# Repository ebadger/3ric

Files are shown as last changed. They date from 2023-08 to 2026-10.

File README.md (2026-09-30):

<h1 align="center">3ric</h1>

<p align="center">
  <strong>A from-scratch, Apple-II-class 65C02 personal computer — real hardware plus a
  cycle-honest emulator that also runs in your browser.</strong>
</p>

<p align="center">
  
  
  
  
  
  
  
</p>

---

## ▶ Try it now — no install, no account

**[Built from Bits: the Hackaday showcase](https://ebadger.github.io/3ric/hackaday.html)**
is a one-minute tour of the machine: a hi-res starfield, 16-color plasma, a rotating
wireframe, and an original six-voice stereo chiptune, all running as real 65C02 code.
[Run and remix the demo](https://ebadger.github.io/3ric/index.html?src=programs/hackaday.s)
at **1x**, then click the emulator for sound. Use **1-4** for scenes, **Space** to pause,
**M** to mute, and **Q/Esc** to return to the monitor. Source and `.PRG` / `.woz`
exports are available in the editor; the program targets 3RIC, not an unmodified Apple II.

**<https://ebadger.github.io/3ric/>** runs the *entire machine* client-side via
WebAssembly. Click the canvas and start typing at the monitor `*` prompt. Then:

- **Boot Disk** — boot the demo 5.25″ floppy (a self-booting machine-code disk).
- **Mount SD** — mount the micro-SD card and use the ROM's DOS shell (`DIR`, etc.).
- **Assemble & Run** — open the built-in 65C02 editor, write assembly, and run it like
  `BRUN` — all in the browser. Programs are shareable via a `?src=` deep link.

<!-- TODO(media): drop an animated GIF of the emulator booting + a program running here,
     e.g. ![3ric booting](docs/media/hero.gif). Keep it < ~5 MB for fast README loads. -->

## What is 3ric?

3ric is a personal *learn-by-building* project: an 8-bit computer designed at the chip level
— KiCad schematics, a custom PCB, and 74-series address-decode logic — paired with a C++
emulator of the exact same machine. The emulator compiles to WebAssembly, so the **same VM
core** that models the real hardware also boots the unmodified 512 KB ROM in any browser.
The whole journey is documented in a [YouTube build series][youtube].

> **Why it exists:** to understand, build, document, and demonstrate how an Apple-II-class
> computer works end to end — and to let anyone poke at it with zero friction. See
> [`docs/MISSION.md`](docs/MISSION.md).

## Features

- **65C02 CPU** with a faithful memory map and soft switches, adjustable clock speed.
- **Video**: 40×24 text, lo-res, and hi-res color, rendered to a canvas.
- **Input & I/O**: keyboard (`$C000`/`$C010`), 6551-style ACIA serial, 6522 VIA.
- **Disk II 5.25″ floppy** via `.woz` images (self-booting machine-code disks).
- **Micro-SD storage**: a bit-banged SPI FAT32 card with a ROM DOS shell.
- **In-browser 65C02 assembler/editor** — assemble & run, download a `.PRG`, share `?src=`
  links; ships ~11 sample programs.
- **AI-generated 6502 games** (STAR DUEL, Snake, Life, Minesweeper, 2048, Star Swarm, and more) built
  through the project's own codegen pipeline — see [`emulator/AICodeGen/`](emulator/AICodeGen/).
- **Runs everywhere the same way**: one shared C++ VM core drives both the native Windows
  build and the browser (WebAssembly) build.

## Write your first program in the browser

1. Open the [live emulator][demo] and pick a sample from the editor's program menu.
2. Edit the assembly, hit **Assemble & Run**, and watch it execute on the machine.
3. Use **Download .PRG** to save it, or copy the `?src=` link to share the exact program.

Prebuilt samples live in [`web/programs/`](web/programs/); their source and design notes
are under [`emulator/AICodeGen/`](emulator/AICodeGen/) and [`codegen/`](codegen/).

## Build from source

Full, current instructions are in [`status/SYSTEM-STATUS.md`](status/SYSTEM-STATUS.md).

**Native emulator (Windows):** open `emulator/Badger6502VM.sln` in Visual Studio 2022 and
build/run the `Console` or WinUI (`Badger6502Emulator`) host.

**Browser / WebAssembly build** (emsdk 6.0.1, Node, Python 3):

```powershell
pwsh web/build.ps1     # Emscripten -> web/badger6502.js + .wasm, stages data/
pwsh web/serve.ps1     # serves http://localhost:8011/index.html
```

**Verify it's healthy** (headless smoke tests — no WASM build needed for the first one):

```powershell
$node = "C:\Users\ebadger\emsdk\node\22.16.0_64bit\bin\node.exe"
& $node codegen/tools/asm6502.test.mjs   # assembler encoding tests
& $node web/test_boot.cjs                # ROM boots to a sane state
```

## How it works

```mermaid
flowchart TD
    ROM["6502 ROM + software<br/>(badger6502.bin, fontrom.dat, .s / .prg)"]
    VM["Emulator core — 65C02 VM in C++<br/>(WozLib floppy · MockMicroSD · video/keyboard/ACIA/VIA)"]
    NATIVE["Native hosts<br/>(Windows / Console)"]
    WASM["Emscripten bridge → WebAssembly"]
    BROWSER["Browser client (index.html)<br/>→ GitHub Pages"]
    CODEGEN["Codegen<br/>(asm6502 + headless harness)"]
    HW["Hardware<br/>(KiCad · 74-series logic · logisim)"]

    ROM --> VM
    VM --> NATIVE
    VM --> WASM --> BROWSER
    CODEGEN -->|assembles & tests on the same VM| VM
    HW -. mirrors the same memory map .-> VM
```

The **memory map is a shared contract**: `emulator/Badger6502VMLib/vm.h` is mirrored by the
hardware decode schematic, the web bridge, and the codegen platform reference. The architecture and
each layer are documented in [`specs/`](specs/) — start with
[`specs/SYSTEM.md`](specs/SYSTEM.md).

## Repository layout

| Path | What's there |
|---|---|
| [`emulator/`](emulator/) | C++ 65C02 VM core, WozLib, MockMicroSD, native hosts, ROM data, AI codegen programs |
| [`web/`](web/) | Emscripten bridge, browser client, in-browser assembler, Pages build/deploy |
| [`codegen/`](codegen/) | `asm6502` assembler, `run6502`/harness, platform-ref generation |
| [`specs/`](specs/) | Layer specifications (the source of truth — specs before code) |
| [`status/`](status/) | How to build/run/verify; current state and known gaps |
| [`docs/`](docs/) | Mission, workflow rules & learnings, roles |
| [`kicad/`](kicad/), [`logisim/`](logisim/), [`diylayout/`](diylayout/), [`schematic_pdf/`](schematic_pdf/) | Hardware: schematics, PCB, 74-series address decode, digital-logic models |
| [`22v10/`](22v10/) | Historical intermediate GAL experiments; replaced by 74-series logic in the final build |
| [`romgen/`](romgen/), [`scripts/`](scripts/), [`test/`](test/) | ROM assembly tooling, dev/CI scripts, tests |

## Known gaps

- **DOS 3.3 / Applesoft disks don't run.** This clone's `$E000` BASIC is generic Microsoft
  BASIC, not Applesoft, so games that chain through an Applesoft auto-run greeting won't
  boot. Self-booting machine-code disks work.

## Contributing

Contributions and experiments are welcome — especially new 6502 programs for the gallery.

**Add a program (the easy path).** No C++, no local build: have an AI coding tool write a
65C02 program by pointing it at [`llms.txt`](https://ebadger.github.io/3ric/llms.txt), test it
in the [browser editor][demo], and open a one-file pull request to the
[Community Gallery](https://ebadger.github.io/3ric/gallery.html). Step-by-step, with a
copy-paste prompt: **[`CONTRIBUTING.md`](CONTRIBUTING.md)**.

**Change the machine itself.** A few house rules keep it trustworthy:

- **Specs before code.** Update the relevant spec in [`specs/`](specs/) in the same change.
- **Trace every layer** a change touches (ROM/software → C++ VM core → web bridge/WASM), and
  keep the **native and browser builds behavior-identical**.
- **Open a PR** — changes land via pull request, not direct pushes to `main`.

The full workflow rules live in [`docs/LEARNINGS.md`](docs/LEARNINGS.md); bug reports use the
templates under [`.github/ISSUE_TEMPLATE/`](.github/ISSUE_TEMPLATE/).

## The build series

3ric is built in public. Watch the design and construction, episode by episode:
**[YouTube build series][youtube]**.

The [porting logs](docs/porting-logs/README.md) tell the software side of that story:
A2Robots, Spy vs Spy, Spy Hunter, and Pitfall II, with the changes, failed experiments,
hardware evidence, and lessons for future sessions.

## Support

If this project helps you learn or you just enjoy the build, please consider
**[sponsoring it on GitHub][sponsor]** — or use the **Sponsor** button at the top of this
repository (see [`.github/FUNDING.yml`](.github/FUNDING.yml)). Sponsorship funds parts,
boards, and more build videos, and **every sponsor is credited in
[`BACKERS.md`](BACKERS.md)**.

## License

3ric is **dual-licensed**:

- **Software** — [MIT](LICENSE).
- **Hardware designs & documentation** — [Creative Commons Attribution-ShareAlike 4.0
  International](LICENSE-CC-BY-SA-4.0.txt).

Bundled third-party components keep their own licenses, and some bundled data (the ROM's
Microsoft BASIC, Apple II disk images used as test fixtures) is third-party copyrighted
material **not** licensed by this project. See [`NOTICE`](NOTICE) for the full breakdown
before redistributing.

[demo]: https://ebadger.github.io/3ric/
[youtube]: https://www.youtube.com/playlist?list=PLbYLt1iawSBLK4w46Kn7cxxuoeVt7Zepq
[sponsor]: https://github.com/sponsors/ebadger

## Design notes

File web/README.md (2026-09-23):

# 3RIC Studio — 65C02 emulator and editor in the browser (WebAssembly)

This folder powers **3RIC Studio**, the browser-based emulator, editor, gallery, and
learning hub for the `3RIC` Apple-II-class 65C02 computer. It compiles the existing C++
VM core
(`emulator/Badger6502VMLib`) and disk library (`emulator/WozLib`) to WebAssembly,
boots the real 512KB ROM, renders Apple-II text/hi-res/lo-res video to an HTML
`<canvas>`, feeds keyboard and gamepad input through the machine's hardware paths,
and plays both the `$C030` system speaker and slot-4 dual-AY Mockingboard through
Web Audio.

The VM peripherals remain in the shared C++ core so native and WASM builds behave
identically. Browser-only presentation code stays in the bridge and JavaScript.

## What works

- Boots the unmodified `badger6502.bin` ROM to the monitor.
- Hi-res color, lo-res color, and 40×24 text rendering — ported verbatim from
  the WinUI host renderer (`MainWindow.xaml.cpp`) into the bridge so the color /
  fringe logic is identical.
- Keyboard input via the Apple-II `$C000` / `$C010` strobe mechanism, including a
  collapsible touch keyboard matching the 1983 Apple IIe layout (minus Reset and
  both Apple keys) for phones.
- **Two gamepads** through the standard browser Gamepad API. USB and Bluetooth
  devices use the same path after OS pairing; the shared VM serializes them as real
  SNES pads through VIA1 and the unmodified ROM fills `GAMEPAD1/2`.
- **Micro-SD card** (bit-banged SPI through VIA1) backing a FAT32 disk image. A
  **Mount SD** button drops into the ROM's DOS shell (`>` prompt) and lists the
  card; from there `DIR`, `CAT`, `CD <dir>`, `BLOAD`/`BRUN <file>` all work.
- **Disk II 5.25″ floppy** emulation (WozLib) through the standard boot ROM at
  `$C600`. A **Boot Disk** button boots the bundled `.woz`, and **Insert .woz…**
  boots any WOZ image you pick. Self-booting machine-code game disks run into
  their hi-res title; DOS 3.3 / Quick-DOS disks don't (this clone has no
  Applesoft for their auto-run greeting — see below).
- **Adjustable CPU clock** (**Speed** selector): 0.5× / 1× (≈1.57 MHz, native) /
  2× / 4× / 8× / Max, with a per-frame wall-clock cap so the page stays responsive.
- **3RIC audio**: the mono `$C030` system speaker is centered and mixed with two
  AY-3-8910s at `$C400/$C480`, clocked directly from 1.5734375 MHz PHI2 and
  hard-panned stereo. Sound is enabled by default; the first pointer or keyboard
  interaction creates the browser audio context, and **Disable Sound** opts out.
  Audio plays at 1× and pauses at other speed settings while the emulated latch
  and chips continue to advance.
- **In-browser assembler** (**Assemble & Run**): edit 65C02 source in the page,
  assemble it client-side with the very same assembler the CLI uses
  (`codegen/tools/asm6502.mjs`), run the resulting image like **Load .PRG**, and
  download the `.PRG`. Ships the project's sample programs; deep-linkable with
  `?src=` / `?code=`, and a **Share** button that copies a one-click link to the
  current program.
- **Source debugger**: instruction breakpoints on the assembled source listing,
  pause/continue, step into/over, live registers, arbitrary-address breakpoints, and
  raw-memory inspection. PCs in the ROM are correlated to ca65 symbol and
  source-file/line metadata from `badger6502.dbg`.

## Layout

| File | Purpose |
| --- | --- |
| `web_bridge.cpp` | embind bridge: wraps `VM`, exposes load/run/keyboard/gamepad/registers/audio, drives the SD card, and produces the RGBA framebuffer. |
| `gamepad.js` | Dependency-free standard-layout browser controller mapping and stable two-player assignment. |
| `virtual-keyboard.js` | Touch-keyboard layout, one-shot Shift/Control state, physical-key mapping, and DOM renderer. |
| `debugger.js` | Dependency-free assembled-source mapper and ca65 `.dbg` parser for ROM symbol/file:line correlation. |
| `emulation-clock.js` | Elapsed-time cycle pacer that keeps finite CPU speeds independent of display refresh rate and carries instruction overshoot between frames. |
| `audio-worklet.js` | Stereo PCM queue on the browser audio-rendering thread; no `SharedArrayBuffer` or cross-origin isolation required. |
| `web_compat.h` | Tiny shims so `WozLib` + `MockMicroSD`'s MSVC-isms (`OutputDebugString`, `sprintf_s`, `swprintf_s`, `fopen_s`, `_ASSERT`, …) compile under Emscripten. |
| `make_sd_sparse.py` | Streams `emulator/Data/sd.zip` (a 2GB, mostly-zero FAT32 image) into a compact `data/sd.sparse` keeping only the ~11.5MB of non-zero sectors. |
| `build.ps1` | Compiles the core + WozLib + MockMicroSD + bridge to `badger6502.js` / `.wasm`, stages the data files, generates `sd.sparse`, and stages the demo `disk.woz`. |
| `index.html` | Canvas UI + `requestAnimationFrame` driver + keyboard + clock-speed/disk/sound controls + the in-browser assembler/editor/debugger. Honors an optional `ASSET_BASE` (R2/CDN offload). |
| `challenges.html`, `challenges.css` | Static introduction to the public model challenges and first TTS round. |
| `challenges/tts/index.template.html` | Template for the complete TTS brief, kickoff task, submission guide and entries; generated from `codegen/challenges/tts/v1/`. |
| `challenge-copy.js` | Optional clipboard enhancement with visible manual-copy fallback. |
| `asm6502.mjs` | The 65C02 assembler, staged from `codegen/tools/asm6502.mjs` (git-ignored). Dual-use: the same file is a Node CLI and a browser ES module — `index.html` imports its `assemble()` for **Assemble & Run**. |
| `serve.ps1`, `serve.py` | Static loopback-only server (default port 8000; `-Port 8011` to override), with explicit ES-module/WASM MIME types. |
| `Caddyfile` | Production static server config (compression + cache headers) for hosting behind a Cloudflare Tunnel. |
| `test_*.cjs` | Headless Node validations (boot, render, input, audio, screen decode, SD, disk). |

Build outputs (`badger6502.js`, `badger6502.wasm`), the staged `data/` copies,
and the editor's staged `asm6502.mjs` + `programs/*.s` sample sources are
git-ignored; regenerate them with `build.ps1`.

## Model challenges

`challenges.html` introduces the series; `challenges/tts/` and its versioned `v1/`
page contain the full 3RIC Talks brief and submission guide without requiring JS.
The canonical text lives under `codegen/challenges/tts/v1/`, not in generated HTML.
`node codegen/tools/build-challenges.mjs` stages the pages, raw prompt, exact launch
SHA and approved source/download links. The launch SHA is the commit that first added
the versioned prompt; publication requires full Git history (`fetch-depth: 0`).
Later entry commits do not move it. Changes to the frozen prompt/guide/metadata require
a new version, not silent edits.

Before the initial foundation commit, `build.ps1 -PreviewChallenges` (or the generator's
`--preview`) permits explicitly labeled local drafts. This is not an official run baseline.
After commit, use the ordinary production build. The generator never invents entries
or recordings; no entries means a visible empty state. `check-tts.mjs --all` produces
recordings/reports, then rerun the generator to stage matching successful captures.
Run `node codegen/tools/challenges.test.mjs`, `node codegen/tools/tts-entry.test.mjs --runtime`
and `node web/test_challenges.mjs` for the publication/tooling checks.

Models submit source in independent entry directories/PRs. The read-only PR workflow
uploads PRG/WAV/check artifacts for inspection; only maintainer-merged code is published
by Pages. Captured PCM is not intelligibility, AY-only or physical-hardware verification.
See the [submission guide](../codegen/challenges/tts/v1/SUBMITTING.md).

## Prerequisites

- **emsdk 6.0.1** (x86_64). On Windows, the default location is
  `%USERPROFILE%\emsdk`; set `$env:EMSDK` to use another installation. The build
  invokes `em++.exe` or `em++.bat` by full path after sourcing `emsdk_env.bat`
  in the same `cmd` process. Installing a version is not the same as activating it.
- **Node 22 or newer on PATH**, for challenge staging and headless tests.
- **Python 3** for serving (sets the `application/wasm` MIME type; `.wasm` must
  be served over http, not `file://`).

## Build

```powershell
cd web
.\build.ps1
```

This compiles these sources with `-DPLATFORM_WEB`:

```
Badger6502VMLib: vm cpu Instructions acia via snesgamepads ay38910 mockingboard PS2Keyboard badgervmpal
WozLib:          DriveEmulator WozDisk WozFile
MockMicroSD:     SDCard MappedFile
bridge:          web_bridge.cpp
```

`symbols.cpp` and `Disassemble.cpp` are excluded (Windows-only). Key flags:
`-std=c++17 -O2 -lembind -sMODULARIZE=1 -sEXPORT_NAME=createBadgerVM
-sALLOW_MEMORY_GROWTH=1 -sENVIRONMENT=web,node`. The data files
(`badger6502.bin`, `fontrom.dat`, `badger6502.dbg`) are copied from
`emulator/Data` into `web/data`, `sd.sparse` is generated from
`emulator/Data/sd.zip` (first run only; ~20s), and the demo `disk.woz` is staged
from the in-repo WOZ test images.

## Run in the browser

```powershell
cd web
.\serve.ps1            # python -m http.server 8011
```

Open <http://localhost:8011/index.html>, click the canvas and type, or expand
**Virtual Keyboard** below the screen to use its full symbol and arrow layout on a phone.
Press **Boot Disk** to boot the bundled 5.25″ floppy, or **Insert .woz…** to boot one
of your own WOZ images. Press **Mount SD** to mount the micro-SD card and enter
the DOS shell — it runs the monitor command `EC5CG` (Go to `$EC5C`, the `dos`
routine) which mounts the FAT32 image and prints a `>` prompt, then auto-runs
`DIR`. Type `CAT`, `CD <dir>`, `BRUN <file>`, etc. to load games and programs
from the card. The **Speed** selector sets the CPU clock (0.5×–8× or Max).
The system-speaker and stereo Mockingboard mix is enabled by default. Browser
autoplay rules delay it until the first pointer or keyboard interaction; press
**Disable Sound** to opt out. Sound is intentionally generated only at native 1×.

> Port 8011 is used because 8000 is taken on this machine.

## Browser gamepads

Pair a Bluetooth controller in the operating system, or connect one over USB, then
press a controller button after opening the page. The browser may not expose a pad
until that first input. The header assigns the first two connected devices to stable
**P1** and **P2** slots and releases every button immediately on disconnect.

Standard-layout face buttons map to SNES B/A/Y/X, Select/Start map to the center
buttons, either bumper or trigger maps to L/R, and the D-pad or left stick controls
directions (0.5 deadzone). Games read the normal ROM `PTRIG` and `GAMEPAD1/2`
interface; JavaScript does not bypass the VIA or ROM scan.

## SUNSLING

Pick **SUNSLING** in the Gallery or the assembler's **Hi-res** group, or open
`index.html?src=programs/sunsling.s`. This is a separate original 65C02 game;
STAR DUEL remains available unchanged. Run at **native 1x** and press **Enter**
or a controller's **Start** to launch a two-player match. First to five wins;
simultaneous final kills can produce a draw.

| Action | Keyboard P1 | Keyboard P2 | Each SNES pad |
|---|---|---|---|
| Rotate | A/D or Left/Right | J/L | Left/Right |
| Burn / coast | W / S or Up / Down | I / K | Hold / release Up or B |
| Fire | F or Space | U | Hold A or Y |
| Hyperspace | E | O | Fresh Select press |

**Keyboard burn stays on until Coast is pressed.** The hardware keyboard supplies
characters, not held-key/key-up state; explicit throttle latches let both pilots
keep accelerating while steering or firing independently. Each fire key starts
a short burst; repeated presses extend it. Momentum persists when coasting.
Standard USB/Bluetooth controller face-button positions map through the existing
SNES interface: bottom=B, right=A, left=Y, top=X.

P1 starts on the left in a delta ship; P2 starts on the right in a forked ship.
The sun attracts both ships and torpedoes; thrust tangentially to swing around it.
The arena wraps on both axes. Each pilot has four live torpedo slots, and a shot
inherits the ship's velocity. A sun crash or enemy hit awards the opponent a point.
Respawn shields blink briefly and block enemy contact, **not the sun**.
Hyperspace relocates to the safe outer arena; the HUD's `H:READY`/`H:WAIT` indicates
its eight-second recharge. `T:+` means the engine is burning.

**P** or a fresh **Start** pauses/resumes. **Enter/Start** rematches after a win.
**M** mutes effects; **Q/Esc** restores the monitor. Sound uses the actual `$C030`
speaker and needs the browser's usual first interaction. There is no host-side
physics or drawing.

Canonical source: `codegen/programs/sunsling.s`. **Download .PRG** produces a raw
image for `BRUN SUNSLING.PRG 0800`; **Download .woz** makes a bootable disk using
the existing exporter. To assemble a local card image:

```powershell
node codegen\tools\asm6502.mjs codegen\programs\sunsling.s codegen\programs\sunsling.prg
node codegen\tools\sunsling.test.mjs
```

The guest is exercised on the real WASM core, not a substitute JavaScript physics
model; a hardware-compatible binary is not a claim of physical-board testing.

## 3RIC Groovebox

Open **3RIC Groovebox** in the Gallery or the assembler's **Music** sample group.
It plays an original 16-step demo through both Mockingboard AY chips: bass, lead, and
arpeggio on the left; kick, snare, and hi-hat on the right. The sequencer, editor,
envelopes, and controller handling are all 65C02 code in
`codegen/programs/groovebox.s`, using the actual VIA/AY register protocol.

Keep the emulator at **native 1x**, and click the canvas or press a keyboard key once
to activate browser audio. A gamepad press alone may expose the controller but does
not satisfy the browser's audio-activation requirement. Use the controller assigned
to **P1**. The on-screen controls use **SNES** button names:

| Action | SNES pad | Keyboard |
|---|---|---|
| Select voice / step | D-pad or left stick | Arrows or WASD |
| Enable / disable step | A (east face button) | Space |
| Raise / lower note | B / Y (south / west) | `+` / `-` (`=` also raises) |
| Mute / unmute voice | X (north) | M |
| Cycle Pluck / Soft / Long envelope | Select / Back | I |
| Stop / restart from step 1 | Start | Return |
| Decrease / increase tempo | L / R (bumper or trigger) | `[` / `]` |
| Silence and return to monitor | -- | Q |

The D-pad repeats after a short hold; other pad actions need a fresh press.
The inverse cell is the editor cursor, the moving `>` is the playback position,
and the rightmost digit shows each voice's current volume. Muted tracks show `M`.
Disabled steps retain their notes. Note edits enable a step and clamp to two octaves;
the hat instead edits noise period `N01`-`N24`. While stopped, enabled and unmuted
note/step/envelope edits audition the selected voice.

The snare and hat share the right chip's single noise generator, so a hat's noise
period also affects an overlapping snare. Timing comes from Mockingboard Timer 1,
not browser animation frames. **Edits live only in emulated RAM:** reloading the
program restores the demo, and Share / Download export the source program, not a
live recording of edited steps. Edit `demo_steps` in the source to share a new
starting pattern. **Download .PRG** can run on 3RIC hardware with
`BRUN GROOVEBOX.PRG 0800`.

After `web/build.ps1`, run `node codegen/tools/groovebox.test.mjs` from the repository
root for the focused sequencer, controller, timing, and real-PCM checks.

## In-browser assembler (Assemble & Run)

The page includes an **Assembler** panel that assembles 65C02 source entirely in
the browser and runs it in the emulator — no CLI, no server round-trip:

1. **Pick a sample** — hi-res games/demos (SUNSLING, STAR DUEL, STAR SWARM, ROCK STORM, JUNGLE QUEST, Matrix Rain),
   lo-res games (SNAKE, Conway's Life), text-mode games (Block Drop, Paddles,
   Brick Buster, 2048, Minefield), 3RIC Groovebox (music), or Hello (serial) — or type
   your own source into the editor.

2. **Assemble & Run** (button or <kbd>Ctrl</kbd>+<kbd>Enter</kbd>) assembles the
   source and loads the image exactly like **Load .PRG** (`BRUN` on hardware).
   Assembler errors show as `line N: …` and are non-fatal.
3. **Download .PRG** saves the assembled image so you can `BRUN` it on real
   hardware or off the SD card. **Download .woz** packages the same image as a
   bootable floppy for monitor command `C600G` after inserting the image.
   If the ROM shows the DOS `>` prompt, enter `MON` first.
4. Expand **Debugger** to click instruction rows as breakpoints, pause/continue,
   step into or over an absolute `JSR`, add a breakpoint by address, and inspect
   128 bytes of memory from any hexadecimal address.

**Matrix Rain** is a full-screen falling-character demo written entirely in 6502
assembly. Open [`?src=programs/matrix.s`](https://ebadger.github.io/3ric/?src=programs/matrix.s)
at native **1x** speed; **Space** pauses/resumes and **Q** or **Esc** returns to the
monitor. Its source lives in `codegen/programs/matrix.s` and is also featured in the
Community Gallery.

Implementation notes:

- The assembler is the project's own `codegen/tools/asm6502.mjs`, made *dual-use*:
  its CLI tail is guarded by a `process`/`node` check and its lone `node:url`
  import is dynamic, so the exact same file runs as a Node CLI **and** imports
  cleanly as a browser ES module. `index.html` lazily `import()`s its `assemble()`.
- A source's own `.org` / `*=` is authoritative; the **org $** field is only used
  when the source has no origin directive (passing both would corrupt the layout).
- Bootable WOZ exports require a page-aligned load address at or above `$0800`.
  The page-padded image plus one staging page must fit below `$9000`: at `$0800`,
  up to **34,560 bytes** are supported, including the 32,256-byte Astra: Copper
  Voice TTS image. The loader stages one page above the destination, then copies
  forward safely through the overlap. `build.ps1` stages the canonical
  `codegen/tools/wozgen.mjs`; `node web/test_woz_download.cjs` verifies actual Disk II
  boots, full payload bytes, padding and size limits. A successful boot does not
  establish Apple II compatibility, speech intelligibility or physical-board operation.
- The editor autosaves to `localStorage`, and any program is deep-linkable. The
  **Share** button copies a self-contained link to the current program: an
  unmodified built-in sample links as the short `?src=programs/<name>.s` (fetches
  that source, fills the editor, auto-runs); edited or hand-written source is
  embedded inline as URL-safe base64 in `?code=`. Either link carries `&org=<hex>`
  when the source has no `.org` directive. Opening a `?src=`/`?code=` link auto-runs
  it and shows a "remixing a shared program" banner. No server is involved — the
  link is the whole payload, so very large sources make long `?code=` links.
- `build.ps1` stages `asm6502.mjs` and every `codegen/programs/*.s` plus the ten
  `emulator/AICodeGen` sample sources into `web/` and `web/programs/` (git-ignored,
  regenerated each build; CI does the same before publishing).
- `assemble()` listing records carry the emitted PC/bytes, one-based source line,
  and instruction/data kind. Breakpoint checks remain in the C++ `WebVM` loop so
  normal and Max-speed execution do not cross the JS/WASM boundary per instruction.
  The ROM `.dbg` map is fetched only when the debugger is opened; the source files
  named by that map are not in this repository, so the UI shows their file/line
  coordinate rather than the ROM source text.

## Community Gallery

`gallery.html` is a lightweight, WASM-free showcase of programs written for 3RIC,
linked from the emulator header. It fetches the committed **`gallery.json`** manifest
and renders one card per program; each card's **&#9654; Run & Remix** button is just a
`?src=`/`?code=` deep link into `index.html`, so a click loads the source into the
editor, auto-runs it, and shows the remix banner — no separate storage or server.

`gallery.json` is the single source of truth (a `{ "version", "entries": [...] }`
document). Each entry has:

| field | required | notes |
|---|---|---|
| `title` | yes | shown as the card heading |
| `mode` | no | badge text, e.g. `Hi-res` / `Lo-res` / `Text` / `Serial` |
| `description` | no | one- or two-line blurb |
| `author`, `authorUrl` | no | credit; `authorUrl` is linked only when `http(s)` |
| `tags` | no | array of short labels |
| `src` **or** `code` | yes | run target: a `programs/<name>.s` path, or an inline URL-safe base64 program (paste the `?code=` value from a Share link) |
| `org` | no | hex load address, only when the source has no `.org` directive |

The page builds every card with `textContent` (never `innerHTML`) and only ever
produces `index.html?…` links, so a manifest entry can't inject markup or a
`javascript:` URL.

**Add your program:** drop the `.s` into `codegen/programs/` (every `*.s` there is
staged into `web/programs/` automatically) and append an entry to `gallery.json`,
then open a pull request. The gallery's *Add your program* card links straight to
GitHub's in-browser editor for `gallery.json`.

**Contribute with AI:** `llms.txt` (staged to the site root) is a machine-readable brief that
hands any AI coding tool the 65C02 dialect, entry/exit rules, a worked example, and the gallery
submission flow in a single fetch — <https://ebadger.github.io/3ric/llms.txt>. The repo-root
[`CONTRIBUTING.md`](../CONTRIBUTING.md) has a copy-paste prompt and both submission paths, and
the gallery's *Make one with AI* card links to it.

## Headless tests (fast iteration)

```powershell
$node = "C:\Users\ebadger\emsdk\node\22.16.0_64bit\bin\node.exe"
& $node web\test_boot.cjs        # ROM boots, sane PC, video RAM written
& $node web\test_render.cjs      # framebuffer has lit pixels
& $node web\test_keyboard.cjs    # monitor echoes typed commands
& $node web\test_screen_text.cjs # decode the text screen to ASCII
& $node web\test_emulation_clock.cjs # 1x timing at 60/120/144 Hz displays
& $node web\test_sound_default.cjs # default-on UI + first-gesture activation
& $node web\test_audio_pacing.cjs # real WASM PCM rate at 60/144 Hz displays
& $node web\test_audio_worklet.cjs # prebuffer + bounded PCM queue
& $node web\test_mockingboard.cjs # mirrors, stereo PCM, 3RIC clock, timer IRQ
& $node web\test_system_speaker.cjs # $C030 read/write toggles + mixed PCM
& $node web\test_gamepad.cjs    # mapping, VIA serialization, ROM GAMEPAD1/2 scan
& $node web\test_debugger.cjs   # source map, ROM lookup, breakpoints, step-over
& $node web\test_sd.cjs          # mount the SD card + DIR lists the FAT32 root
& $node web\test_disk.cjs        # boot a WOZ floppy via C600G into a hi-res title
```

## ROM load recipe (mirrors the WinUI host)

1. Write the first `0x10000` bytes of `badger6502.bin` into `VM::GetData()`
   (`loadData(0, bytes)`) — provides the reset vector at `$FFFC` and ROM/OS at
   `$D000-$FFFF`.
2. `seedBasicRom()` — `memcpy(GetBasicRom(), &GetData()[0x9000], 0x3000)`.
3. `loadFont(fontromBytes)` — used by the text renderer.
4. `reset()` — loads PC from `$FFFC/$FFFD`.

The CPU is driven cooperatively: each animation frame calls `run(maxSteps)`,
which calls shared `VM::Step()` to sample IRQ and tick the onboard VIA plus both
Mockingboard VIA/AY pairs and the combined PCM mixer per returned cycle, then
advances keyboard plumbing (the blocking `VM::Run()` is never used).

## How the micro-SD card works

The card is a bit-banged SPI device wired to VIA1's port-A register, exactly like
the WinUI host (`MainWindow.xaml.cpp`). Each CPU write to `$C201`/`$C20F` clocks
the SD state machine (`emulator/MockMicroSD/SDCard.cpp`): `CS`=bit4, `SCK`=bit3,
`MOSI`=bit2, and the resulting `MISO` drives the VIA's external port-A bit1
input. The bridge installs this pump via `VM::CallbackWriteMemory`.

The disk image (`emulator/Data/sd.zip`) decompresses to a **2GB** FAT32 image
that is almost entirely zeros — far too large to fetch or allocate in a browser.
`make_sd_sparse.py` streams it straight out of the zip and emits only the
~23k non-zero 512-byte sectors as `data/sd.sparse` (~11.5MB, an `SDSP`
container). The Emscripten branch of `MMappedFile` (`MockMicroSD/MappedFile.cpp`)
backs the 2GB logical image with a lazily-allocated `unordered_map<sector,
512 bytes>`; never-written sectors read back as zero.

At runtime the page lazily fetches `sd.sparse`, hands it to `loadSD()`
(`SDCard::LoadSparseImage`), and the ROM's own FAT32 driver (`fat32_start` →
`fat32_dir`) reads the card over SPI. `test_sd.cjs` proves the round trip: it
enters the shell, runs `DIR`, and asserts real `<DIR>` folders and `PRG` files
come back along with a non-zero sector-read count.

## How the Disk II floppy boots

The 5.25″ drive is the WinUI host's `WozLib` emulator (`DriveEmulator` +
`WozDisk` + `WozFile`), already embedded in `VM`. The CPU reaches it through the
standard hardware path: the Disk II boot PROM lives at `$C600` (part of the ROM
image), and the data registers at `$C0E0-$C0EF` route to `DriveEmulator` via
`VM::DoDisk`. The bridge advances the drive on every `$C0E0-$C0EF` access
(`AddCycles(elapsed)`), exactly like the host.

`insertDisk(drive, bytes)` writes the WOZ bytes to Emscripten's in-memory
filesystem and calls `WozDisk::InsertDisk(path)` (the loader reads through a
`FILE*`, which MEMFS provides) — no changes to WozLib were needed. **Boot Disk**
and **Insert .woz…** re-seed a clean machine, insert the image into drive 1, and
type `C600G` (the monitor "Go" command) to jump to the boot ROM, just like
booting on real hardware.

This clone's `$E000` BASIC is a generic Microsoft BASIC (it prompts
`MEMORY SIZE?`), **not** Applesoft, so disks whose boot auto-runs an Applesoft
greeting — DOS 3.3 / Quick-DOS System Masters, and games that chain through them
— load DOS but then trap to `$0000`. Self-booting machine-code game disks (the
bundled demo and most of the WOZ test images) bring their own code and run fine.
`test_disk.cjs` boots one through `C600G` and asserts it reaches a painted hi-res
screen without trapping.

## CPU clock speed

The frame loop converts elapsed monotonic time to cycle debt at the machine's
native 1.5734375 MHz clock (25.175 MHz VGA dot clock ÷ 16), then calls
`runCycles()` in bounded batches. Whole-instruction overshoot is carried into the
next frame, so 1× remains 1× on 60 Hz, high-refresh, and variable-refresh
displays. Catch-up is bounded and reset after machine resets, speed changes, and
hidden-tab transitions. `Max` runs as many instructions as fit in the same
~12 ms wall-clock budget.

## Hosting on GitHub Pages (zero-cost, public)

Because the emulator is 100% client-side, the repo publishes it straight to
**GitHub Pages** — no server to run. The live site is:

**<https://ebadger.github.io/3ric/>**

Anyone with a browser can open it; **no GitHub account is required**. For a
public repo, Pages hosting and the Actions build are free (soft limits: 1 GB
site, 100 GB/month bandwidth).

`.github/workflows/deploy-pages.yml` does it automatically on every push to
`main` that touches the emulator sources:

1. installs Python + Emscripten (`6.0.1`, matching this project),
2. runs `web/build.ps1` (it detects Linux CI and invokes `em++` directly, and
   stages `asm6502.mjs` + the `programs/*.s` sample sources for the editor),
3. stages `index.html` + `gallery.html` + `gallery.json` + `llms.txt` +
   `badger6502.js` + `.wasm` + `asm6502.mjs` + `data/` + `programs/` as the site root,
4. uploads it as a Pages artifact and deploys.

The build outputs stay git-ignored — CI regenerates them from the committed
sources (`emulator/Data/*`, the demo `.woz`, etc.) each run. To publish from a
fork, enable Pages with the **GitHub Actions** source (Settings → Pages), then
push to `main` or run the workflow manually from the Actions tab. The site is
served under `/<repo>/`, which works because every asset path in `index.html` is
relative.

## Serving in production (Raspberry Pi + Cloudflare)

The emulator is **100% client-side** — the server only hands out static files,
and all 65C02/video/disk emulation runs in the visitor's browser. So a tiny
origin (e.g. a Raspberry Pi behind a Cloudflare Tunnel) can serve a large number
of concurrent users; the only real constraint is bandwidth for *first-time*
downloads, which Cloudflare's edge cache absorbs.

Per fresh visit the mandatory payload is ~1.26 MB (`index.html` + `badger6502.js`
+ `.wasm` + `badger6502.bin` + `fontrom.dat`). `disk.woz` (~230 KB) and
`sd.sparse` (~11.5 MB) are fetched lazily, only when the user clicks **Boot Disk**
or **Mount SD**.

### Caddy (static origin)

Use the included `Caddyfile` instead of the dev `serve.ps1` — it adds gzip/zstd
compression, long cache headers for the immutable assets, and `no-cache` for
`index.html` so rebuilds appear immediately:

```bash
cd web
caddy run --config Caddyfile      # serves :8080
```

Point your Cloudflare Tunnel's public hostname at `http://localhost:8080`.

### Caching the SD image to minimize ISP upload

The `Caddyfile` already sends `Cache-Control: public, max-age=31536000, immutable`
on everything under `/data/` (including the ~11.5 MB `sd.sparse`), so a returning
visitor's **browser** never re-downloads it. To also stop your **Pi** from
re-uploading it to each *new* visitor, let Cloudflare's edge cache it:

1. In the Cloudflare dashboard go to **Caching → Cache Rules** and add a rule:
   - **If** URI Path starts with `/data/` (or matches `*.sparse`), **then** set
     **Cache eligibility → Eligible for cache**, and an **Edge TTL** (e.g.
     "Use cache-control header" since the origin already sends a year, or pin
     "1 month").
   - This rule is *required*: a `.sparse` file is **not** one of the extensions
     Cloudflare caches by default, so without it the edge passes every request
     straight through to your Pi.
2. Verify with `curl -I https://your-host/data/sd.sparse`. After the first
   request you should see `cf-cache-status: HIT` — meaning that download came
   from Cloudflare, not your uplink. (Free/Pro cache objects up to 512 MB, so
   11.5 MB is fine.)

With the rule in place your Pi serves `sd.sparse` roughly **once per Cloudflare
location per TTL** instead of once per visitor. If you change the SD contents,
give the new image a different filename (e.g. `sd.v2.sparse`) and update the
fetch path in `index.html`, otherwise cached copies persist for up to a year.

For the strongest result — `sd.sparse` never touching your home connection at
all — offload it to R2 (next section): zero egress fees, served straight from
Cloudflare's network.

### Offloading the heavy files to R2 (`ASSET_BASE`)

If the optional 11.5 MB `sd.sparse` gets popular, serving it from your home
connection can saturate your uplink (or hit an ISP data cap). `index.html`
supports an **`ASSET_BASE`** that relocates the `.wasm` binary and everything
under `data/` to any CDN — ideally a **Cloudflare R2** bucket (free tier: 10 GB
storage + **zero egress fees**, and policy-clean for large-file distribution):

1. Upload `badger6502.wasm` and the whole `data/` folder to a public R2 bucket,
   preserving paths (so `…/badger6502.wasm` and `…/data/sd.sparse` resolve).
2. Configure the bucket's **CORS policy** to allow your site's origin (or `*`),
   and make sure objects are served with sensible content types — in particular
   `badger6502.wasm` as `application/wasm` for streaming compile.
3. Point the page at the bucket, either by editing the page or at runtime:
   - `window.ASSET_BASE = "https://pub-<hash>.r2.dev";` before the main script, or
   - append `?assets=https://pub-<hash>.r2.dev` to the page URL.

The small `index.html` + `badger6502.js` bootstrap still come from your origin;
everything large comes from R2. Leave `ASSET_BASE` empty to serve everything
locally (the default).

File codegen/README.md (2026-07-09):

# 3ric codegen

Tools for generating 65C02 programs for the **3ric** computer, testing them
headlessly on the project's WebAssembly emulator, and producing a card-ready
`.PRG` you can `BRUN` on real hardware or load in the hosted emulator.

- **[`SPEC.md`](./SPEC.md)** — the design of record (mechanism, `.PRG` format,
  emulator API, validation strategy).
- **[`platform/prompt-system.md`](./platform/prompt-system.md)** — the guide the
  code generator follows: assembler dialect, entry/exit conventions, the loop.
- **[`platform/platform-ref.md`](./platform/platform-ref.md)** — memory map,
  soft switches, zero page, and ROM entry points (generated from the ROM's own
  symbols). Machine-readable copy: `platform/platform-ref.json`.

## Quick start

```sh
# 0. Build the emulator once (produces web/badger6502.js + web/data/).
pwsh web/build.ps1

# 1. Assemble + run + check a program; write the card-ready .PRG.
node codegen/tools/run6502.mjs codegen/programs/hello.s \
    --out codegen/programs/hello.prg \
    --expect-serial "HELLO, 3RIC" --expect-halt brk-monitor
```

`run6502.mjs` prints the captured serial output, the decoded 40×24 text screen,
the final registers, the halt reason, and each check's PASS/FAIL. Exit code is 0
only when the program halted cleanly and every check passed.

## Using the program

- **On hardware / SD card:** copy the `.PRG` to the micro-SD card and run
  `BRUN HELLO.PRG 0800` (the number is the hex load/entry address).
- **In the hosted emulator:** <https://ebadger.github.io/3ric/> → **Load .PRG…**,
  enter the address, pick the file. Or deep-link a hosted program:
  `https://ebadger.github.io/3ric/?prg=programs/hello.prg&org=0800`.

## Tools

| File | Purpose |
| --- | --- |
| `tools/asm6502.mjs` | Dependency-free two-pass 65C02 assembler (`assemble()` + CLI). |
| `tools/asm6502.test.mjs` | Encoding tests for the assembler (`node asm6502.test.mjs`). |
| `tools/harness.cjs` | Boots the WASM emulator, loads a program, runs it, captures serial/text/registers, detects halt. |
| `tools/run6502.mjs` | CLI: assemble/load → run → apply checks → emit `.PRG` + verdict. |
| `tools/gen_platform_ref.mjs` | Regenerates `platform/platform-ref.{md,json}` from `vm.h` + `badger6502.dbg`. |

## Layout

```
codegen/
  SPEC.md
  README.md
  platform/
    prompt-system.md      # generator guide
    platform-ref.md       # generated reference (human)
    platform-ref.json     # generated reference (machine)
  programs/
    hello.s               # demo source (tracked)
    *.prg                 # assembled images (git-ignored; regenerate)
  tools/
    asm6502.mjs  asm6502.test.mjs  harness.cjs  run6502.mjs  gen_platform_ref.mjs
```

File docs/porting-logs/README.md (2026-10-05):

# 3ric porting logs

These are historical engineering notes for getting existing Apple II titles running
on 3ric: what failed, what changed, why an experiment was rejected, and what a future
session can actually rely on. They also preserve the story behind the working images.
The record was assembled on **2026-09-30**, when the owner identified all four titles
below as working on the physical machine.

| Title | Main lesson | Evidence boundary |
|---|---|---|
| [A2Robots](a2robots.md) | Bank-safe keyboard interrupts, native SNES adaptation, and preserving the exact hardware-tested startup profile | Explicit board confirmation of keyboard/menu, Return-to-start, and controller-1 movement; not a full playthrough |
| [Spy vs Spy](spy-vs-spy.md) | A splash-only patch is not a demonstrated fix for an interrupt race | Owner lists it as working on 2026-09-30; earlier detailed coverage is emulator boot/input testing |
| [Spy Hunter](spy-hunter.md) | Refresh software-backed joystick state and never destructively sample its registers | Owner lists it as working on 2026-09-30; earlier detailed coverage is real-ROM emulator testing |
| [Pitfall II](pitfall-ii.md) | Avoid probing the input VIA as a sound card; then separate audio-clock correction from tonal quality | Explicit board confirmation of gamepad control and music with the direct-slot-4 patch; later tuning has separate caveats |

## Current experiments

| Title | Main lesson | Evidence boundary |
|---|---|---|
| [Archon](archon.md) (2026-10-05) | Preserve input interrupts across both language-card banks, and avoid paddle-timer traffic in a digital-controller adapter | Reproducible disk patcher with native PS/2 and WASM board/combat coverage; physical-board confirmation remains open |

## Scope and evidence

This directory is **narrative documentation, not a new specification or a patch
distribution**. It changes no ROM, emulator, hardware, tooling, or game behavior.
The four September logs describe **prior-session evidence**, not tests rerun while
writing those notes. New experiments state their own executed coverage. Calculated pitch errors are not listening
tests, and successful browser input is not proof of a physical PS/2 exchange.

The games and patched images were owner-supplied/local artifacts. No game bytes,
disk images, commercial assets, replacement firmware, or private diagnostic media
are included or offered for download here. Short instruction changes describe the
engineering intervention, not a redistribution of the games.

Historical patchers and runbooks named in the four September logs are **not present
in this checkout**. The newer Archon experiment includes its own patcher and tests,
but neither its original nor patched game image. Local commit IDs identify retained development history;
they may not be reachable from `origin` or available in a fresh clone. They are
intentionally not GitHub commit links. The offsets, transformations, hashes, and
evidence in each log remain useful without those tools.

## Shared machine baseline

The reference ROM is the repository's
[`emulator/Data/badger6502.bin`](../../emulator/Data/badger6502.bin), SHA-256:

```text
fcea03683b77b7f113e6d8f0064ea8edbd6c75b04b472ec5c84de1c3a9f86435
```

That identifies the **canonical file**, not a verified readback of the physical
board's entire installed ROM. No full board-ROM readback was recorded.

| Area | Relevant contract in these investigations |
|---|---|
| Clocks | 3ric CPU/AY: `25,175,000 / 16 = 1,573,437.5 Hz`; Apple II reference: `14,318,180 / 14 = 1,022,727.14 Hz`. Their ratio is approximately `1.538472418`. |
| Physical keyboard | VIA1 at `$C200`: PS/2 clock interrupt on CA2, DATA on PA7, CLOCK on PA6. `$C010` raises the CB1 strobe-clear path. `SEI` does not mask NMI. |
| Controllers | `$C070` raises CB2 for the ROM scan. Controller tables are `$CEE0`/`$CEF0`; the ROM maintains `$C061-$C063` buttons and paddle bit 7 at `$C064-$C067`, with onboard VIA timers providing paddle timing. |
| Serial | ACIA at `$C100` is the serial device, **not** the joystick timer. |
| Sound | The fixed slot-4 Mockingboard uses the two VIAs at `$C400` and `$C480`; these are not the onboard input VIA. |
| Banking | Language-card RAM can hide upper ROM without erasing it. Effective vectors and the bank visible at interrupt entry matter. |
| Browser input | `keyDown` can inject `$C000` directly, bypassing the actual PS/2 receiver, edge timing, and keyboard LED-command exchange. |

The final **74-series KiCad design**, not the historical `22v10` experiments, is the
hardware reference. ACIA, VIA1, and external NMI join CPU NMI; Mockingboard and external
IRQ join CPU IRQ. The VM's `IRQAsserted()` instead groups ACIA with Mockingboard.
That mismatch is a future investigation lead, **not a demonstrated physical cause**
of any failure in these logs.

Current architectural context lives in [SYSTEM](../../specs/SYSTEM.md), the
[platform reference](../../codegen/platform/platform-ref.md), and the
[build/run status](../../status/SYSTEM-STATUS.md). Those describe the current repo;
the title logs pin the historical image and experiment instead.

## Useful habits recovered from the work

- **Preserve the exact accepted artifact.** A renamed file with the same hash is
  the same result; a cleaned-up loader with different bytes is another experiment.
- **Keep addresses in their coordinate system.** Distinguish raw-file offsets,
  loaded addresses, relocated addresses, and decoded physical disk-sector offsets.
- **Exercise the whole input path.** Key injection, pad-table pokes, and a hand-fixed
  RAM image cannot establish that a cold boot and real interrupt traffic work.
- **Use physical evidence to challenge the model.** A failing board outranks a passing
  fixture; a diagnostic that changes startup state can also change the outcome.
- **Separate narrow success from unresolved causes.** Keep rejected images and their
  fingerprints recognizable, without promoting them to approved alternatives.

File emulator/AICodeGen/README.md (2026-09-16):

# AICodeGen

AI-generated programs for the 3ric, one directory per project. Each attempt
records the **prompt** that produced it, the **source**, and the assembled
**binary**, so results stay reproducible and reviewable.

## Layout

```
emulator/AICodeGen/<project>/
  prompt.md     the natural-language prompt given to the model (+ a little metadata)
  <name>.s      65C02 assembly source
  <name>.prg    assembled raw image — load/run with BRUN <NAME>.PRG <org>
```

## Build & test

Programs are assembled and exercised with the toolchain in [`codegen/`](../../codegen)
(a JS 65C02 assembler + a headless emulator harness). For example:

```sh
# assemble a project to its .prg
node codegen/tools/asm6502.mjs emulator/AICodeGen/life/life.s emulator/AICodeGen/life/life.prg --org 0x0800
```

Some projects ship a headless cross-check test (e.g. `codegen/tools/life.test.mjs`)
that validates the assembled program against a JS reference. Programs can also be
published to the hosted emulator by copying the `.prg` into
[`web/programs/`](../../web/programs) and deep-linking `?prg=programs/<name>.prg&org=<org>`.

## Try it in the browser (no install)

The hosted emulator (<https://ebadger.github.io/3ric/>) has an **Assemble & Run**
editor that assembles 65C02 source client-side and runs it in the emulator. Each
project here is a built-in sample in that editor's picker, so you can read, tweak,
re-assemble, and run any of them — then **Download .PRG** to `BRUN` on hardware.
Deep-link a specific source with `?src=programs/<name>.s` (it auto-assembles and
runs). The editor uses the very same assembler as the CLI above
(`codegen/tools/asm6502.mjs`), so results match byte-for-byte.

## Projects

| Project | Description | Load addr |
| --- | --- | --- |
| [`life`](life) | Conway's Game of Life — full-screen lo-res colour, toroidal wrap, **SPACE** reseeds. | `$0800` |
| [`spacewar`](spacewar) | STAR DUEL — two-player mixed-hi-res gravity war: rotate/thrust/fire around a central sun with wrap, SNES pads or a split keyboard, and first-to-5 scoring. | `$0800` |
| [`jungle`](jungle) | JUNGLE QUEST: THE SUNSTONE RUN — six-screen hi-res action-platformer with buffered/coyote jumps, ducking, raised platforms, boulders/snakes/bats, an active vine release, optional fruit, four temple glyphs, checkpoints, and SNES-pad controls. | `$0800` |
| [`rocks`](rocks) | ROCK STORM — original hi-res vector rock-shooter: a rotate/thrust/inertia ship, shots that split drifting rocks, screen wrap, a thrust flame, hyperspace, escalating waves, score/lives, and attract/game-over screens. | `$0800` |
| [`swarm`](swarm) | STAR SWARM — original hi-res fixed-shooter: a formation of aliens that marches, drops, and speeds up while raining bombs, a bottom cannon that fires up, destructible shields, a bonus saucer, escalating waves, score/lives/high score, and attract/game-over screens. | `$0800` |
| [`snake`](snake) | SNAKE — lo-res colour arcade classic: steer a growing snake around a 40×40 playfield to eat food; hitting a wall or yourself ends the game. Arrows/WASD, **SPACE** restarts. | `$0800` |
| [`blocks`](blocks) | BLOCK DROP — original text-mode falling-block stacker: move, rotate, and soft-drop the seven four-cell shapes to clear full rows. **A/D** move, **W** rotate, **S** drop. | `$0800` |
| [`paddles`](paddles) | PADDLES — original text-mode paddle-and-ball tennis against a ball-tracking CPU; first to seven points wins. **W/S** or arrows. | `$0800` |
| [`bricks`](bricks) | BRICK BUSTER — original text-mode brick-breaker: bounce a ball off your paddle to clear rows of bricks across three lives. **A/D** move. | `$0800` |
| [`2048`](2048) | 2048 — slide and merge numbered tiles on a 4×4 grid to build a 2048 tile. Arrows/WASD; a new tile appears after every move. | `$0800` |
| [`mines`](mines) | MINEFIELD — clear a 16×16 grid without detonating a mine; zeros flood-fill and you can flag suspects. Arrows move, **SPACE** reveals, **F** flags. | `$0800` |

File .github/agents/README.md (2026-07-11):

# Agents (`.github/agents/`)

Custom agents are **specialist lenses** you consult for judgment in their domain —
not a hierarchy you route paperwork through. The main session does the work; agents
sharpen specific decisions. **ebadger is the final authority on everything.**

See `docs/ROLES.md` for the lenses-and-gates org model and `docs/CODE-REVIEW-PANEL.md`
for the review-panel procedure.

## What's here

| File | Purpose |
|---|---|
| `template-agent.md` | Minimal agent skeleton + the reusable **anti-sycophancy core**. Start here for any new agent. |
| `template-lens-agent.md` | Richer "C-suite lens" skeleton (Identity → Expertise → Decision Authority → Anti-Patterns). Use for a standing specialist advisor. |
| `gpt-reviewer.md` | Independent code reviewer, pinned to a strong **non-Claude** model. Ready to use. |
| `gemini-reviewer.md` | Independent code reviewer, pinned to a strong **third-vendor** model. Ready to use. |

## The two valuable, reusable ideas

### 1. The anti-sycophancy core
The `## Patterns` block (identical on every agent) turns an agreeable assistant into a
colleague who will tell you you're wrong: claim-tagging (`[KNOWN]`/`[INFERRED]`/`[GUESS]`),
explicit confidence bands, "say 'I don't know' on the first line," and a self-audit of
broken rules. This is the single most portable, highest-value part of the template —
keep it on any agent whose job is judgment.

### 2. Model-diverse review as a standing gate
A single model family has consistent blind spots. The two reviewers run on **different
vendors** and are **structurally read-only** (`tools: ["read","search"]` — no edit, no
shell). Before a code PR ships, both review the diff; the primary agent triages every
finding (fix or cite a reason); ebadger merges. The diversity is the entire value — keep
the two reviewers on different vendors, and update the `model:` pins to the current best
models as they change.

## Adding a new agent

1. Copy `template-agent.md` (simple) or `template-lens-agent.md` (rich) to `your-agent.md`.
2. Fill in `name` and a sharp `description` — the description is what gets the agent
   invoked at the right time, so name the domain **and** what it must NOT be used for.
3. Keep the `## Patterns` anti-sycophancy block.
4. Narrow `tools:` to what the agent actually needs (read-only advisors get `["read","search"]`).
5. Merge to the default branch to make it available.

## Customize for your project

- Update reviewer `model:` pins to the current strongest model from each vendor.
- Build out your own lenses (e.g. Architecture, DevOps, Product, Domain-Expert,
  Process & Learning) from `template-lens-agent.md` as the project needs them — but heed
  the **mission-clock rule** in `docs/ROLES.md`: don't add org machinery faster than the
  product needs it.

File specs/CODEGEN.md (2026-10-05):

# 3ric — Codegen Tooling Spec (CODEGEN.md)

> The Node.js toolchain that assembles 65C02 programs for 3ric, validates them headlessly on
> the WASM emulator, and emits a card-ready `.PRG`. The design of record lives in
> [`codegen/SPEC.md`](../codegen/SPEC.md); this sub-spec is the layer summary + its
> cross-layer contracts. Read `codegen/SPEC.md` before changing the toolchain.

---

## Purpose

Give a program author (human or AI) a fast, deterministic loop: write 65C02 source →
assemble → run on the same emulator the browser uses → assert on serial / text screen /
graphics / registers → produce a `.PRG` that also `BRUN`s on real hardware.

## Contracts / Interfaces

**Tools (`codegen/tools/`):**

| Tool | Role |
|---|---|
| `asm6502.mjs` | Dependency-free two-pass 65C02 assembler (`assemble()` + CLI). **Dual-use:** the exact same file is a Node CLI *and* a browser ES module (the web assembler imports it) — the CLI tail is guarded by a `process`/node check and its `node:url` import is dynamic. |
| `asm6502.test.mjs` | Assembler encoding tests (`node asm6502.test.mjs`) — the fast, no-build gate wired into `pre-push`. |
| `harness.cjs` | Boots the WASM emulator, loads a program, runs it, captures serial/text/registers, detects halt. |
| `run6502.mjs` | CLI: assemble/load → run → apply checks → emit `.PRG` + verdict (exit 0 only if it halted cleanly and every check passed). |
| `gen_platform_ref.mjs` | Regenerates `platform/platform-ref.{md,json}` from `vm.h` + `badger6502.dbg`. |
| `patch-archon.mjs` | Exact-image local WOZ compatibility patcher; see `ROM-SOFTWARE.md`. Contains only adapter code and guarded replacements, never downloads game assets, and refuses input overwrite or fingerprint/sector validation failure. |
| `wozedit.mjs` | Node-only checked WOZ2 sector reading/editing, reusing the dual-use `wozgen.mjs` CRC and 6-and-2 codec. Preserves non-edited bitstream and metadata bytes. |

**Platform reference (`codegen/platform/`)** — the generator's machine/human contract:
`prompt-system.md` (assembler dialect, entry/exit conventions), `platform-ref.md` +
`platform-ref.json` (memory map, including the `$C030` speaker toggle, soft switches, zero
page, ROM entry points). These are
**generated** from the VM — regenerate after any `vm.h` `MM_*` or ROM-symbol change.

**Assembler dialect:** `$hex` / `%bin` / decimal / char literals; labels; directives
`.org`/`*=`, `.byte`, `.word`, `.res`, `.asciiz`; full 65C02 ISA + addressing modes;
zero-page forcing; branch resolution. A source's own origin directive is authoritative.
`assemble()` returns `listing` records for every emitted source statement. Each record
contains its start PC, emitted bytes, one-based source line, and `instruction`/`data` kind;
the browser debugger uses only instruction records as source-breakpoint targets.

**Validation channels** (a program declares which it uses): serial (`drainOutput()`), text
screen (decode `$0400`, 40×24 interleaved), graphics (`renderFrame()` RGBA), CPU/memory
(final `regA/X/Y`, `status`, `peek`). Halt detection: BRK-to-monitor, WAI, idle loop, timeout.

## Behaviour / Rules

- **TTS v1 submissions:** canonical prompt and guide live in `codegen/challenges/tts/v1/`;
  an entrant owns only `submissions/<id>/` (`tts.s`, `entry.json`, `README.md` and optional
  tests/generators). IDs match `[a-z0-9]+(?:-[a-z0-9]+)*`, at most 60 characters. Metadata
  has schemaVersion 1, challenge `tts-v1`, id, title, author, model, agent, baseline (40-hex
  launch SHA), description, assistance, license, memory and limitations (nonempty strings).
  Metadata describes provenance, not independently verified badges.
  `tts-entry.mjs` validates regular files, metadata and assembly at `$0800`, with the raw
  image ending at or below `$C000`. Fixed callable symbols are `TTS_INIT`, `TTS_SPEAK` and
  `TTS_INPUT` (122 reserved bytes in always-mapped application RAM). Init must be callable
  after image load without entering the UI. Speech takes string pointer low byte A/high
  byte X, preserves the string, returns A=0 complete, A=1 cancelled or A=2 invalid input.
  Reserve `$0300-$031F` for the shared check's caller trampoline. Return with upper ROM
  visible. Banked workspace is allowed, but hardware loading must be documented.
- **TTS checks:** `check-tts.mjs --entry <id>` / `--all` validates and assembles, then
  calls guest routines in the unchanged WASM VM, with bounded emulated execution and
  regular PCM draining. Init/empty/invalid calls have a 2-second emulated deadline;
  speech has 90 seconds, cancellation must return within 1 second of Escape.
  Check repeated public sentences, unchanged strings, empty/space-only/overlength input,
  cancellation and post-call silence. Write raw PRG, PCM-derived WAVs and JSON reports
  under ignored `codegen/out/tts-v1/`, including source hash and Git revision.
  Zero entries is an explicit empty result, not a successful TTS implementation.
  Shared checks never execute entrant-supplied JavaScript. Interactive editing, ROM/SD
  loading, sound-source compliance, intelligibility and physical hardware still need
  separate review; reports must not imply those were automatically established.
  PR jobs have read-only permissions, no secrets/deployment credentials and timeouts.
- **Challenge publication:** `build-challenges.mjs` renders a restricted Markdown subset
  (headings, paragraphs, lists, fences, links, inline code/emphasis; raw HTML escaped).
  The launch revision comes from the first-add commit of the versioned prompt; active
  prompt/guide/metadata cannot silently differ from that commit. Before the initial
  commit only `--preview` permits unresolved-baseline generation. Build production from
  full Git history. Reference links use the resolved SHA, not moving `main`.
- The harness runs the **same `badger6502.js/.wasm`** the browser uses — build it first
  (`pwsh web/build.ps1`). Keep the toolchain **dependency-free** (no npm packages).
- `asm6502.mjs` must stay browser-safe: no static `node:*` imports at module top level, no
  reliance on `process` outside the guarded CLI tail — breaking this breaks the in-browser
  assembler (`WEB-CLIENT.md`).
- `platform-ref.*` is generated, not hand-edited; edit `vm.h`/symbols then regenerate.
- Local WOZ editing must validate container bounds/CRC, address fields, 6-and-2
  checksums and exact preimages before changing data. Re-encode only changed sector
  data fields; do not rebuild a supplied disk into a different track layout. Synthetic
  fixtures must cover malformed input, round trips and unchanged surrounding bits.
- **AI-contributor path.** The codegen guide is exposed for external AI tools: `web/llms.txt`
  (published at the site root, owned by `WEB-CLIENT.md`) is the machine-readable entry point
  that links `prompt-system.md` + `platform-ref.md`, and `prompt-system.md` closes the loop to
  the gallery (write → test → submit a `gallery.json` entry, per `CONTRIBUTING.md`). Keep
  `llms.txt`'s inline quickstart in sync with `prompt-system.md` when the dialect or entry/exit
  conventions change.

## Data flow

`.s source → asm6502.assemble() → bytes + symbols + source listing metadata → harness loads
into RAM at --org → run → capture serial/text/gfx/regs → checks PASS/FAIL → optional .PRG
(+ manifest)`. The browser additionally maps listing instruction PCs back to source rows for
breakpoints and current-PC highlighting.

## Dependencies

- **Upstream:** the WASM build (`WEB-CLIENT.md`) and the VM memory map/ROM symbols
  (`EMULATOR.md`, `ROM-SOFTWARE.md`).
- **Downstream:** the `.PRG` programs (`ROM-SOFTWARE.md`) and the browser assembler, which
  stages `asm6502.mjs` + sample `.s` sources.

## Implementation Status

| Item | Status | Notes |
|---|---|---|
| Versioned TTS brief, entry validation and PCM checks | Implemented | Bounded guest calls, PRG/WAV/reports and positive/negative tooling fixtures; human listening/hardware checks remain separate. |
| `asm6502` assembler + encoding tests | Shipped | dual-use; `asm6502.test.mjs`. |
| Source listing metadata | Shipped | Each emitted record reports PC, bytes, source line, and instruction/data kind for browser debugging; covered by `asm6502.test.mjs`. |
| `harness` + `run6502` validation loop | Shipped | serial/text/gfx/register checks + `.PRG`. |
| `gen_platform_ref` platform reference | Shipped | from `vm.h` + `badger6502.dbg`. |
| Archon local WOZ patching | Experimental / emulator-verified | `patch-archon.test.mjs` covers synthetic editor fixtures and optional owner-supplied-disk gameplay; `patch-archon.test.ps1` covers native PS/2 timing and LED commands. Both game images stay outside the repository. |
| Sample programs | Shipped | `codegen/programs/hello.s`; games under `emulator/AICodeGen/`. |
| AI-contributor entry point | Shipped | `web/llms.txt` + `CONTRIBUTING.md`; `prompt-system.md` closes the loop to the gallery. |

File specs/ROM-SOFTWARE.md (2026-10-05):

# 3ric — ROM & Software Spec (ROM-SOFTWARE.md)

> The 512 KB system ROM (monitor, DOS shell, BASIC), the character/font ROM, and the 6502
> programs that run on 3ric. This is the software the CPU actually executes; the emulator
> (`EMULATOR.md`) and hardware (`HARDWARE.md`) exist to run it.

---

## Purpose

Provide the machine's firmware and application software: power-on monitor, a FAT32 DOS
shell, Microsoft BASIC, and a growing library of 65C02 programs (games, demos) that load
from a micro-SD card, a Disk II floppy, or the in-browser assembler.

## Contracts / Interfaces

- **3RIC Talks v1:** the public challenge requests original English TTS implemented on
  the 65C02 and dual-AY Mockingboard, with typed input and reusable init/speak routines.
  Its complete, versioned contract is `codegen/challenges/tts/v1/prompt.md`; per-entry
  README/metadata document implementation status, memory, controls, ABI and provenance.
  There are no engines or physical-hardware results in the initial publication.
  Sources are independent PR submissions, not replacements for ordinary gallery samples.
  The target is 3RIC; Apple II compatibility requires a separately verified port.
  RAM includes always-mapped `$0000-$8FFF`, an additional `$9000-$BFFF` when `$C007`
  disables the BASIC overlay (`$C006` restores it), and language-card RAM over upper ROM.
  Using that last region requires safe ROM visibility, input and interrupt handling;
  `$C800-$CFFF` contains system state, not disposable scratch. No hardware map is changed.
- **System ROM:** `emulator/Data/badger6502.bin` (512 KB; first 64 KB mapped `$D000–$FFFF`
  plus banked regions). Contains the monitor, the DOS/FAT32 shell, the Disk II boot PROM
  (`$C600`), and Microsoft BASIC (`$9000–$BFFF`). Reset vector at `$FFFC/$FFFD`. Built with
  cc65/ca65; debug symbols in `badger6502.dbg` (consumed by `codegen/gen_platform_ref.mjs`).
- **Font ROM:** `emulator/Data/fontrom.dat`, loaded by the text renderer.
- **ROM entry points (contract for programs; curated in `codegen/platform/platform-ref.*`):**
  `COUT $FDED`, `COUT1 $FDF0`, `CROUT $FD8E`, `PRBYTE $FDDA`, `HOME $FC58`, `KEYIN $FD1B`;
  DOS shell `dos $EDBC` (mount + `>` prompt), verbs `BSAVE/BLOAD/BRUN/DIR/CAT/CD`, FAT32
  `fat32_file_read/write`.
- **SNES gamepad (contract for programs):** the ROM scans the two SNES pads from an
  interrupt raised on the VIA CB2 edge. A program touches **`PTRIG $C070`** to raise that
  edge (→ NMI pad scan; the NMI is non-maskable, so a program may poll the pad while running
  under `sei`), then reads **`GAMEPAD1 $CEE0`** / `GAMEPAD2 $CEF0` — 16-byte tables, one byte
  per button (`1` = pressed): `B`=0, `Y`=1, `SELECT`=2, `START`=3, `UP`=4, `DOWN`=5,
  `LEFT`=6, `RIGHT`=7, `A`=8, `X`=9, `L`=$A, `R`=$B. `JOYSTICK_MODE $CE15` must be `0`
  (pads — the power-on default). The emulator models the same two active-low SNES shift
  registers on VIA1, so host-supplied controller masks flow through the unmodified ROM scan;
  a disconnected controller reports no buttons. Programs may still reject impossible states
  such as `LEFT`+`RIGHT` defensively. Addresses are exported in
  `codegen/platform/platform-ref.*`. The ROM scan also reloads VIA1 Timer 1 and
  Timer 2; a guest borrowing either timer must account for that reload and for
  the ROM NMI handler acknowledging timer flags.
- **`.PRG` programs:** assembled by the codegen toolchain (`CODEGEN.md`). Sources: tracked
  `.s` files (`codegen/programs/hello.s`, `emulator/AICodeGen/<name>/<name>.s`); assembled
  `.prg` images are git-ignored (regenerated). Run on hardware/SD via `BRUN NAME.PRG <org>`,
  or in the browser via **Load .PRG** / **Assemble & Run**.
- **Archon compatibility experiment:** an image-specific, disk-only adapter for the
  owner-supplied WOZ2 with SHA-256
  `a7722abdfc42ef7372b5183283b6f55464c3817b1c855256186cb5c30e600c8d`.
  It targets the unchanged repository ROM with SHA-256
  `fcea03683b77b7f113e6d8f0064ea8edbd6c75b04b472ec5c84de1c3a9f86435`.
  The game and resulting disk are local inputs/outputs, not repository assets.
  - **Banking:** the original menu temporarily exposes language-card RAM; gameplay
    also uses both language-card banks. Neither preserves 3ric's ROM NMI vector.
    A resident adapter must keep a valid NMI entry when RAM is visible, preserve
    interrupted registers and the selected bank, and coexist with the game's loaded
    graphics/code. Forcing ROM permanently visible or suppressing input is not a fix.
    This profile reserves `$C800-$C9FF`, `$CC00-$CDFF`, `$CF00-$CFFF` and the shared
    language-card NMI vector at `$FFFA-$FFFB`; these are **not general free-RAM
    declarations**. Interactive menu drawing remains RAM-mapped. Bank-switch wrappers
    preserve the requested bank; a stop-bit interrupt at the switch/state-store
    boundary recovers the just-selected mode from the interrupted X register.
  - **Input:** retain keyboard gameplay and the game's options, and adapt the two
    onboard SNES pads through real VIA latch/clock/data pins. Avoid unnecessary
    paddle-timer/strobe NMIs and acknowledge serviced VIA sources without discarding
    an arriving PS/2 clock. Keyboard coverage must include real scan frames and
    bidirectional Caps/Num Lock command exchanges, not only browser `keyDown`.
    The D-pad supplies neutral/low/high digital axes; B or X selects/fires for each
    controller. Both two-player keyboard-side options retain their original side
    assignment. Keyboard direction latches and fire duration remain game-owned.
  - **Delivery:** reject other disk/ROM revisions, write a separate output file,
    preserve unrelated WOZ bits, track layout, metadata and sectors, and regenerate
    affected sector checksums and the container CRC. No firmware, VM, web bridge,
    generated platform-reference or hardware-decoder change is part of this port.
    The patcher checks the full ROM file fingerprint; the boot installer checks the
    relevant NMI proxy/input-code ABI, not a full physical-ROM readback.
  - **Acceptance:** cold-boot the actual output through the Disk II loader in native
    and WASM builds; exercise options, board input and combat, including mixed
    keyboard/pad traffic and bank restoration. Emulator results are not a physical
    board or complete-playthrough certification. The implementation is an
    emulator-verified hardware-trial candidate; commands, fingerprints, coverage and
    remaining limits are recorded in [`docs/porting-logs/archon.md`](../docs/porting-logs/archon.md).
- **Bouncing Ball (scottybe's community contribution):** the canonical source remains
  `web/programs/bouncing-ball.s`, loaded at `$0800` by the gallery, assembler, or
  `BRUN BOUNCE.PRG 0800`. Its 114-vertex, 128-face checkerboard sphere is transformed,
  back-face culled, filled, and outlined on the 65C02 every frame; it is not a
  prerecorded sprite animation.
  - **Preserved presentation:** the perspective room grid, opaque black/white faces,
    mesh outlines, 64-step two-axis rotation, gravity, wall/floor bounces, and alternating
    hi-res pages retain the contribution's frame-by-frame pixels and motion. Any key
    acknowledges `$C010` and executes `BRK`, as in the original.
  - **Hardware performance:** cache the static room once, restore only the old ball's
    rectangle on the hidden page, and use integer lookup arithmetic, incremental
    polygon-edge intersections, and byte-wide spans instead of per-pixel division.
    Over a 128-frame regression sequence, including both page initializations, mean
    live-frame cost must be at most **one tenth** of the original mean; every individual
    frame must be at least **nine times faster** and stay below **520,000 cycles**.
    The baseline is PR #58's merge `fc4d46e`, averaging 4,814,984 cycles per frame.
    Measure emulated 65C02 cycles, not host time or an increased emulator clock.
    Further optimization must retain fully live transformation and rasterization,
    the existing resolution/mesh detail, and the original pixels. Static arithmetic
    tables are allowed; cached rotation poses, visibility frames, and rendered ball
    animations are not. The user prioritizes this appearance over a second tenfold gain.
  - **Memory and delivery:** the raw image ends below `$2000`; the two display pages
    stay at `$2000-$5FFF`. Scratch state uses `$06-$0F` and `$50-$AF`, outside the ROM's
    text-window and I/O vectors. Tables use `$6000-$6FFF`, and the immutable room cache occupies
    `$7000-$8FFF`, below BASIC ROM. The standalone source builds through the existing
    assembler and `.PRG`/bootable `.woz` exports without assets or a new loader.
    No ROM, VM, bridge, platform-reference, or hardware-decoder contract changes are
    required. Emulator cycle measurements are not a physical-board benchmark.
- **3RIC Groovebox:** `codegen/programs/groovebox.s` is a standalone `$0800` 65C02
  music app, not a browser synthesizer. Its 40x24 text interface edits a looping 16-step
  pattern for six voices: bass, lead, and arpeggio on the left AY; kick, snare, and hi-hat
  on the right AY. It starts playing an original demo at 120 BPM.
  - **Sound:** all synthesis uses the existing slot-4 `$C400/$C480` VIA/AY interface,
    with tone periods calculated for 3RIC's 1.5734375 MHz clock. Each voice has independent
    step enables, pitches, mute, and a Pluck/Soft/Long software-envelope preset. Kick has
    a descending pitch sweep; snare mixes tone and noise; hi-hat uses noise. The right
    chip's noise generator is physically shared: a hat's noise-period setting also
    colors a simultaneously sounding snare. No independent noise generators are faked.
  - **Timing:** left-VIA Timer 1 free-runs at approximately 240 Hz. With IRQ masked,
    `WAI` wakes on its IRQ and the program acknowledges the timer directly; it does not
    replace the ROM IRQ/NMI vectors or disturb the onboard VIA's gamepad wiring. A
    fractional accumulator schedules sixteenth notes at 60-180 BPM in 5-BPM increments,
    independently of drawing and host display refresh. Envelopes and controller
    debouncing use the same hardware timebase. Detail-field redraws defer to the next
    input scan when a six-voice trigger uses the current tick's budget.
  - **Controls:** the first SNES pad uses D-pad to select a voice/step, A to toggle the
    step, B/Y to raise/lower its note, X to mute the voice, Select to cycle its envelope,
    Start to stop/restart from step 1, and L/R to decrease/increase BPM. Navigation
    repeats after a hold delay; other pad actions require a fresh press, including after
    startup. Opposing D-pad directions cancel. Keyboard equivalents are arrows/WASD,
    Space, `+`/`-`, M, I, Return, and `[`/`]`; Q silences the chips and returns to the
    monitor. Gamepad input goes through `PTRIG` and the ROM's `GAMEPAD1` table.
  - **Editing:** disabling a step retains its pitch. Note editing enables the selected
    step and clamps to a two-octave range; the hat instead selects noise periods 1-24.
    Enabled, unmuted edits can be auditioned while stopped. Mute and stop silence voices
    immediately. The selected cell, playback position, voice activity, BPM, note/noise
    period, and envelope remain visible. Edits are RAM-only; reloading restores the demo.
  The raw image ends below its `$6000-$61FF` workspace and uses text page 1, leaving
  the memory map, ROM, core, bridge, and hardware-decoder contracts unchanged. Browser sound still
  requires native 1x speed and an initial pointer/keyboard gesture.
- **Built from Bits (Hackaday showcase):** `codegen/programs/hackaday.s` is an original,
  self-running `$0800` 65C02 showreel, not a browser animation or a prerecorded video.
  - **Four scenes:** a hi-res 3RIC title and moving starfield; a 16-color lo-res plasma;
    a software-rasterized rotating wireframe cube; and a six-channel musical sequencer
    display. The bottom four text rows explain the active hardware technique and controls.
    Scene changes are automatic, with a complete loop of approximately one minute at 1x.
  - **Sound:** an original looping composition programs the two slot-4 AY chips through
    their 6522 ports at `$C400` / `$C480`. Six pitch/level indicators reflect the values
    sent to the chips, not fabricated audio measurements. Music is optional on physical
    machines without the sound expansion; video timing never depends on its presence.
  - **Controls:** 1-4 selects a scene; N/Right advances and Left goes back; Space freezes
    animation and the score and silences sound; M toggles music without freezing the demo.
    Q/Esc silences both AYs, restores page-1 text mode, and returns to the monitor with
    `BRK`. These are ordinary `$C000` / `$C010` keyboard inputs, including the browser's
    existing virtual keyboard.
  - **Timing and memory:** the onboard VIA at `$C200` reserves Timer 2 for a polled
    approximately 25 Hz cadence. Its Timer-2 interrupt is disabled without disabling
    unrelated VIA interrupts; previous ACR/IER settings are restored on exit. Drawing
    must fit within a 63,000-cycle steady-state frame budget. The image ends below
    `$2000`; graphics use page 1 (`$2000-$3FFF`) and the normal text/lo-res page
    (`$0400-$07FF`); lookup tables and working data live in `$6000-$67FF`.
  All pixels, musical register writes, sequencing, and input handling execute on the
  65C02 through existing contracts. No ROM, VM, memory-map, platform-ref, or hardware-decoder changes
  are required. A hardware-compatible binary is not a claim of a physical-board test.
  The ROM's text-window bounds at `$20-$23` (`WNDLFT`/`WNDWDTH`/`WNDTOP`/`WNDBTM`)
  remain untouched throughout the demo. Drawing coordinates use `$58-$5B` instead.
  Q/Esc must restore a usable visible monitor after every scene, not merely produce a
  serial BRK dump; exit coverage includes the on-screen prompt and a subsequent memory
  examination command.
- **Matrix Rain:** `codegen/programs/matrix.s` is a self-running `$0800` hi-res demo:
  - **Presentation:** 40 independent streams of original 3x5 letter/digit glyphs fall
    through 32 character rows. White heads leave green trails whose last two characters
    fade with spatial dithering before being erased. The screen starts populated, without
    a title screen, HUD, or audio.
  - **Motion:** a nonzero 16-bit LFSR chooses glyphs, initial positions, lengths of 8-23
    characters, per-column movement periods of 2-5 animation ticks, and restart gaps of
    4-19 ticks. A stream's entire tail leaves the bottom before that column restarts.
    Incremental cell updates and a short CPU delay pace the demo for native 1x speed;
    selecting a faster emulator clock intentionally speeds it up.
  - **Controls:** Space pauses/resumes both motion and glyph changes; Q or Esc restores
    page-1 text mode, clears the screen, and returns to the ROM monitor with `BRK`.
  - **Memory and portability:** the image ends below `$2000`; hi-res page 1 occupies
    `$2000-$3FFF`, glyph history `$6000-$64FF`, and scanline tables `$6500-$66BF`.
    Off-screen cells are clipped, never wrapped. All animation, keyboard handling, and
    artifact-color selection execute on the CPU using existing machine contracts, with
    no browser-specific drawing or emulator changes.
- **Jungle Quest — The Sunstone Run:** `emulator/AICodeGen/jungle/jungle.s` is an original
  mixed-hi-res action platformer loaded at `$0800`. Its six flip-screens form one authored
  expedition rather than interchangeable obstacle rooms:
  - **Movement:** A/D or Left/Right runs; W/Up/Space jumps; S/Down ducks. Input includes a
    short movement latch for the keyboard's event-driven interface, a four-frame coyote
    window, a five-frame jump buffer, and a low ducking hitbox. A grabbed vine follows a
    pendulum arc and Jump releases it without immediately re-catching; it also releases
    safely over the far bank.
  - **Hardware controls:** SNES D-pad moves/ducks and A/B jumps via the ROM's
    `PTRIG`/`GAMEPAD1` contract. The browser maps standard USB/Bluetooth controllers through
    the emulator's SNES/VIA peripheral; impossible opposing directions remain rejected.
    End screens ignore repeated gameplay keys: Return restarts from the keyboard, while
    Start/A/B must be released before a fresh pad restart press.
  - **World:** screen descriptors define up to two ground gaps, two raised platforms, one
    vine, a checkpoint, and a distinct moving threat. The route teaches a boulder jump,
    platform traversal, an active vine crossing, and ducking under a bat before combining
    those verbs at the ruins and temple.
  - **Objective and rewards:** four mandatory glyphs on the first four screens unlock the
    temple; optional fruit awards score and restores time. The final Sunstone ends the run.
    Death costs one of three lives and five clock units but respawns at the current screen's
    checkpoint with collected items preserved. The initial gameplay clock is 90 units.
  - **Presentation:** a textured jungle/ruins background, water-filled gaps, raised masonry
    and animated player/threat sprites make each screen readable. The mixed-mode HUD shows
    score, time, lives, glyph progress, and contextual gate/status messages.
  Focused headless hooks verify renderer primitives, buffered/coyote jumps, platform and
  gap collision, duck-vs-bat behavior, item effects, checkpoint death, gate progression,
  vine release, timer states, restart input gating, and final victory. The assembled image
  must end below the hi-res page at `$2000`.
- **STAR DUEL:** `emulator/AICodeGen/spacewar/spacewar.s` is an original two-player
  mixed-hi-res gravity-duel loaded at `$0800`. It reuses only un-copyrightable Spacewar-style
  conventions — two ships, a central sun, inverse-distance gravity, wrap, thrust inertia,
  and torpedoes — with original names, silhouettes, HUD copy, and 65C02 code.
  - **Playfield:** mixed hi-res (280×160 XOR vector ships over a persistent sun/starfield)
    plus four text HUD rows. The image ends below `$2000`; row tables live at `$6000/$6100`,
    working RAM at `$6200`, and ship/shot structs at `$6300`.
  - **Gravity:** each live ship is pulled toward the sun at (140, 80) with a 32-entry
    magnitude table indexed by Manhattan distance. Near-sun Chebyshev range 6 is fatal;
    the opponent scores if the match is underway. Ships spawn off the sun's row so the
    opening volley is not eaten by the well. Torpedoes use a Chebyshev box that covers the
    wedge silhouette (radius 10) plus shot step, and die on a ship or the sun.
  - **Controls:** SNES pad 1 and pad 2 both go through `PTRIG` + `GAMEPAD1`/`GAMEPAD2`.
    D-pad left/right rotate, Up/B thrust, A/Y fire, Select hyperspace, Start starts or
    rematches. Opposing D-pad directions cancel. Keyboard P1 is A/D or arrows to rotate,
    W/Up to thrust, S/Space to fire, H for hyperspace; P2 is J/L, I, K/U, N. Q/Esc restores
    page-1 text and `HOME`s to the monitor with `BRK`. First player to 5 kills wins.
  Focused headless hooks cover the row table, XOR plot, gravity sign/magnitude, wrap,
  thrust, firing, sun/ship/shot collisions, scoring, and dual-pad input. No ROM, VM,
  memory-map, platform-ref, or hardware-decoder changes are required.
- **SUNSLING:** `codegen/programs/sunsling.s` is a separate, original two-player
  Spacewar-style game, not a revision or copy of STAR DUEL. It loads at `$0800`.
  - **Flight and combat:** two distinct vector ships duel around a central sun in a
    wrapping 256x160 arena inset within mixed hi-res video. Signed 8.8 velocities,
    16 headings, thrust, and a softened inverse-square gravity approximation run on
    the 65C02. Gravity bends torpedoes as well as ships. Each pilot has four torpedo
    slots; shots inherit launch velocity, expire, and cannot hit their owner. The sun,
    enemy torpedoes, and ship-to-ship contact are lethal. The opponent earns one point
    per death; simultaneous deaths are resolved together, including a 5-5 draw.
    First to five wins. Respawning includes a brief shield against enemy contact,
    but never protection from the sun.
  - **Controls:** each SNES pad uses Left/Right to turn, Up/B to thrust, A/Y to fire,
    Select for a safe-perimeter hyperspace escape (eight-second cooldown), and a fresh
    Start press to start/pause/resume/rematch. Opposing directions cancel; releasing or
    disconnecting a controller releases its level controls.
    Keyboard P1 uses A/D (or Left/Right) to turn, W/S (or Up/Down) for burn/coast,
    F/Space for a short torpedo burst, and E for hyperspace. P2 uses J/L, I/K, U, O.
    Keyboard throttle is explicitly latched on/off, not a fabricated key-up interface:
    both pilots can keep burning while independently steering or firing. Enter starts
    or rematches, P pauses/resumes, M mutes effects, and Q/Esc quits. Pausing freezes
    physics, lifetimes, respawns, and cooldowns; held Start/Select never retrigger.
  - **Presentation and timing:** an original pixel title, persistent starfield/sun,
    XOR ship outlines, exhaust, expanding explosion particles, and four text HUD rows.
    Brief effects toggle the real `$C030` speaker. A polled onboard VIA Timer 2 targets
    30 Hz at native 1x; steady-state work must fit a 52,448-cycle frame, including
    two active pilots and eight torpedoes. The ROM's SNES scan reloads both onboard
    timers, so the frame countdown is armed immediately after that scan, allowing
    1,600 cycles for the current ROM scan and surrounding frame-loop overhead.
    Regression coverage measures idle, one-pad and two-pad scans as well as full
    combat load against the staged ROM; ROM timing changes must not be hidden by
    widening the cadence tolerance. Completion reads the counter's wrap,
    not an IFR bit that a later ROM NMI can acknowledge. Frame periods stay within
    200 cycles of 52,448. The timer interrupt is disabled without
    disabling unrelated VIA interrupts. Prior ACR, Timer-2 interrupt enable, joystick
    mode, and CPU flags are restored on exit, then text page 1, `HOME`, and `BRK`
    return to a usable monitor. ROM text-window bytes and vectors remain untouched.
  - **Memory and delivery:** the raw image ends below `$2000`; hi-res page 1 is
    `$2000-$3FFF`, lookup tables `$6000-$63FF`, state `$6400-$65FF`, and scratch
    zero page `$50-$7F`. The gallery/editor stages the canonical source with the
    existing wildcard and exports ordinary `.PRG` and bootable `.woz` files.
    No ROM, VM, bridge, memory-map, platform-ref, or hardware-decoder changes are
    needed. Emulator measurements do not claim a physical-board playtest.
- **PULSAR DUEL:** `emulator/AICodeGen/pulsar/pulsar.s` is a second, independent
  two-player gravity duel at `$0800`, written from scratch alongside STAR DUEL rather
  than derived from it. It shares only the un-copyrightable Spacewar-style premise — two
  ships, one gravity well, wrap, inertia, torpedoes, hyperspace — and differs in every
  implementation choice below.
  - **Playfield:** a 256×160 *logical* field, so logical x is a single byte and wraps mod
    256 for free; logical x maps to hi-res column x+12 to centre the 280-pixel line, and
    logical y is scanline 0..159 wrapped by hand. Four text HUD rows sit underneath. All
    working RAM and the `ROWL`/`ROWH`/`XBYTE`/`XMASK` tables are part of the image, which
    ends below `$2000` — nothing is scribbled at `$6000`.
  - **Gravity:** the pulsar sits at logical (128, 80), dead centre, so the vertical
    component never needs wrap correction. Distance is the octagonal norm
    `r ~= max(|dx|,|dy|) + min(|dx|,|dy|)/2` (about 6% error, and it guarantees
    `|d| <= r`). A 176-entry table holds `F[r] = round(G*65536/r^3)` with `G = 160`,
    clamped at 10,486 below `r = 10`; per-axis acceleration is `(|d| * F[r]) >> 8` in 8.8 via an
    8x16 shift-add multiply, giving a true inverse-square field with no division.
    Integration is semi-implicit Euler (velocity then position), so orbits are stable.
    Torpedoes fall into the well on exactly the same code path, so shots curve.
  - **Orbital opening:** both pilots spawn *in orbit*, not at rest — 48 logical pixels
    out on opposite sides, travelling 1.64 px/frame tangentially, in the same rotational
    sense. r = 48 keeps the whole path clear of the `y = 0/160` wrap seam; the orbit
    precesses between r = 47 and r = 61 and never falls in unattended.
  - **Rendering:** ships are XOR vector triangles plus an exhaust line, from per-heading
    vertex tables at 32 headings; erasing is literally redrawing the previous
    `(x, y, heading, thrust)`, so the starfield and pulsar survive underneath. Explosions
    are expanding eight-point rings. Lines use signed 8-bit Bresenham with a 48-step
    safety counter.
  - **Controls:** both SNES pads via `PTRIG` + `GAMEPAD1`/`GAMEPAD2` — D-pad left/right
    rotate, Up/B thrust, A/Y fire, Select hyperspace, Start begins or rematches; opposing
    D-pad directions cancel. The keyboard latch has no key-up, so every recognised press
    arms a hold timer that is replayed as held intent for several frames: P1 is A/D, W,
    S, X and P2 is J/L (or arrows), I (or Up), K, M. Q/Esc restores text, `HOME`s, and
    `BRK`s to the monitor. Hyperspace misjumps one time in eight and credits the
    opponent. First to 5 kills wins.
  Verified by `codegen/tools/pulsar.test.mjs`, whose headless hooks cover the row/column
  tables, XOR plot self-inversion, line drawing, the octagonal norm across the x seam,
  gravity sign and magnitude, 240 frames of orbit stability, turning, thrust, velocity
  caps, both wrap axes, per-player torpedo magazines and cooldown, torpedo curvature and
  expiry, pulsar/torpedo kills, spawn protection, respawn, match end, keyboard hold
  timers, dual-pad input, draw/erase round-tripping, HUD contents, and the per-frame
  cycle budget. No ROM, VM, memory-map, platform-ref, or hardware-decoder changes are
  required.
- **Disk & card images:** demo `.woz` (staged from `emulator/WozFileTestApp/testdata/`);
  `emulator/Data/sd.zip` → `web/data/sd.sparse` FAT32 image (`WEB-CLIENT.md`).

## Behaviour / Rules

- **Known limitation — no Applesoft.** The `$E000` BASIC is generic Microsoft BASIC (prompts
  `MEMORY SIZE?`). Disks whose boot auto-runs an Applesoft greeting (DOS 3.3 / Quick-DOS
  System Masters and games chaining through them) load DOS but then trap. Self-booting
  machine-code disks run fine. Treat this as a documented gap, not a bug to paper over.
- **The ROM defines the memory-map contract in practice.** ROM routines assume the `MM_*`
  layout in `vm.h`; a memory-map change means rebuilding/re-verifying the ROM and
  regenerating `platform-ref.*`.
- 6502 sources target the `asm6502.mjs` dialect and conventions in
  `codegen/platform/prompt-system.md`.
- **ROCK STORM performance contract.** An opening-wave live frame (compose the hidden
  page and flip it) must complete in at most **175,000 65C02 cycles** in the headless
  emulator. The live loop must not add a fixed busy-wait when rendering already consumes
  the available frame time. Its cycle check and pixel/gameplay tests live in
  `codegen/tools/rocks.test.mjs`.

## Data flow

`badger6502.bin → mapped $D000–$FFFF + banks; reset → monitor → (Disk II C600G | DOS EC5CG |
BRUN) → user program runs → COUT/screen/serial output`.

For Matrix Rain:
`gallery/sample source → assembler → $0800 program → $C000/$C010 pause/quit input +
LFSR/column timers → glyph history and clipped hi-res cell writes → existing native/WASM
artifact-color renderer → display`; quitting selects text mode and executes ROM `HOME`
then `BRK`.

For Bouncing Ball:
`gallery source / raw PRG / bootable WOZ -> $0800 program -> gravity + rotation ->
cached room restore + live vertex transforms, face visibility, polygon fills, and mesh ->
hidden hi-res page -> $C054/$C055 page flip -> existing hardware/native/WASM display`.
Keyboard input follows the existing `$C000/$C010 -> BRK` path.

For Built from Bits:
`Hackaday landing page / gallery / sample -> existing browser assembler or BRUN -> $0800
program -> keyboard + polled VIA Timer 2 -> scene/score state -> text/lo-res/hi-res RAM
and slot-4 VIA/AY writes -> shared native/WASM video and audio outputs`.

For Jungle Quest:
`keyboard event or SNES poll → movement/jump/duck latches → 8.8 physics → terrain/platform/
hazard/item collision → lives/time/glyph/score state → BG restore + sprite redraw → hi-res
page and mixed-mode HUD`; a screen-edge transition loads the next descriptor, while death
reloads the same descriptor at its checkpoint.

For STAR DUEL:
`keyboard hold-timers or PTRIG + GAMEPAD1/GAMEPAD2 → rotate/thrust/fire/hyperspace intents
→ 8.8 inertia + Manhattan gravity toward the sun → wrap/collisions/score → XOR erase/draw
on hi-res page 1 + mixed-mode HUD`; Q/Esc selects text mode, `HOME`, then `BRK`.

For SUNSLING:
`gallery/editor or raw PRG/WOZ -> $0800 -> keyboard burn/coast and burst latches or
PTRIG/ROM scans of both SNES pads -> timer-paced 8.8 ship/torpedo gravity and inertia
-> toroidal collisions, simultaneous scoring, respawn/shield/cooldown state -> XOR
hi-res vectors + text HUD + $C030 -> existing native/WASM video/audio`.
Pause holds simulation state; quitting restores the borrowed I/O settings and monitor.
For PULSAR DUEL:
`keyboard hold-timers or PTRIG + GAMEPAD1/GAMEPAD2 → rotate/thrust/fire/hyperspace intents
→ XOR erase of last frame's geometry → octagonal-norm inverse-square gravity via an `r^-3`
force table + 8x16 multiply → 8.8 semi-implicit Euler for ships and torpedoes → dual-axis wrap /
collisions / score → XOR draw on hi-res page 1 + mixed-mode HUD → frame pacing`; Q/Esc
selects text mode, `HOME`, then `BRK`.

For Groovebox:
`keyboard or SNES/VIA/ROM scan -> sequencer edits -> Timer 1 IRQ/WAI tick -> step and
software-envelope state -> real VIA/AY register writes -> shared VM stereo PCM -> host
audio`; the program separately writes its editor and playhead into text video RAM.

## Dependencies

- **Upstream:** the assembler/build (cc65/ca65 for the ROM; `CODEGEN.md` for programs).
- **Downstream:** the emulator loads and executes it (`EMULATOR.md`); the platform reference
  is derived from its symbols (`CODEGEN.md`).

## Implementation Status

| Item | Status | Notes |
|---|---|---|
| 3RIC Talks v1 challenge contract | Implemented; no engines yet | Original dual-AY TTS, bank-aware RAM rules, reusable ABI and separate source/PR submissions. No speech or hardware result claimed. |
| System ROM (monitor / DOS shell / FAT32) | Shipped | `badger6502.bin`; boots to monitor. |
| Microsoft BASIC | Shipped | `$9000–$BFFF`; not Applesoft (known gap). |
| Font ROM | Shipped | `fontrom.dat`. |
| Disk II boot PROM | Shipped | `$C600`; boots self-booting WOZ images. |
| Archon disk-only compatibility adapter | Experimental / emulator-verified | Exact-image patcher; actual disk boot, options, keyboard and two-pad board/combat input, runtime mismatch guards, and native PS/2/LED/register/bank checks. Physical board and full-playthrough approval remain open; see the porting log. |
| 6502 program library | Ongoing | `codegen/programs/`, `emulator/AICodeGen/` (games/demos). |
| Bouncing Ball | Implemented / cycle-guarded | 5,376-byte standalone image; 419,704 mean / 438,580 worst cycles over 128 pixel-identical frames, an 11.47x mean speedup over PR #58 and 14% faster than the first optimized version. `codegen/tools/bouncing-ball.test.mjs` covers motion/page history, all signed-byte products, 4,096 independent angle pairs, 512 independent complete rasters, every restore alignment, extreme positions, memory boundaries, keyboard exit, and ROM WOZ boot. |
| 3RIC Groovebox | Shipped | Six-voice, 16-step Mockingboard sequencer; gamepad/keyboard editing and timer-driven stereo sound. `codegen/tools/groovebox.test.mjs` covers real stereo PCM, all controls, fractional tempo, clean exit, and a dense-step/input deadline below 6,556 cycles. |
| Built from Bits | Implemented | 3,460-byte four-scene showcase with rendering, 63,000-cycle cadence, audio, controls, and WOZ boot coverage. ROM window bounds are preserved; Q/Esc from every scene must leave a visible prompt that can execute and display a subsequent monitor command. |
| Matrix Rain | Shipped | `codegen/programs/matrix.s`; 1,079-byte `$0800` hi-res demo with staggered green trails, white heads, pause/quit controls, and focused rendering, timing, memory-boundary, and monitor-exit coverage in `codegen/tools/matrix.test.mjs`. |
| ROCK STORM vector game | Shipped / cycle-guarded | Opening-wave live frame is 133,262 cycles against a 175,000-cycle limit; both distributed `.prg` copies are generated from `rocks.s`. |
| SNES gamepad input | Shipped | ROM fills `GAMEPAD1/2` on a `$C070` touch; the shared emulator peripheral follows the same VIA serial protocol, and the browser maps two standard USB/Bluetooth controllers into it. |
| Jungle Quest — The Sunstone Run | Shipped | Six-screen `$0800` mixed-hi-res platformer; focused suite includes a complete successful expedition. |
| STAR DUEL | Shipped | Two-player `$0800` mixed-hi-res gravity duel; SNES pads + keyboard; `codegen/tools/spacewar.test.mjs` covers gravity, wrap, shots, collisions, and dual-pad input. |
| SUNSLING | Implemented | Separate original `$0800` two-player gravity duel. Current-ROM scan compensation preserves the strict 200-cycle cadence tolerance; idle/one-pad/two-pad/release coverage and the full-load/900-frame regression pass (worst work 49,833, period 52,536 cycles). `codegen/tools/sunsling.test.mjs` also exercises real-VM physics, both control paths, XOR rendering, simultaneous scoring, monitor restoration, and exported WOZ boot. |
| PULSAR DUEL | Shipped | Independent two-player `$0800` mixed-hi-res orbital duel, 5,632 bytes ending `$1E00`; 256×160 logical field, octagonal-norm inverse-square gravity via an `r^-3` force table, pilots spawn in a stable r=48 orbit, torpedoes curve; live frame measures ~8,600 cycles against the 26,224-cycle budget; `codegen/tools/pulsar.test.mjs` covers 66 checks including 240 frames of orbit stability and draw/erase round-tripping. |

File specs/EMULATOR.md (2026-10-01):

# 3ric — Emulator Core Spec (EMULATOR.md)

> The 65C02 virtual machine at the heart of 3ric, in C++. The same sources power the Windows
> hosts (`Console`, WinUI) and — behind `__EMSCRIPTEN__`/`PLATFORM_WEB` guards — the browser
> build (see `WEB-CLIENT.md`). Source of truth for the machine's behavior; update it in the
> same commit as the code.

---

## Purpose

Faithfully emulate the 3ric machine: a WDC 65C02 CPU, 36 KiB always-mapped RAM plus
BASIC-overlay and language-card RAM banking, Microsoft BASIC + a 512 KB
ROM (monitor/DOS), Apple-II-style text/lo-res/hi-res video, keyboard, a `$C030` system
speaker, a 6551 ACIA serial port, a 6522 VIA (I/O + bit-banged SPI micro-SD + two serial
SNES gamepads), a slot-4 dual-AY Mockingboard, and a Disk II 5.25″ floppy. It is the **reference implementation of
the target hardware** — the emulator is correct when it behaves like the real machine will.

## Contracts / Interfaces

**Projects (`emulator/Badger6502VM.sln`):**

| Project | Role |
|---|---|
| `Badger6502VMLib` | The VM core: `vm`, `cpu`, `Instructions`, `acia`, `via`, `snesgamepads`, `mockingboard`, `ay38910`, `PS2Keyboard`, `badgervmpal` (video). Windows-only: `symbols`, `Disassemble`. |
| `WozLib` | Disk II emulation: `DriveEmulator`, `WozDisk`, `WozFile` (`.woz` images). |
| `MockMicroSD` | Bit-banged SPI SD card (`SDCard`) over a memory-mapped image (`MappedFile`). |
| `Badger6502VMTest` | MSTest (native C++) CPU and peripheral tests, including VIA, SNES gamepads, system speaker, and Mockingboard. |
| `Console`, `Badger6502Emulator`(+Package) | Win32 console and WinUI hosts. |
| `WozFileTestApp`, `dsk2woz2`, `picodisk` | WOZ tooling / disk conversion / Pico target. |

**Memory map — the cross-layer contract** (`vm.h`, `MM_*`; mirrored by the 74-series hardware decoder, the
web bridge, and `codegen/platform-ref.*`):

```
$0000–$8FFF  always-mapped RAM (36 KiB); $2000–$5FFF includes hi-res video pages
$9000–$BFFF  Microsoft BASIC ROM overlay or 12 KiB RAM
$C006/$C007  BASIC ROM on/off (off exposes RAM, giving 48 KiB below I/O)
$C000        keyboard data / $C010 strobe clear
$C030        system speaker toggle (any read or write access)
$C050–$C057  display soft switches (GRAPHICS/TEXT/…/LORES/HIRES)
$C080–$C08F  language-card bank switches
$C100–$C10F  ACIA (6551 serial)   $C200–$C20F  VIA1 (SPI micro-SD)
$C300–$C30F  ROM disk / char-gen  $C400–$C4FF slot-4 Mockingboard
$C400–$C47F  Mockingboard VIA/AY 1 (registers mirror every 16 bytes)
$C480–$C4FF  Mockingboard VIA/AY 2 (registers mirror every 16 bytes)
$C600–$C6FF  Disk II boot PROM
$C0E0–$C0EF  Disk II data/control $C800–$CFFF  RAM2
$D000–$FFFF  ROM (monitor / OS / DOS shell); reset vector at $FFFC/$FFFD
```

Soft switches are dispatched by `VM::DoSoftSwitches(address, write)`; memory-access
callbacks (`CallbackWriteMemory`, `CallbackSetSoftSwitches`) let hosts hook I/O (the web
bridge uses this to clock the SD card and advance the drive).

Language-card RAM supplies alternate 4 KiB banks at `$D000-$DFFF` and shared 8 KiB at
`$E000-$FFFF`. Read selection and write-enable sequencing are distinct; see
`DoSoftSwitches`, `GetMemoryReadMapping` and `WriteData`. Hiding upper ROM also hides
ROM input/output and interrupt handlers, and `SEI` does not mask NMI. Interactive
programs must preserve these dependencies. `$C800-$CFFF` contains system state.
These are existing mappings, not a new memory expansion.

**SNES gamepad contract (onboard VIA1 at `$C200`):**

- VIA1 PB6 drives the shared controller latch and PB7 drives the shared clock. Controller 1
  returns active-low serial data on PB5 and controller 2 on PB4.
- `VM::SetGamepadState(index, pressedMask)` accepts controller indexes 0 and 1. Bits 0–11
  are pressed-state bits in the ROM's wire order: `B`, `Y`, `SELECT`, `START`, `UP`, `DOWN`,
  `LEFT`, `RIGHT`, `A`, `X`, `L`, `R`; bits 12–15 are unused and ignored.
- A PB6 rising edge snapshots both live masks. Bit 0 is then visible on PB5/PB4; each PB7
  rising edge advances to the next bit. Host changes during a scan take effect only at the
  next latch, just like physical SNES shift registers. After bit 15 the data lines idle high.
- A machine reset clears only the in-flight serial transaction; it does not disconnect or
  release host-reported controllers. The peripheral is attached only to the onboard VIA1,
  not either slot-4 Mockingboard VIA.

## Behaviour / Rules

- CPU is driven **cooperatively**: hosts call `VM::Step()` per instruction. The VM samples
  the shared level-sensitive IRQ line before the instruction and ticks the onboard VIA plus
  both Mockingboard VIA/AY pairs for every returned CPU cycle, then advances the VM-owned
  PCM sample clock. Presentation hosts may then advance host-owned keyboard/disk plumbing.
  `VM::WillExecuteCurrentInstruction()` reports whether the next step will execute the
  opcode at the current PC rather than tick a dormant `WAI`/`STP` or service NMI/IRQ; the
  web debugger uses that boundary without changing execution. The blocking `VM::Run()` is
  not used by the web build.
- `VM::GetMemoryReadMapping()` identifies the backing store currently selected at an address
  (primary 64K image, BASIC ROM, language-card bank 1/2, or shared language-card high RAM).
  `VM::PeekData()` follows that mapping without invoking memory-mapped device reads or
  soft-switch side effects. `VM::IsROMVisible()` reports whether an address currently
  resolves to the BASIC ROM, Disk II boot ROM, or upper ROM; debugger hosts use these
  queries for bank-correct breakpoints, opcode inspection, highlighting, and source labels.
- `reset()` loads PC from `$FFFC/$FFFD`. ROM load recipe (mirrored by every host): write the
  first `0x10000` bytes of `badger6502.bin` into `GetData()`, `seedBasicRom()` (copy
  `$9000..$BFFF`), `loadFont()`, then `reset()`.
- **Portability rule:** the shared VM/WozLib/SD sources must compile and behave identically
  on Windows and Emscripten. Platform-specific code lives behind `__EMSCRIPTEN__` /
  `PLATFORM_WEB` (or MSVC) guards only — never a silent behavioral fork.
- **No fabricated emulation.** An unimplemented opcode/device/soft-switch must be observable
  (assert/log/explicit unimplemented), never a plausible-looking fake value.
- This clone's `$E000` BASIC is **generic Microsoft BASIC, not Applesoft** — a deliberate,
  known limitation (see `ROM-SOFTWARE.md`).
- Host-received ACIA bytes set RDRF, but assert the shared IRQ line only while DTR is
  asserted and receiver interrupts are enabled in the 6551 command register. A write to the
  status address performs a programmed reset independent of the written value, preserving
  the control register and command parity bits.

**System speaker and mixed-audio contract:**

- Any bus read or write at `MM_SS_SPEAKER` (`$C030`) toggles the one-bit system-speaker
  latch, matching the schematic's address-decoded toggle circuit. Reset clears the latch.
- The latch continues to respond while host audio collection is disabled. At each host PCM
  sample point, its mono level passes through a DC blocker at 0.25 full-scale gain and is
  added equally to left and right.
- PCM scheduling and buffering belong to `VM`, not either sound device: the VM samples both
  AY outputs and the speaker from the same PHI2-derived clock and exposes one interleaved
  stereo stream. Enabling/disabling collection must not stop speaker, VIA, or AY state.

**VIA timer reset and clocking contract (onboard and both slot-4 VIAs):**
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

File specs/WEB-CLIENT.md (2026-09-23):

# 3ric — Web / WASM Client Spec (WEB-CLIENT.md)

> The Emscripten/WebAssembly port and the browser UI that make 3ric playable at
> <https://ebadger.github.io/3ric/> with no install. It compiles the **same** VM core
> (`EMULATOR.md`) to WASM and renders it to an HTML canvas. Everything here is additive to
> the shared sources — see `web/README.md` for the deep dive.

---

## Purpose

Boot the real 512 KB ROM in any browser: render Apple-II text/lo-res/hi-res video to a
`<canvas>`, play the `$C030` system speaker and slot-4 Mockingboard, feed keyboard and
standard Gamepad API input through the machine's real input paths, run Disk II and
micro-SD images, and assemble/run 65C02 source client-side — all 100%
client-side so GitHub Pages can host it as static files.

## Contracts / Interfaces

- **Model challenges:** `challenges.html` introduces the software-first series;
  `challenges/tts/index.html` presents 3RIC Talks with the complete, statically rendered
  v1 prompt, a copyable kickoff task, references, submission instructions and an honest
  empty entries state. `codegen/challenges/tts/v1/` owns the canonical brief and submission
  contract. `build-challenges.mjs` generates the HTML, raw Markdown, metadata and entry
  assets; generated copies are ignored, never hand-edited. No TTS implementation,
  intelligibility result, hardware verification, ballot or video is fabricated.
  The immutable baseline is the Git commit that first adds the v1 prompt (full history
  is required). Public downloads include its SHA; subsequent entry commits do not move it.
  Uncommitted previews are explicitly labeled and cannot be used for official entries.
  Entrants commit independent directories/PRs; only maintainer-merged entries are staged.
  Each entry uses a unique flat `programs/tts-v1-<id>.s` launch path, preserving workbench
  sharing and download identity. Build/PCM checks are not listening or hardware approval.
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

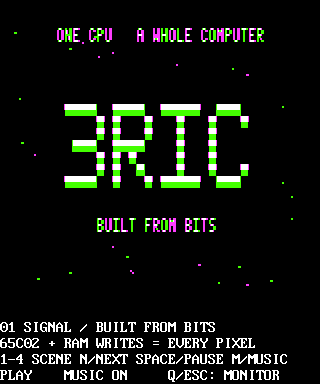
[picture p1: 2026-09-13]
web/media/hackaday-preview.png

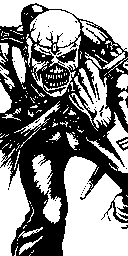
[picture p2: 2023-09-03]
romgen/fontrom/fontrom/fonts/IMPORT/EDDIE1.BMP

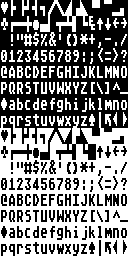
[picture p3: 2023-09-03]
romgen/fontrom/fontrom/fonts/IMPORT/ATASCII.BMP

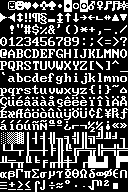
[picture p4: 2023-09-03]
romgen/fontrom/fontrom/fonts/IMPORT/BLUETERM.BMP

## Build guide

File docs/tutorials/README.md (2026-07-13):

# 3ric Game Programming Tutorials

> Learn to write games in **65C02 assembly** on the 3ric — with nothing to install.
> Every lesson runs in the in-browser **Assemble & Run** editor at
> <https://ebadger.github.io/3ric/>, so you can read, edit, re-assemble, and run each
> program with one click.

**Status: complete.** All eight lessons and their example programs are written and
**verified on the emulator**. Start with the live index at
<https://ebadger.github.io/3ric/tutorials.html> (or the **Tutorials** link in the site
header), or jump straight to **[Lesson 1 — Hello, 3ric](01-hello.md)**. Each lesson links a
one-click **▶ Run it** button that opens its program in the browser editor.

---

## Who this is for

You've programmed a little in *some* language (variables, loops, `if`) but have never
written assembly — or you've dabbled in 6502 and want to *make games* with it. You do
**not** need to own any hardware, install a toolchain, or know Apple II lore. If you can
open a web page, you can do every lesson.

By the end you'll be able to read the 3ric's shipped games (`snake`, `bricks`, `rocks`,
`swarm`, `jungle`, …) and write your own.

## How the series works

Each lesson is a short markdown page with four parts:

1. **The idea** — one new concept (drawing, input, motion, collision, randomness…),
   explained in plain language with a picture of the memory involved.
2. **The code** — a small, fully-commented `.s` program that *builds on the previous
   lesson's program*. We add one capability at a time; nothing is a black box.
3. **Run it** — a one-click link that opens the program in the browser editor and runs
   it: `https://ebadger.github.io/3ric/?src=programs/<name>.s`.
4. **Make it yours** — 2–4 exercises that change or extend the program, from
   one-liners to a small feature.

Because the lessons build on each other, by Lesson 7 you've assembled a complete little
game out of parts you wrote yourself.

### How the examples stay honest

Every example program lives in [`codegen/programs/`](../../codegen/programs) as a real
`.s` file. That means:

- It is **auto-staged to the live site** by `web/build.ps1`, so the "Run it" deep link
  always works (`?src=programs/<name>.s`).
- It is **verified headlessly** with the project harness before shipping — e.g.
  `node codegen/tools/run6502.mjs codegen/programs/<name>.s --expect-serial "…"` — so the
  code in the tutorial is guaranteed to assemble and run, never hand-waved. (This follows
  the project rule: *prove 6502 behavior on the emulator, never fake it.*)

If you've cloned the repo you can run any example locally exactly the way the site does;
if you haven't, the browser is all you need.

## What you'll need to know first (a 2-minute primer)

The 65C02 is an 8-bit CPU. The whole mental model for these lessons:

- **Three registers** you use constantly: **A** (accumulator — the "hands", where math
  and comparisons happen), **X** and **Y** (index registers — counters and offsets).
  Each holds one byte (0–255).
- **Memory** is one flat list of byte-addressable cells from `$0000` to `$FFFF` (`$` =
  hexadecimal). *Some* of those cells aren't RAM — they're the **screen**, the
  **keyboard**, and **soft switches** that flip the machine's modes. Writing a game is
  mostly "put the right byte in the right memory cell at the right time."
- **Instructions** are tiny: load a byte into a register (`LDA`), store it back to memory
  (`STA`), add/compare (`ADC`/`CMP`), jump/branch (`JMP`/`BNE`), call a subroutine
  (`JSR`/`RTS`). We introduce each one the first time we need it — you don't have to learn
  them up front.

Everything else (addressing modes, the status flags, the stack) we teach *just in time*,
in the lesson where it first earns its keep.

## The 3ric, as a game machine

The teaching subset of the hardware. Full detail is in the auto-generated
[`platform reference`](../../codegen/platform/platform-ref.md).

| Capability | What you get | Where it lives |
| --- | --- | --- |
| **Text** | 40 columns × 24 rows of characters | screen RAM at `$0400`–`$07FF` |
| **Lo-res color** | 40 × 48 blocks (or 40 × 40 + a 4-row text HUD in *mixed* mode), 16 colors | same `$0400` page, two pixels per byte |
| **Hi-res** | 280 × 192 dots | `$2000`–`$3FFF` (page 1) |
| **Keyboard** | last key at `$C000` (bit 7 = "a key is ready"); touch `$C010` to clear it | soft-switch page |
| **Mode switches** | text/graphics, lo/hi-res, full/mixed, page 1/2 | `$C050`–`$C057` |
| **ROM helpers** | `COUT` ($FDED) prints a char; `HOME` ($FC58) clears the text screen; and ~1800 more | Monitor ROM |

Two conventions used by every program in the series:

- A program is loaded at, and starts running from, its **`.org` address** (we use
  `$0800`, a chunk of free RAM). On real hardware that's `BRUN NAME.PRG 0800`.
- A program **ends with `BRK`**, which drops back to the monitor. (In the browser you just
  press Reset or run something else.)

---

## The lessons

A 40-second summary of the whole arc, then the detail. Each lesson adds one capability
and reuses the routines from the lessons before it.

| # | Title | The big new idea | You build | Mode |
| --- | --- | --- | --- | --- |
| 1 | [Hello, 3ric](01-hello.md) | assemble/run; registers; a loop; printing | a message on screen | text |
| 2 | [Drawing on the text screen](02-text-screen.md) | screen memory is just bytes | a titled, bordered scene + HUD | text |
| 3 | [Input and the game loop](03-input.md) | read the keyboard; the read→update→draw loop | a hero you walk around | text |
| 4 | [Color with lo-res graphics](04-lores.md) | mode switches; a `PLOT` routine | a movable color block | lo-res |
| 5 | [Motion and collision](05-motion.md) | velocity; bouncing off walls | a bouncing ball | lo-res |
| 6 | [Randomness and scoring](06-random.md) | an LFSR; spawning; keeping score | catch-the-food | lo-res |
| 7 | [Space Invaders](07-invaders.md) | game states; formation AI; win/lose/restart | Space Invaders, start to finish | lo-res |
| 8 | [Hi-res and beyond](08-hires.md) | hi-res dots; where to go next | a hi-res starfield | hi-res |

### Lesson 1 — Hello, 3ric
- **Goal:** get a program written, assembled, and running in the browser; understand the
  loop that prints text.
- **You'll learn:** the Assemble & Run editor; `.org` and the `.PRG`/`BRK` model;
  `LDA`/`STA` and immediate vs. loaded values; a simple `LDX`/`INX`/`BNE` loop; the `COUT`
  ROM routine; why screen/serial text uses **high-bit ASCII** (`'A'` → `$C1`) and `$8D`
  for a carriage return.
- **You'll build:** a program that prints a banner (e.g. `HELLO, 3RIC`) to the screen.
- **Program:** `codegen/programs/tut1_hello.s` — a fully-commented cousin of the existing
  [`hello.s`](../../codegen/programs/hello.s).
- **Verified by:** `--expect-serial "HELLO, 3RIC"`.
- **Make it yours:** change the message; print it twice; print your name on a second line.

### Lesson 2 — Drawing on the text screen
- **Goal:** stop using `COUT` and put bytes on the screen yourself — the foundation of all
  drawing.
- **You'll learn:** the text page at `$0400`; that rows are **not** stored back-to-back
  (the interleaved layout) and how a small **row-address table** solves that; writing a
  character by storing its (high-bit) code straight into screen RAM with indexed
  addressing (`STA base,X`); `HOME` to clear; **inverse** video for a highlighted HUD.
- **You'll build:** a static "game screen": a border box, a centered title, and a
  `SCORE: 000` HUD line.
- **Program:** `codegen/programs/tut2_screen.s`.
- **Verified by:** decoding the 40×24 text screen and matching the drawn text.
- **Make it yours:** move the box; change the border character; add a second HUD field.

### Lesson 3 — Input and the game loop
- **Goal:** make something *interactive* — the heart of every game.
- **You'll learn:** reading the keyboard at `$C000` (bit 7 = ready) and clearing the
  strobe at `$C010`; the universal **read → update → draw** loop; comparing the key with
  `CMP` and branching (`BEQ`/`BNE`) to handle W/A/S/D and the arrow keys; storing the
  player's X/Y in **zero-page** variables; erasing the old cell before drawing the new one;
  keeping the player inside the border.
- **You'll build:** a `@` hero you walk around inside the Lesson 2 box.
- **Program:** `codegen/programs/tut3_move.s`.
- **Verified by:** feeding scripted keypresses and asserting the hero's final position in
  memory.
- **Make it yours:** add diagonal keys; wrap around the edges instead of stopping; leave a
  trail.

### Lesson 4 — Color with lo-res graphics
- **Goal:** turn on color graphics and draw blocks.
- **You'll learn:** the mode **soft switches** (`$C050` graphics, `$C056` lo-res, `$C053`
  mixed, `$C054` page 1) and that you *touch* them, not write values; the lo-res memory
  model (each screen byte is **two stacked pixels** — low nibble on top, high nibble on
  the bottom) and how a lo-res row maps to a text row; a reusable **`PLOT` subroutine**
  (given X, Y, color) — the same nibble-packing idiom the shipped `snake.s` uses; the
  16-color palette.
- **You'll build:** a color swatch test, then a single block you move with the keyboard
  (Lesson 3's input, now in color).
- **Program:** `codegen/programs/tut4_lores.s`.
- **Verified by:** asserting the plotted screen bytes for a few known cells.
- **Make it yours:** cycle the block's color as it moves; draw a color gradient; plot your
  initials.

### Lesson 5 — Motion and collision
- **Goal:** make things move on their own and react to walls.
- **You'll learn:** representing **velocity** as a per-axis delta (`+1`/`−1`, stored as
  `$01`/`$FF`); advancing position every frame; detecting a wall hit with `CMP` and
  **reflecting** (flip the delta); pacing the loop so it's watchable; the erase-old /
  draw-new pattern applied to a moving object.
- **You'll build:** a ball that bounces around the lo-res field; a keypress nudges it.
- **Program:** `codegen/programs/tut5_bounce.s`.
- **Verified by:** running N frames headlessly and asserting the ball bounced (position /
  direction changed as expected).
- **Make it yours:** add gravity; speed the ball up on each bounce; add a second ball.

### Lesson 6 — Randomness and scoring
- **Goal:** add the two things that make a game a game — surprise and a score.
- **You'll learn:** why you need pseudo-randomness and how a tiny **LFSR** produces it
  (the `seedL`/`seedH` trick from `snake.s`); mapping a random byte into a field
  coordinate; spawning food and re-spawning it when eaten; simple "am I standing on it?"
  collision; incrementing a score and updating the HUD digits from Lesson 2.
- **You'll build:** a player block that chases randomly-placed food; each pickup scores
  and respawns the food.
- **Program:** `codegen/programs/tut6_catch.s`.
- **Verified by:** a fixed seed → deterministic food positions → scripted moves reach a
  known score.
- **Make it yours:** add a countdown timer; make some food worth more; add a "bad" cell to
  avoid.

### Lesson 7 — A complete game: Space Invaders
- **Goal:** assemble everything so far into a finished, replayable arcade game.
- **You'll learn:** a simple **game-state machine** (title → play → game-over → restart);
  driving a **formation** of invaders that marches side to side, drops a row at the edges,
  and speeds up as its ranks thin; a player cannon and a bullet that travels up the field
  (Lesson 5's motion); bullet-vs-invader and invader-vs-cannon collision (Lesson 6's
  collision); score and lives on the text HUD; a title screen and a restart key. It's built
  in **lo-res**, so every technique carries straight over from Lessons 4–6.
- **You'll build:** Space Invaders — slide a cannon along the bottom and clear a marching
  block of invaders before they reach you.
- **Program:** `codegen/programs/tut7_invaders.s`.
- **Verified by:** scripted play — a fired shot removes an invader and bumps the score;
  letting the formation reach the cannon triggers game-over.
- **The full version:** afterward you'll be able to read the shipped, hi-res
  [`swarm.s`](../../emulator/AICodeGen/swarm/swarm.s) (STAR SWARM) — the same game grown up
  with destructible shields, a bonus saucer, and hi-res sprites.
- **Make it yours:** add shields; a bonus saucer; let the invaders shoot back.

### Lesson 8 — Hi-res and beyond
- **Goal:** peek at the high-resolution screen and point the way to bigger projects.
- **You'll learn:** switching to **hi-res** (`$C057`, page 1 at `$2000`); the
  7-dots-per-byte layout and why hi-res math is trickier than lo-res; precomputing a
  192-entry **row-address table** so the interleaved memory map is a non-issue; plotting
  dots without ever dividing an X coordinate by 7.
- **You'll build:** a hi-res starfield with three rulers (with a twinkle as an exercise).
- **Program:** `codegen/programs/tut8_hires.s`.
- **Verified by:** asserting lit pixels in the hi-res page.
- **Where to go next:** a guided reading list of the shipped hi-res games — `swarm` (the
  hi-res Space Invaders you just built a lo-res version of), `rocks` (vector shooter), and
  `jungle` (platformer) — mapped to the concepts each one will teach you.

---

## Conventions used throughout

- **Assembler dialect:** the project's own `asm6502.mjs` (see the
  [code-generation guide](../../codegen/platform/prompt-system.md)). Labels `name:`,
  equates `NAME = expr`, `.org`, `.byte`/`.word`, `$hex`/`%bin`/`'c'`, `<`/`>` for
  low/high byte. Symbols are **case-insensitive** — the series keeps constant names
  distinct from variable names (a real footgun documented in the guide).
- **Program naming:** `tutN_shortname.s`, all in `codegen/programs/` so they auto-stage
  and each gets a `?src=programs/tutN_shortname.s` deep link.
- **Load address:** `$0800` unless a lesson says otherwise.
- **Every program is verified** with `run6502.mjs` before it ships in a lesson.

## Not covered (and why)

- **Sound** — kept out of the core arc until the emulator's audio path is confirmed
  end-to-end; a bonus lesson can be added if/when it's a first-class feature.
- **Disk / SD file I/O** — orthogonal to game logic; the browser's Load/Share flow covers
  distribution.
- **Deep hi-res techniques** (shape tables, page-flipping, precise color) — Lesson 8 opens
  the door and hands off to the shipped hi-res games as worked examples.

## Decisions (from review)

Locked in with ebadger:

1. **Scope:** 8 lessons.
2. **Capstone (Lesson 7):** **Space Invaders**, built in lo-res; the shipped hi-res
   [`swarm.s`](../../emulator/AICodeGen/swarm/swarm.s) is the "full version" to read next.
3. **Website surfacing:** add a **Tutorials** entry point on the live site
   (<https://ebadger.github.io/3ric/>) and a **Tutorials** optgroup in the Assemble & Run
   editor's sample picker, so each lesson's program is one click away. Each `tutN_*.s`
   auto-stages via `web/build.ps1`; the picker and entry point are wired in
   `web/index.html`.
4. **Teaching depth:** keep the **just-in-time** approach — introduce each 6502 concept in
   the lesson that first needs it; no separate up-front primer lesson.

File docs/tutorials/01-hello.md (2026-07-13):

# Lesson 1 — Hello, 3ric

> **You'll build:** your first 65C02 program — it clears the screen and prints two lines.
> **New ideas:** the assemble-and-run loop, the CPU's registers, printing with a ROM
> routine, and a simple loop.
> **Program:** [`codegen/programs/tut1_hello.s`](../../codegen/programs/tut1_hello.s) ·
> **▶ Run it:** <https://ebadger.github.io/3ric/?src=programs/tut1_hello.s>

---

## 1. The idea

A 3ric program is just a list of bytes placed in memory that the CPU then executes, one
instruction at a time. To get *anything* on screen we need three things:

- **Registers** — the CPU's tiny built-in variables. We'll use **A** (the *accumulator* —
  where values pass through) and **X** (an *index/counter*). Each holds one byte, `0`–`255`.
- **A way to print** — the machine's ROM already contains a routine called **`COUT`** (at
  address `$FDED`) that takes whatever byte is in **A** and prints it as a character. We
  just hand it a letter and call it.
- **A loop** — to print a whole word we step through its letters one at a time, printing
  each, until we hit a marker that says "stop."

That's the entire program: *put a letter in A, call `COUT`, move to the next letter,
repeat.*

> **Hex, quickly.** Addresses and bytes are written in hexadecimal with a `$` prefix.
> `$FDED` is just a memory address; `$C8` is just the number 200. You never have to do hex
> math by hand — the assembler does it for you.

## 2. The code

Here's the whole program. Read the comments top to bottom — every instruction is
introduced the first time it appears.

```asm
        .org $0800          ; Load + run address. A .PRG starts executing here.

COUT    = $FDED             ; print the character in A to the screen (+ serial)
HOME    = $FC58             ; clear the text screen, cursor to the top-left

        jsr HOME            ; start on a clean screen

        ldx #0              ; X walks through the message, one byte at a time
print:  lda msg,x           ; A = the X-th byte of msg   (LDA addr,X = "indexed")
        beq done            ; a 0 byte marks the end of the text -> finished
        jsr COUT            ; print the character now in A
        inx                 ; advance to the next byte
        bne print           ; loop back (BNE is always taken until X would wrap)

done:   brk                 ; hand control back to the monitor: program finished

msg:
        .byte $C8,$C5,$CC,$CC,$CF,$AC,$A0      ; "HELLO, "
        .byte $B3,$D2,$C9,$C3                  ; "3RIC"
        .byte $8D                              ; new line
        .byte $CC,$C5,$D4,$A7,$D3,$A0          ; "LET'S "
        .byte $CD,$C1,$CB,$C5,$A0              ; "MAKE "
        .byte $C7,$C1,$CD,$C5,$D3,$AE          ; "GAMES."
        .byte $8D,$00                          ; new line, end marker
```

### Line by line

- **`.org $0800`** — a *directive* (an instruction to the assembler, not the CPU). It says
  "assemble this to run at address `$0800`." On the 3ric, a program is loaded at its `.org`
  and execution begins there, so **the load address is the entry point**. `$0800` is a
  convenient chunk of free RAM.
- **`COUT = $FDED`** / **`HOME = $FC58`** — *equates*: names for addresses so the code reads
  in English instead of hex. These two live in the ROM; their addresses come from the
  [platform reference](../../codegen/platform/platform-ref.md).
- **`jsr HOME`** — *Jump to SubRoutine*. It calls the ROM's screen-clear routine and comes
  back. `jsr` is how you call reusable code.
- **`ldx #0`** — *LoaD X* with the number `0`. The **`#`** means "the literal value 0"
  (this is *immediate* addressing). Without `#`, `ldx 0` would mean "load X from *memory
  address* 0" — a completely different thing. This is the most common beginner mix-up.
- **`print:`** — a *label*, a name for this spot in the code so we can branch back to it.
- **`lda msg,x`** — *LoaD A* from address `msg` **plus X**. When `X = 0` it reads the first
  byte of the message; when `X = 1`, the second; and so on. This `addr,X` form is *indexed*
  addressing — the workhorse of table and string handling.
- **`beq done`** — *Branch if EQual (to zero)*. `lda` sets the CPU's "zero" flag when the
  value it loaded was `0`, so this reads as "if we just loaded the `$00` end-marker, jump to
  `done`."
- **`jsr COUT`** — print the character currently in A.
- **`inx`** — *INcrement X* (add 1). Now `msg,x` points at the next letter.
- **`bne print`** — *Branch if Not Equal (to zero)*. `inx` leaves the zero flag clear for
  every value except when X rolls from 255 back to 0, so in practice this always loops back
  to `print`. The loop ends via the `beq done` above, not here.
- **`brk`** — stops the program and returns to the ROM **monitor**. It's the standard "I'm
  done" signal on the 3ric. (Don't use `rts` at the top level — there's no caller to return
  to.)

### Why the funny numbers?

`COUT` expects each character as **ASCII with the high bit set**. Normal ASCII `'H'` is
`$48`; setting the top bit gives `$48 + $80 = $C8`. So the message is spelled out in
high-bit bytes. `$8D` is a carriage return (`$0D | $80`) — it starts a new line. The
trailing **`$00`** is our own end-marker that `beq done` watches for.

You don't have to memorize the codes — later lessons let the assembler compute them for you
— but seeing them once makes the "high bit set" rule concrete.

## 3. Run it

**In the browser (easiest):** open
<https://ebadger.github.io/3ric/?src=programs/tut1_hello.s>. The page loads the source into
the **Assemble & Run** editor, assembles it in your browser with the very same assembler the
project uses, and runs it. You should see:

```
HELLO, 3RIC
LET'S MAKE GAMES.
```

Edit the text in the editor and press **Assemble & Run** again to see your change instantly.

**Headless (if you've cloned the repo):** the toolchain can run the program and *check* its
output, which is exactly how this lesson's code was verified:

```sh
node codegen/tools/run6502.mjs codegen/programs/tut1_hello.s \
    --expect-serial "HELLO, 3RIC" --expect-halt brk-monitor
```

`VERDICT: PASS` means the program halted cleanly and printed what we expected.

## 4. What just happened

After the two lines print, `brk` returns to the monitor, which prints a line like:

```
0812-    A=00 X=1E Y=00 P=32 S=EC
*
```

That's not your program — it's the **monitor** reporting the CPU's registers at the moment
you stopped, then showing its `*` prompt. Notice `X=1E` (that's 30 in decimal): X counted up
once per byte as the loop walked the whole 30-byte message. Seeing the registers "freeze" at
`brk` is a handy debugging habit we'll use again.

## 5. Make it yours

1. **Change the greeting.** Replace `"3RIC"` with your name. You'll need the high-bit codes:
   take normal ASCII and add `$80`, or just reuse the letters already in the message.
2. **Add a third line.** Insert another `$8D` and a few more letter bytes before the final
   `$00`.
3. **Print it twice.** Wrap the loop so it runs the whole message a second time. (Hint: keep
   a second counter, or reset `X` and jump back to `print` once.)
4. **Break it on purpose.** Delete the final `$00` and run it. What happens, and why? (Think
   about what `beq done` is now waiting for.)

## Next

You printed characters by *asking the ROM* to do it. In
**[Lesson 2 — Drawing on the text screen](02-text-screen.md)** you'll skip `COUT` and write
letters straight into screen memory yourself — the foundation of drawing anything, anywhere.

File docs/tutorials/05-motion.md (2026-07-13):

# Lesson 5 — Motion and collision

> **You'll build:** a ball that moves by itself and bounces off all four walls.
> **New ideas:** the *game loop*; velocity; reflecting off boundaries; a delay for timing.
> **Program:** [`codegen/programs/tut5_bounce.s`](../../codegen/programs/tut5_bounce.s) ·
> **▶ Run it:** <https://ebadger.github.io/3ric/?src=programs/tut5_bounce.s>

---

## 1. The idea

Every game up to now moved something *only when you pressed a key*. Action games are
different: things move **on their own, every frame**. That "do a little bit, over and over,
forever" heartbeat is the **game loop**.

To move on its own, the ball needs a **velocity** as well as a position. We store four bytes:

```asm
bx = $06   ; position X, Y
by = $07
vx = $08   ; velocity X: $01 = right, $FF = left
vy = $09   ; velocity Y: $01 = down,  $FF = up
```

We use `$01` and `$FF` for the velocities because on the 6502 adding `$FF` is the same as
subtracting 1 (it wraps). So "move" is just `pos = pos + vel` — one add handles both
directions. The trick is stopping the ball from wrapping *past* a wall, which is where
**collision** comes in.

## 2. The code

### The loop skeleton

```asm
loop:   lda KBD             ; non-blocking quit check (don't wait!)
        bpl move
        bit KBDSTRB
        and #$7F
        cmp #'Q'
        beq quit

move:   jsr eraseball       ; 1. rub out the old ball
        ;   ... update X, then Y (below) ...
draw:   jsr drawball        ; 2. draw it at the new spot
        jsr delay           ; 3. pause so the eye can follow
        bra loop            ; 4. forever
```

Notice the key check uses `bpl move` and falls straight through — it **never waits**. If no
key is down we just keep animating. That's the difference between an *event* loop (Lesson 3)
and a *game* loop.

### Bouncing off a wall

For each axis: if we're heading toward a wall and already at it, flip the velocity and step
*away*; otherwise step normally. Here's X:

```asm
        lda vx
        bmi xneg            ; heading left?
        lda bx              ; heading right:
        cmp #XMAX
        bcc xinc            ;   not at the wall -> just move
        lda #$FF            ;   at right wall -> reverse
        sta vx
        dec bx
        bra ymove
xinc:   inc bx
        bra ymove
xneg:   lda bx              ; heading left:
        beq xflip           ;   at left wall (0) -> reverse
        dec bx
        bra ymove
xflip:  lda #$01
        sta vx
        inc bx
```

The Y axis is the identical shape with `YMAX` (47) instead of `XMAX` (39). Reflecting a ball
is exactly this: when it reaches an edge, negate the velocity on that axis. Horizontal and
vertical bounces are independent, which is why a corner hit reverses *both*.

### Timing

Computers are fast — without a pause the ball would blur across the screen in an instant.
`delay` just burns time in a nested countdown:

```asm
delay:  ldx #$40
dl1:    ldy #$FF
dl2:    dey
        bne dl2
        dex
        bne dl1
        rts
```

Change `#$40` to make the ball slower or faster. This is a crude timer; later you'd sync to
the video frame, but a delay loop is perfect for learning.

## 3. Run it

Open <https://ebadger.github.io/3ric/?src=programs/tut5_bounce.s>. A white dot sails from the
top-left, bounces around the box, and keeps going until you press **Q**.

Because the ball never stops on its own, we verify it with a **fixed cycle budget** instead of
waiting for a halt (that's what `verify_run.cjs` does — run exactly *N* cycles, then look):

```sh
node codegen/tools/verify_run.cjs codegen/programs/tut5_bounce.s 0x0800 2000000 \
    0x06=0x0C 0x07=0x1C 0x08=0xFF 0x09=0xFF
```

After 2,000,000 cycles the ball has bounced off the **right** wall (`vx` is now `$FF` =
left) and the **bottom** (`vy` is now `$FF` = up), sitting at (12, 28) heading up-left.
Checking the velocity bytes flipped is a neat way to prove the collision code actually fired.

## 4. What just happened

You wrote your first real game loop: erase → update → draw → delay → repeat. You gave an
object a velocity and made it obey the walls. Every arcade game — Pong, Breakout, Asteroids —
is this same loop with more objects and smarter rules.

## 5. Make it yours

1. **Speed and angle.** Start `vx`/`vy` at different times, or change the delay, to feel how
   timing changes the game.
2. **Leave a trail.** Delete the `jsr eraseball` call and watch the ball paint the whole
   screen like a bouncing-lines screensaver.
3. **A paddle.** Bring back Lesson 3's input to move a 1-pixel-wide paddle along the bottom
   row with A/D, and make the ball reverse `vy` only when it hits the paddle's column —
   you've started Breakout.
4. **Two balls.** Add `bx2/by2/vx2/vy2` and a second draw/update. How little code does a
   second ball actually take?

## Next

A ball that bounces forever is hypnotic but it's not a *game* yet — nothing is random and
there's no score. In **[Lesson 6 — Randomness and scoring](06-random.md)** we add a random
target to catch and an on-screen score, mixing lo-res graphics with a text HUD.

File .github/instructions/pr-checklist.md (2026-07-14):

# PR Checklist

Before creating a PR, verify:

1. **PR status** — `gh pr view <N> --json state` → must be OPEN (if updating). If MERGED/CLOSED, branch from `origin/main` and open fresh.
2. **Upstream synced** — `git fetch origin main` done.
3. **Never self-merge** — Provide ebadger the PR link. Do not merge.
4. **All layers covered** — Data store / API / Client all updated if affected.
5. **Spec status marked** — Implementation status updated in the relevant spec.
6. **Tests pass** — All tests confirmed green.
7. **Status document** — If your changes affect runtime behavior (new endpoints, credentials, ports, scripts, schema changes, new services), update `status/SYSTEM-STATUS.md`.
8. **Second-model review (code/config PRs)** — For any PR that can change product or agent behaviour (application code, `specs/**`, schema/migrations, API contracts, client, config, build/deploy, or `.github/agents`·`.github/instructions`·hooks), run **both** independent reviewers on the diff (passing the `model` param explicitly), triage every finding (fix or record why-not), and apply the review-cost gate: ask ebadger about every **BLOCK** and any recommended fix estimated above one minute, presenting all options with end-to-end estimates and a recommendation before editing. Add the **## Second-model review** block to the PR body, and post the reviewers' verbatim output + a per-model `Scorecard` line as a PR comment. Sub-minute non-blocking fixes remain autonomous; non-product prose / comment-only / typo PRs are exempt. See `docs/CODE-REVIEW-PANEL.md`.

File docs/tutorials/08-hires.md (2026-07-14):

# Lesson 8 — Hi-res, and where to go next

> **You'll build:** a 280×192 hi-res starfield with three rulers, then get a map of the
> shipped games to study next.
> **New ideas:** hi-res mode and its interleaved row memory; precomputing an address table;
> reading real, finished 3ric games.
> **Program:** [`codegen/programs/tut8_hires.s`](../../codegen/programs/tut8_hires.s) ·
> **▶ Run it:** <https://ebadger.github.io/3ric/?src=programs/tut8_hires.s>

---

## 1. The idea

Lo-res gave us 40×48 chunky color. **Hi-res** gives us **280×192** — six times the detail —
and it's where the shipped 3ric games live. The trade-off is a stranger memory layout.

Hi-res page 1 is `$2000–$3FFF`. Each byte holds **7 horizontal pixels** (bits 0–6, bit 0 =
leftmost); bit 7 selects the color palette. So a full-width white line is `$7F` in every byte
across a row.

The catch is that **rows are interleaved** — row *y* is *not* simply `$2000 + y*40`. The
address is the famous Apple-II formula:

```
addr(y) = $2000 + (y & 7)*$400 + ((y>>3) & 7)*$80 + (y>>6)*$28
```

Computing that per pixel would be slow and error-prone, so we do it **once** into a 192-entry
lookup table and never think about it again.

## 2. The code

### Precomputing the row table

`build_rows` (lifted straight from the shipped `swarm.s`) fills `ROWL[y]`/`ROWH[y]` with the
low and high bytes of each row's address. We park those 192-byte tables in free RAM at
`$6000`/`$6100`, well clear of both our program (`$0800`) and the screen (`$2000`):

```asm
SCREEN  = $2000
ROWL    = $6000
ROWH    = $6100
```

After `jsr build_rows`, drawing to row *y* is just: read `ROWL/ROWH[y]` into a pointer, then
index by the byte column.

### A white line

```asm
hline:  tay
        lda ROWL,y          ; ptr = address of this pixel row
        sta ptr
        lda ROWH,y
        sta ptr+1
        ldy #39
        lda #$7F            ; all 7 pixels on
hl1:    sta (ptr),y
        dey
        bpl hl1
        rts
```

We call it for rows 0, 96, and 191 — top, middle, bottom rulers.

### A starfield without dividing by 7

To place a single pixel you normally need `column = x / 7` and `bit = x mod 7` — a division.
We sidestep it entirely: the starfield picks a **column (0–39)** and a **bit (0–6)** *directly*
from the RNG, so there's nothing to divide:

```asm
        jsr rndbit          ; A = a one-bit mask from BITMASK
        ldy col
        ora (ptr),y         ; OR it in (don't clobber nearby stars)
        sta (ptr),y
```

`BITMASK` is just `$01,$02,$04,$08,$10,$20,$40` — the seven pixel positions in a byte. Using
`ora` means each star lights its own pixel without erasing its neighbours.

> **Note the 65C02 touch:** the star loop uses `phx`/`plx` to save the counter across the
> subroutine calls — instructions the original 6502 didn't have. The 3ric is a 65C02, so
> they're fair game.

## 3. Run it

Open <https://ebadger.github.io/3ric/?src=programs/tut8_hires.s>: three crisp white lines and
a sprinkling of stars, at a resolution lo-res can't touch. **Q** returns to text.

Because the row table and pixel math are the whole point, we verify the rulers landed at the
*exact* interleaved addresses the formula predicts:

```sh
node codegen/tools/run6502.mjs codegen/programs/tut8_hires.s \
    --expect-mem 0x2000=0x7F --expect-mem 0x2228=0x7F \
    --expect-mem 0x3FD0=0x7F --expect-halt idle
```

Row 0 → `$2000`, row 96 → `$2228`, row 191 → `$3FD0`. If `build_rows` were even one bit off,
these would miss.

## 4. Where to go next

You now have the whole toolkit: text and lo-res and hi-res video, input, the game loop,
motion, collision, randomness, score, and state machines. The best next step is to **read
finished games** and modify them. They all live in `emulator/AICodeGen/` and run in the same
browser emulator (open one from the editor's sample picker):

| Game | File | What it teaches |
| --- | --- | --- |
| **Star Swarm** | `swarm/swarm.s` | The hi-res Space Invaders this series builds toward — sprite blitting, a HUD, bombs, a saucer. The "full version" of Lesson 7. |
| **Rock Storm** | `rocks/rocks.s` | Asteroids-style vector drawing, rotation, thrust, and wrap-around motion. |
| **Jungle Quest** | `jungle/jungle.s` | A six-screen hi-res platformer: fixed-point gravity, buffered/coyote jumps, one-way platforms, descriptor-driven terrain, sprite restoration, and AABB collision. |
| **Brick Buster** | `bricks/bricks.s` | Breakout in text mode — a compact take on ball/paddle/brick collision. |
| **Paddles** | `paddles/paddles.s` | Two-player Pong; the simplest place to study game *rules* and scoring. |
| **Minefield** | `mines/mines.s` | Minesweeper — grids, flood fill, and mouse-free cursor UI. |
| **Life** | `life/life.s` | Conway's Game of Life: neighbour counting and double-buffering. |
| **2048** | `2048/2048.s` | Sliding-tile logic and merging in a 4×4 grid. |

And the two reference docs that describe the machine precisely:

- [`codegen/platform/platform-ref.md`](../../codegen/platform/platform-ref.md) — the memory
  map, soft switches, and ROM entry points.
- [`codegen/platform/prompt-system.md`](../../codegen/platform/prompt-system.md) — the
  assembler dialect and calling conventions.

## 5. Make it yours

1. **Twinkle.** In the `spin` loop, plot one fresh random star per frame with a small delay so
   the field slowly fills.
2. **A box, not lines.** Add left/right edges (bit `$01` in column 0, `$40` in column 39, down
   every row) to frame the screen.
3. **A moving dot.** Track a star's `col` and `bit`; each frame shift the bit left, and when it
   passes bit 6 reset it to bit 0 and `inc col`. You've handled the /7 boundary by hand.
4. **Port a lo-res lesson.** Re-draw Lesson 5's bouncing ball in hi-res using this `plot`
   approach — the game logic doesn't change, only the drawing.

## The end

That's the series: from `HELLO` to Space Invaders to hi-res. You've written eight real
programs and verified every one on the actual machine. Now open a shipped game, change a
number, and see what happens — that's how everyone learned. Have fun.

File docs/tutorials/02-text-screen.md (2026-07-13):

# Lesson 2 — Drawing on the text screen

> **You'll build:** a titled, bordered "game screen" with a score/lives HUD — drawn by
> writing straight into screen memory.
> **New ideas:** the text screen *is* memory at `$0400`; rows are interleaved; zero-page
> pointers; indirect-indexed addressing; ending with a loop instead of `BRK`.
> **Program:** [`codegen/programs/tut2_screen.s`](../../codegen/programs/tut2_screen.s) ·
> **▶ Run it:** <https://ebadger.github.io/3ric/?src=programs/tut2_screen.s>

---

## 1. The idea

In Lesson 1 we asked the ROM to print for us. Games can't afford that — they draw thousands
of cells per second, anywhere on screen. So we write **directly to screen memory**.

The text screen lives at **`$0400`–`$07FF`**. Each byte is one of the 40×24 character
cells. Store a character code into one of those bytes and it appears instantly.

Two things you must know to place a character:

- **Normal video means the high bit is set.** Just like `COUT`, screen memory shows `'A'`
  as `$C1` (`$41 | $80`), not `$41`. (Codes `$00`–`$7F` show as inverse/flashing — a bonus
  at the end.)
- **Rows are not stored back-to-back.** Row 0 is the 40 bytes `$0400`–`$0427`. You'd expect
  row 1 at `$0428` — but it's actually at **`$0480`**. The rows are *interleaved* for
  hardware reasons. Rather than fight the formula, we keep a small **table** of each row's
  start address and look it up.

## 2. The code

The program clears the screen, draws the border, then stamps the title and HUD. The full
listing (including the 24-entry row tables) is in the source file; here are the important
pieces.

**A zero-page pointer to a row.** `setrow` copies a row's base address out of the tables
into `sptr` (two bytes in zero page). Once `sptr` holds an address, `sta (sptr),y` stores
into "the byte `Y` columns into that row" — this is **indirect-indexed** addressing, the
tool you'll use for almost all drawing.

```asm
sptr    = $08               ; a 2-byte pointer living in zero page

setrow: lda ROWL,x          ; X = row number (0..23); look up its base address
        sta sptr            ;   low byte
        lda ROWH,x
        sta sptr+1          ;   high byte
        rts
```

**Filling a row** walks the 40 columns with `Y` as the column index:

```asm
fillrow: ldy #39
        lda #BORDER         ; '#', already high-bit ($A3)
fr:     sta (sptr),y        ; screen[row base + Y] = '#'
        dey
        bpl fr              ; ...down to column 0 (BPL = "branch while >= 0")
        rts
```

**Drawing a string** (`puts`) slides `sptr` right to the start column, then copies bytes
until the `0` terminator, setting the high bit on each so the text is normal video:

```asm
puts:   clc
        adc sptr            ; sptr = row base + start column (passed in A)
        sta sptr
        bcc pnc
        inc sptr+1
pnc:    ldy #0
pl:     lda (strp),y        ; next character of the string
        beq pdone           ; 0 ends it
        ora #$80            ; force normal video
        sta (sptr),y        ; place it on screen
        iny
        bne pl
pdone:  rts
```

The strings themselves are readable text — `puts` adds the high bit, so we don't hand-encode
like we did in Lesson 1:

```asm
title:  .asciiz "3RIC ADVENTURE"     ; .asciiz = the bytes, then a 0 terminator
hud:    .asciiz "SCORE:000  LIVES:3"
```

### New instructions and ideas

- **`sta (sptr),y` (indirect-indexed).** Take the 16-bit address stored in the zero-page
  pair `sptr`/`sptr+1`, add `Y`, and store there. This is how you point at *any* address
  computed at run time. (In Lesson 1, `lda msg,x` used a *fixed* address `msg`; here the
  address is a variable.)
- **`<label` / `>label`.** The low and high byte of an address. `lda #<title` /
  `lda #>title` loads `title`'s address into a pointer.
- **`bpl` / `dey`.** `dey` counts `Y` down; `bpl` ("branch if plus") loops while `Y` is still
  0 or more, so the fill runs column 39 → 0.
- **The row tables** `ROWL`/`ROWH` are just 24 low bytes and 24 high bytes — the interleaved
  start address of every text row, looked up with `lda ROWL,x`.

### Why it ends with a loop, not `brk`

Lesson 1 finished with `brk`, which hands control back to the monitor — and the monitor
immediately prints its register dump *over your screen*. A program that draws something
wants the picture to **stay up**, so instead we spin in place:

```asm
spin:   bra spin            ; loop here forever; the drawing remains on screen
```

The headless runner reports this as `halt: idle` — a normal, clean stop. Every visual
program from here on ends this way, and in Lesson 3 that idle loop becomes the **game loop**.

## 3. Run it

Open <https://ebadger.github.io/3ric/?src=programs/tut2_screen.s>. You should see a boxed
screen with `3RIC ADVENTURE` centered near the top and `SCORE:000  LIVES:3` near the bottom.

To verify headlessly, assert a few screen bytes (note the `0x` prefixes):

```sh
node codegen/tools/run6502.mjs codegen/programs/tut2_screen.s \
    --expect-mem 0x0400=0xA3 --expect-mem 0x050D=0xB3 --expect-halt idle
```

`mem[$0400]==$A3` confirms the top-left border cell; `mem[$050D]==$B3` confirms the `'3'` of
the title landed at row 2, column 13.

## 4. What just happened

You computed addresses at run time and wrote characters into them — the whole basis of
drawing. `setrow` + `(sptr),y` is a *put-character-anywhere* primitive; `fillrow` and `puts`
are built on top of it. Everything visual in this series (even the lo-res blocks in Lesson 4)
is the same move: figure out the address of a cell, store a byte.

## 5. Make it yours

1. **Rename the game.** Change the `title` string. If it isn't 14 characters, adjust the
   start column (`lda #13`) so it stays centered: `col = (40 − length) / 2`.
2. **Move the HUD.** Draw it on a different row by changing the `ldx #21` before the HUD
   block. (Watch the row tables do the work.)
3. **Add a subtitle** on row 4 — a second string, a second `puts` call.
4. **Try inverse video.** Store a letter code *without* the high bit (e.g. `$01` for an
   inverse `A`, or `$20` for a solid inverse block) and see it flip to a black-on-white
   cell. Make an inverse title bar out of solid blocks.

## Next

The screen is drawn, but nothing moves. In
**[Lesson 3 — Input and the game loop](03-input.md)** we read the keyboard and turn that
`spin` loop into a real game loop that walks a hero around this box.

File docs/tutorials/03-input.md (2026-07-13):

# Lesson 3 — Input and the game loop

> **You'll build:** a hero `@` you walk around the box with the keyboard.
> **New ideas:** reading the keyboard at `$C000`/`$C010`; the read→update→draw loop;
> comparing keys and branching; erase-then-draw; keeping inside bounds.
> **Program:** [`codegen/programs/tut3_move.s`](../../codegen/programs/tut3_move.s) ·
> **▶ Run it:** <https://ebadger.github.io/3ric/?src=programs/tut3_move.s>

---

## 1. The idea

Every game, from Pong to Zelda, runs the same loop forever:

```
READ input  →  UPDATE the world  →  DRAW the result  →  (repeat)
```

Lesson 2's `spin: bra spin` was that loop with the middle scooped out. Now we fill it in.

**Reading the keyboard** is two memory locations:

- **`$C000`** holds the last key. Its **bit 7** is a "a key is ready" flag: `1` when a fresh
  key is waiting, `0` when you've already consumed it. The low 7 bits are the ASCII code.
- **`$C010`** is the *strobe clear*. Touching it (any read) lowers bit 7 so you can detect
  the **next** press instead of reading the same key over and over.

So "get a key" is: wait until bit 7 of `$C000` is set, clear the strobe, and strip bit 7 to
get plain ASCII.

## 2. The code

### The loop

```asm
loop:   lda KBD             ; READ: bit 7 set means a key is waiting
        bpl loop            ;   not yet -> poll again (BPL = "branch if bit 7 clear")
        bit KBDSTRB         ;   clear the strobe (ready for the next press)
        and #$7F            ;   drop bit 7 -> plain ASCII in A
```

`bpl` ("branch if plus") tests bit 7: while it's clear the key isn't ready, so we loop. Once
a key arrives we clear the strobe with `bit KBDSTRB` (any access to `$C010` does it) and mask
off the ready bit.

### Dispatch on the key

We compare the key against each control and branch to a handler. `cmp #'W'` subtracts `'W'`
from A just to set the flags; `beq up` takes the branch when they matched.

```asm
        cmp #'W'
        beq up
        cmp #'S'
        beq down
        cmp #'A'
        beq left
        cmp #'D'
        beq right
        ; ...arrow-key codes handled the same way...
        bra redraw          ; unrecognized key: don't move
```

### Update with bounds, then draw

Before moving, we make sure the hero stays inside the border. `cmp #2` / `bcc` reads as "if
`hy` is below 2, skip" — a compare-and-branch is how you do "if less than" on the 6502.

```asm
up:     lda hy
        cmp #2
        bcc redraw          ; hy < 2  ->  already at the top, don't move
        dec hy
        bra redraw
```

Each frame we **erase the hero at its old cell, then draw it at the new one** — otherwise it
would leave a trail:

```asm
        pha                 ; keep the key while we erase
        lda #SPACE
        jsr putcell         ; blank the old cell
        pla
        ; ...update hx/hy...
redraw: lda #HERO
        jsr putcell         ; stamp the hero at the new cell
        bra loop
```

### The drawing primitive

`putcell` is Lesson 2's idea boiled down to one routine: *put the character in A at
`(hy, hx)`.* It looks the row base up in the tables and stores through the `sptr` pointer.

```asm
putcell: ldy hx
        ldx hy
        pha
        lda ROWL,x          ; sptr = base of row hy
        sta sptr
        lda ROWH,x
        sta sptr+1
        pla
        sta (sptr),y        ; screen[row hy, column hx] = A
        rts
```

Only `hx`/`hy` change from frame to frame; `putcell` turns them into the right screen
address every time.

## 3. Run it

Open <https://ebadger.github.io/3ric/?src=programs/tut3_move.s> and drive the `@` with
**W/A/S/D** (arrow keys work too). It won't walk through the border. Press **Q** to quit
back to the monitor.

Because keypresses are interactive, this program is verified two ways. The starting frame is
checked headlessly:

```sh
node codegen/tools/run6502.mjs codegen/programs/tut3_move.s \
    --expect-mem 0x063C=0xC0 --expect-halt idle
```

`mem[$063C]==$C0` confirms the `@` starts at row 12, column 20. The *movement* is checked by
a script that types keys and asserts the hero's `(hx, hy)` afterward — typing `DDDDSSWW`
lands it at column 24, row 12, exactly where it should be.

## 4. What just happened

You built the skeleton every later lesson hangs things on:

- **poll** for input (`$C000` / `$C010`),
- **decide** what it means (`cmp` + branch),
- **change state** with bounds (`hx`, `hy`),
- **redraw** the changed cells,
- **loop**.

Notice we only redraw the two cells that changed (erase old, draw new) — never the whole
screen. That "touch only what moved" habit is what keeps 1 MHz games smooth.

## 5. Make it yours

1. **Diagonals.** Add handlers so `Q`/`E`/`Z`/`C` move two axes at once. (Careful: you're
   already using `Q` to quit — pick free keys.)
2. **Wrap around.** Instead of stopping at the border, make leaving the right edge reappear
   on the left (set `hx` to 1 instead of blocking at 38).
3. **Leave a trail.** Skip the erase step and watch the hero paint the screen. Add a key
   that clears it (`jsr HOME` then redraw the border).
4. **Speed vs. wait.** Right now the loop *blocks* until a key is pressed. In Lesson 5 the
   loop will run every frame whether or not a key is down — peek ahead and think about why a
   game needs that.

## Next

Text is great, but games want color. In
**[Lesson 4 — Color with lo-res graphics](04-lores.md)** we flip the machine into lo-res
mode and write a `PLOT` routine that lights up colored blocks.

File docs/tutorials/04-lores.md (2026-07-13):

# Lesson 4 — Color with lo-res graphics

> **You'll build:** a 16-color palette and a color-cycling block you steer around the screen.
> **New ideas:** soft switches to change video mode; the lo-res memory layout (two pixels per
> byte); a reusable `PLOT` routine; 16 colors.
> **Program:** [`codegen/programs/tut4_lores.s`](../../codegen/programs/tut4_lores.s) ·
> **▶ Run it:** <https://ebadger.github.io/3ric/?src=programs/tut4_lores.s>

---

## 1. The idea

So far we've been in text mode. The 3ric can also show **lo-res graphics**: a 40×48 grid of
chunky blocks in **16 colors**. Same screen memory (`$0400`), different interpretation.

**Switching modes** is done with *soft switches* — special addresses in the `$C05x` range.
You don't store a value; you just *touch* the address (any read) and the hardware flips. Four
touches put us in full-screen lo-res:

```asm
        lda TXTCLR          ; $C050 graphics on (text off)
        lda FULLSCR         ; $C052 full screen (no text window)
        lda LORES           ; $C056 lo-res
        lda LOWSCR          ; $C054 show page 1
```

**The lo-res memory layout** is the one thing to wrap your head around. Lo-res *reuses* the
text page, and each screen byte holds **two stacked pixels**:

- the **low nibble** (bottom 4 bits) is the **upper** pixel,
- the **high nibble** (top 4 bits) is the **lower** pixel.

Because two vertical pixels share one byte, a lo-res row `Y` lives in **text row `Y / 2`**.
To light one pixel we look up that text row, then change *just one nibble* of the byte —
leaving its neighbor alone. A nibble holds `0`–`15`: the color.

## 2. The code

### PLOT — the one routine that matters

```asm
plot:   lda py
        lsr a               ; text row = py / 2
        tax
        lda ROWL,x          ; sptr = base of that text row
        sta sptr
        lda ROWH,x
        sta sptr+1
        ldy px
        lda py
        and #1
        bne plodd
        lda (sptr),y        ; even Y -> keep high nibble, set LOW nibble
        and #$F0
        ora pcolor
        sta (sptr),y
        rts
plodd:  lda pcolor          ; odd Y -> keep low nibble, set HIGH nibble
        asl a               ; color << 4 moves it into the high nibble
        asl a
        asl a
        asl a
        sta ptmp
        lda (sptr),y
        and #$0F
        ora ptmp
        sta (sptr),y
        rts
```

The pattern is **read-modify-write**: load the byte, mask off the half we're changing (`and
#$F0` keeps the high nibble; `and #$0F` keeps the low), OR in the new color, store it back.
`lsr a` divides `py` by 2 to find the text row; `and #1` tells us which nibble.

With `plot` in hand, everything else is just *calling it in loops*.

### Drawing the palette

Sixteen colors, drawn as a 16-wide × 4-tall band, color equal to the column offset:

```asm
        lda #4
        sta py
prow:   lda #12
        sta px
pcol:   lda px
        sec
        sbc #12
        sta pcolor          ; color = px - 12  (0..15)
        jsr plot
        inc px
        lda px
        cmp #28
        bne pcol
        inc py
        lda py
        cmp #8
        bne prow
```

### The player, reusing Lesson 3's loop

The game loop is exactly Lesson 3's — poll the key, erase, move, redraw — but now "draw"
means `plot` a colored block, and every step cycles the color:

```asm
redraw: inc plcol           ; cycle the color, skipping black (0)
        lda plcol
        cmp #16
        bne rdok
        lda #1
        sta plcol
rdok:   jsr drawplayer
        bra loop
```

> **A subtle gotcha.** We clear the keyboard strobe with **`bit KBDSTRB`**, not `lda
> KBDSTRB`. Both touch `$C010`, but `lda` would overwrite the key we *just* read into `A`.
> `bit` clears the strobe while leaving `A` alone. (This one bites everybody once.)

`clrscreen` blanks the field by storing `0` across all four pages of `$0400`–`$07FF` — black
is color `0`, so zero-fill is a clear screen.

## 3. Run it

Open <https://ebadger.github.io/3ric/?src=programs/tut4_lores.s>. You'll see the palette
strip near the top and a white block in the middle. **W/A/S/D** moves it and it changes color
as it goes; **Q** returns to text and the monitor.

Headless verification checks two plotted bytes:

```sh
node codegen/tools/run6502.mjs codegen/programs/tut4_lores.s \
    --expect-mem 0x050F=0x33 --expect-mem 0x063C=0x0F --expect-halt idle
```

`mem[$050F]==$33` is a palette cell where both stacked pixels are color 3 (`$3` in each
nibble); `mem[$063C]==$0F` is the white (`$F`) player block. (In the harness's *text* decode
these bytes look like gibberish — that's just color data being shown as characters.)

## 4. What just happened

You changed the machine's video mode with a few memory touches, and you wrote the single
primitive — `plot(x, y, color)` — that every lo-res game is built from. Notice how little new
there is: the loop, the erase/redraw, the bounds checks all came straight from Lesson 3. Only
the *drawing* changed.

## 5. Make it yours

1. **Bigger player.** Draw the player as a 2×2 block (four `plot` calls at `x,y`, `x+1,y`,
   `x,y+1`, `x+1,y+1`). Remember to erase all four.
2. **Paint mode.** Remove the erase step and hold a direction to draw lines — an
   Etch-A-Sketch.
3. **Pick your color.** Instead of auto-cycling, map number keys `1`–`8` to set `plcol`
   directly.
4. **A framed arena.** Before the loop, `plot` a border of color 5 (grey) around the field,
   and add bounds so the player can't cross it (compare against 1 and 38 like Lesson 3).

## Next

The player only moves when you press a key. Real action games move things *every frame*. In
**[Lesson 5 — Motion and collision](05-motion.md)** we give a ball its own velocity and make
it bounce off the walls on its own.

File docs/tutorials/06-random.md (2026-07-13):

# Lesson 6 — Randomness and scoring

> **You'll build:** a catch-the-food game with random targets and a live score.
> **New ideas:** mixed graphics+text mode; a pseudo-random number generator; collision by
> comparison; drawing a decimal number.
> **Program:** [`codegen/programs/tut6_catch.s`](../../codegen/programs/tut6_catch.s) ·
> **▶ Run it:** <https://ebadger.github.io/3ric/?src=programs/tut6_catch.s>

---

## 1. The idea

Two things separate a *toy* from a *game*: a goal that isn't the same every time (randomness)
and feedback that you're winning (a score). This lesson adds both.

We also want the score *visible*. The 3ric can show a **mixed** screen — lo-res graphics on
top with a **four-line text window** across the bottom — by touching one soft switch:

```asm
        lda TXTCLR          ; graphics on
        lda MIXSET          ; $C053 mixed: lo-res + 4 text rows at the bottom
        lda LORES
        lda LOWSCR
```

Now the top of the screen (lo-res rows 0–39) is our playfield and text rows 20–23 are a HUD.

## 2. The code

### Random numbers with an LFSR

There's no "random" instruction, so we make our own with a **linear-feedback shift register**
— shift the bits and, on certain shifts, flip a fixed pattern. It cycles through 255 values in
a scrambled order that *looks* random:

```asm
rng:    lda seed
        lsr a               ; shift right
        bcc rnods           ; if the bit that fell off was 1...
        eor #$B8            ; ...flip the "tap" bits
rnods:  sta seed
        rts
```

Seed it with any non-zero value and each call returns the next number. It's completely
deterministic (great for testing) but unpredictable enough for a game.

We need a coordinate in 0–39, but `rng` gives 0–255. **Rejection sampling** is the honest
way: mask to 0–63 and just re-roll anything too big.

```asm
randc:  jsr rng
        and #$3F            ; 0..63
        cmp #40
        bcs randc           ; >=40 -> throw it away, roll again
        rts
```

### Collision is just a comparison

Two 1-pixel objects collide when their coordinates match. After moving the player we check:

```asm
after:  lda hx
        cmp fx
        bne nocatch
        lda hy
        cmp fy
        bne nocatch
        inc score           ; hx==fx AND hy==fy -> caught!
        jsr drawhud
        jsr newfood
nocatch:
```

`newfood` rolls a fresh `fx,fy` and retries if it lands on the player, so the target never
appears under you.

### Drawing the score

Text cells want the **high bit set** for normal (bright) video, so we `ora #$80` on letters
and `ora #$B0` on digits (`$B0` is `'0'` with the high bit already on). To print the number we
split it into tens and ones by subtracting 10 until we can't:

```asm
dh3:    cmp #10
        bcc dh4
        sec
        sbc #10
        inx                 ; count the tens
        bra dh3
dh4:    ...                 ; A = ones digit, X = tens digit
```

We write the label and digits straight into text-row 20 at `$0650`.

## 3. Run it

Open <https://ebadger.github.io/3ric/?src=programs/tut6_catch.s>. Steer the white block with
**W/A/S/D** onto the yellow food; each catch bumps **SCORE** and drops new food. **Q** quits.

The RNG is seeded to a fixed value, so the *first* food always lands at (2, 1) — which makes
the game fully testable. We drive the player left 18 and up 19 to reach it and confirm the
score ticks to 1:

```sh
node codegen/tools/verify_keys.cjs codegen/programs/tut6_catch.s 0x0800 \
    "AAAAAAAAAAAAAAAAAAWWWWWWWWWWWWWWWWWWW" 0x06=0x02 0x07=0x01 0x0A=0x01
```

The harness even shows `SCORE: 01` in the decoded text window — the HUD really is being drawn.

## 4. What just happened

You turned a mover into a *game*: a random goal, collision, and a score the player can see.
The LFSR is a workhorse you'll reuse for enemy placement, item drops, and screen effects. And
mixed mode — graphics plus a text HUD — is exactly how countless arcade and 8-bit games laid
out their screens.

## 5. Make it yours

1. **Countdown.** Add a second number to the HUD and decrement it every N moves; end the game
   at zero (jump to `quit`).
2. **Rotten food.** Occasionally (say when `rng` is even) make the food red and *subtract* a
   point if caught.
3. **Two foods.** Track `fx2,fy2` and draw both; catching either scores.
4. **Better randomness.** Re-seed `seed` from a fast-changing source — for example, read the
   keyboard-strobe or a counter that increments every loop — so the first food differs each run.

## Next

You now have every building block a small game needs: modes, drawing, input, motion,
collision, randomness, and score. In **[Lesson 7 — Space Invaders](07-invaders.md)** we put
them all together into the capstone: a formation of aliens, a cannon, a bullet, and win/lose
states.

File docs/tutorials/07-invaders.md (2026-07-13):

# Lesson 7 — Space Invaders (capstone)

> **You'll build:** a playable lo-res Space Invaders — a marching fleet, a cannon, a bullet,
> collision, score, and win/lose screens.
> **New ideas:** a game *state machine*; storing a fleet as data (origin + per-alien flags);
> edge-detect-and-reverse movement; tying every earlier lesson together.
> **Program:** [`codegen/programs/tut7_invaders.s`](../../codegen/programs/tut7_invaders.s) ·
> **▶ Run it:** <https://ebadger.github.io/3ric/?src=programs/tut7_invaders.s>

---

## 1. The idea

This is the whole series in one program. Nothing here is *new* except how the pieces fit
together:

| From | We reuse |
| --- | --- |
| Lesson 3 | non-blocking keyboard input |
| Lesson 4 | `plot` + lo-res color |
| Lesson 5 | the game loop and per-frame motion |
| Lesson 6 | mixed mode, a text HUD, collision-by-compare |

The design work is **data layout** and a tiny **state machine** (playing → win/lose →
restart). Get those right and the code almost writes itself.

## 2. The design

### The fleet is data, not code

We never hard-code where the aliens are. We store a **formation origin** and let math place
each alien:

```asm
fleetx  = $0B   ; X of the left column
fleety  = $0C   ; Y of the top row
alive:  .byte 1,1,1,1,1   ; 5 columns x 3 rows, row-major
        .byte 1,1,1,1,1
        .byte 1,1,1,1,1
```

Alien `(row, col)` lives at `ax = fleetx + col*3`, `ay = fleety + row*3`, and it's on screen
only if `alive[row*5 + col]` is non-zero. To move the *entire* fleet we change **two bytes**
(`fleetx`, `fleety`); to kill one alien we clear **one byte**. That's the power of separating
data from drawing — three little helpers turn `(row,col)` into an index or a position:

```asm
alienidx: lda arow          ; index = arow*5 + acol
        asl a
        asl a
        clc
        adc arow
        clc
        adc acol
        tax
        lda alive,x
        rts
```

### Marching: step, and reverse at the edge

Every `FLEETPD` frames the fleet steps sideways. When the formation reaches a wall it drops
one row and reverses — the signature Space Invaders move:

```asm
        lda fleetx          ; heading right
        clc
        adc #13             ; right edge of the formation
        cmp #38
        bcc mf_right        ; room left -> just step right
        lda #$FF            ; at the wall -> reverse...
        sta fleetdir
        inc fleety          ; ...and drop a row
```

`FLEETPD` is the difficulty knob: smaller = faster fleet. Classic games shrink it as aliens
die; try that in the exercises.

### Firing and collision

The cannon fires **one** bullet at a time. `hitcheck` walks the fleet each frame. Aliens are
two pixels wide, so it matches the bullet against `ax` *or* `ax+1`. And because the bullet
climbs **two rows per frame**, it can jump clean over a row — so we accept `by` *or* `by+1`
too. Without that, an alien on an odd row (which is exactly what happens after the fleet
drops) could never be hit: the bullet's row stays even and steps right past it.

```asm
        jsr alienx          ; A = ax
        sta ptmp
        cmp bx
        beq hc_xok
        clc
        adc #1              ; ax+1  (aliens are 2 px wide)
        cmp bx
        bne hc_next
hc_xok: jsr alieny          ; A = ay
        cmp by              ; the bullet's row...
        beq hc_hit
        sec
        sbc #1              ; ...or the row it skipped (ay-1 == by)
        cmp by
        bne hc_next
hc_hit: ; hit! clear alive[i], stop the bullet, score++
```

### The state machine

A single byte `state` (0 = playing, 1 = win, 2 = lose) drives everything. The loop checks two
end conditions each frame:

```asm
        lda count           ; no aliens left -> win
        bne notwin
        jmp win
notwin: lda fleety          ; fleet reached the cannon -> lose
        clc
        adc #6
        cmp #38
        bcc draw
        jmp lose
```

`win` and `lose` paint a message into the HUD and wait for **R** (jump back to `restart`,
which re-fills `alive` and resets the counters) or **Q**. `restart` is just the setup code with
a label on it — reusing it for "new game" costs nothing.

## 3. Run it

Open <https://ebadger.github.io/3ric/?src=programs/tut7_invaders.s>. Move with **A/D**, fire
with **SPACE**, and clear the fleet before it lands. After a win or loss, press **R** to play
again or **Q** to quit.

Two headless checks pin down the core mechanics. First, the fresh-game state:

```sh
node codegen/tools/verify_keys.cjs codegen/programs/tut7_invaders.s 0x0800 "" \
    0x0E=0x0F 0x0F=0x00 0x07=0x00 0x06=0x14
```

`count == 15`, `score == 0`, `state == 0`, cannon centered. Then an aligned shot — slide the
cannon under the right column and fire:

```sh
node codegen/tools/verify_keys.cjs codegen/programs/tut7_invaders.s 0x0800 "AA ZZZZZZZZ" \
    0x06=0x12 0x0E=0x0E 0x0F=0x01 0x0A=0x00
```

The bullet climbs, an alien dies (`count` 15 → 14), `score` ticks to 1, and the bullet is
consumed (`bactive == 0`). The HUD even shows `SCORE: 01`.

## 4. What just happened

You shipped a game. More importantly, you used the pattern every game is built on: **state
lives in a few bytes, the loop reads input → updates state → draws, and "objects" are just
data your routines interpret.** A 15-alien fleet took two origin bytes and a 15-byte array.
Scale that idea up — more arrays, more state — and you have any game you can imagine.

## 5. Make it yours

1. **Ramp the difficulty.** Lower `FLEETPD` as `count` drops so the fleet speeds up — the
   trademark Space Invaders panic.
2. **Aliens shoot back.** Give the fleet its own bullet: pick a random live column (Lesson 6's
   RNG), drop a bullet from its bottom alien, and check it against the cannon.
3. **Lives and levels.** Add a `lives` byte to the HUD; on a win, `jmp restart` but keep the
   score to make a level 2.
4. **Bunkers.** Draw a few grey blocks above the cannon and let both bullets chip them away
   (clear a pixel on contact).

## Next

You've built a complete game in lo-res. In **[Lesson 8 — Hi-res and where to go
next](08-hires.md)** we peek at the 3ric's high-resolution mode, then map the shipped games
(`swarm`, `rocks`, `jungle`) so you can keep learning from real, finished code.

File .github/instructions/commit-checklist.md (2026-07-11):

# Commit Checklist (Quick)

Layers consistent? | Specs updated? | Tests pass? | No secrets? | Cross-layer commit atomic?

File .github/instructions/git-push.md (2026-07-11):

# Git Push — Pre-Push Verification

> **Mechanical enforcement:** a repo-tracked `pre-push` hook (`.githooks/pre-push`)
> blocks pushes to a branch whose PR is MERGED/CLOSED. Activate it once per clone with
> `scripts/dev/install-hooks.sh`. The checks below are still your responsibility — the
> hook is a backstop, not a substitute (it fails open when `gh` is unavailable, and can
> be bypassed with `SKIP_PR_GUARD=1`).

⚠️ You are about to push commits. Before proceeding, you MUST verify:

## Mandatory Checks

1. **PR state** — Run `gh pr view <N> --json state` for the associated PR.
   - If **OPEN**: proceed with push.
   - If **MERGED**: STOP. Do not push. Create a new branch from `origin/main`, cherry-pick your commits, and open a fresh PR.
   - If **CLOSED**: STOP. Ask ebadger how to proceed.
   - If **no PR exists yet**: this is a first push — proceed, then create a PR.

2. **Upstream synced** — Run `git fetch origin main` before pushing to confirm you're not behind.

3. **Branch matches PR** — Confirm you're pushing to the same branch the open PR tracks. Do not push to a branch whose PR was already merged.

## Why This Matters

Pushing to a merged branch is a no-op — the commits go nowhere useful. They orphan your work and require manual cleanup (cherry-picks, new PRs, confusion). This is a recurring footgun (see LEARNINGS.md §6).

## If You Already Pushed to a Merged Branch

1. `git fetch origin main`
2. `git reset --hard origin/main`
3. `git cherry-pick <your orphaned commit SHAs>`
4. Push to a new branch and open a fresh PR.

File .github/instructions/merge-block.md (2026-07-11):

# Merge Block

**You must NEVER run `gh pr merge` except for the `docs/learnings/` markdown auto-merge.**

## Rule (LEARNINGS.md §5)

All PRs require ebadger's approval to merge. Your job is to:
1. Create the PR
2. Provide the link to ebadger
3. Stop and wait

## Only Exception

`docs/learnings/` markdown-only changes may be self-merged per the auto-merge protocol:
- Branch contains ONLY `.md` files under `docs/learnings/sessions/`, `weekly/`, `monthly/`, or `archive/`
- No code, spec, config, or other path changes in the same commit
- PR is created with base: main
- Merged via `gh pr merge <N> --merge --delete-branch`

(`docs/learnings/README.md` and `docs/LEARNINGS.md` promotions are NOT auto-mergeable.)

If the command you're about to run does NOT match this exception, **cancel it immediately**.

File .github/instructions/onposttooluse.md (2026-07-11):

# Spec Edit — Cross-Layer Verification

You just edited a specification or source file in one of the system layers. Before proceeding, verify cross-layer consistency.

## Layer Checklist

Ask yourself for each (rename these to your project's actual layers):

- [ ] **Data store** (`specs/DATABASE.md`, schema/migrations) — Are schema, columns, constraints, or indexes affected?
- [ ] **API / Service** (`specs/API.md`, server endpoints) — Are endpoints, request/response shapes, or validation rules affected?
- [ ] **Client / UI** (`specs/WEB-CLIENT.md`, frontend) — Are pages, components, or interactions affected?
- [ ] **SYSTEM.md** (`specs/SYSTEM.md`) — Does the umbrella overview need updating?

## Rules

- If a change touches one layer, explicitly verify whether the others need updates before committing.
- Don't treat spec documents as independent — they are a connected system where changes propagate.
- Update implementation status in the relevant spec after implementing a feature.

## Common Mistakes

- Adding a data-store column but forgetting to expose it in the API response shape
- Adding an API endpoint but forgetting to update the client to call it
- Updating a spec but not updating its implementation-status section

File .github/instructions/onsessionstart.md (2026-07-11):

# Session Start Instructions

You are starting a session on **3ric** — a from-scratch Apple-II-class 65C02 computer built and documented as a learn-by-building project

## Mandatory Reading (start of every session)

- `docs/LEARNINGS.md` — **canonical** workflow rules (§1–6) + the Tier-1 lessons digest
  (always-loaded, ~2,500-token cap). Read this first; it is the source of truth for the
  rules summarized below. Full incident narratives live in `docs/learnings/` — on demand.
- `docs/MISSION.md` — purpose and operating principles.
- `specs/SYSTEM.md` — umbrella overview of the system + links to every sub-spec.
- `status/SYSTEM-STATUS.md` — runtime env, credentials, scripts, verification commands.

**Read sub-specs lazily.** Load a sub-spec only for the layer you're about to touch — not
all of them up front. Deep dives (runbooks, changelog) are read on demand, not at start-up.

## Environment Setup (idempotent — safe every session, do before pushing)

Ensure this repo's git hooks are active. Run with the **same git that performs your pushes**:

```
git config core.hooksPath .githooks
```

This activates `.githooks/pre-push`, which mechanically (1) caps `docs/LEARNINGS.md`,
(2) runs the optional project test gate, and (3) blocks pushes to a branch whose PR is
already MERGED/CLOSED — the backstop for Core Rules 5 & 6. See `.githooks/README.md`.

## Core Rules — canonical in `docs/LEARNINGS.md` §1–6 (don't re-derive)

1. **Never self-merge.** Open a PR and give ebadger the link. (§5)
2. **Specs first, code second.** (§3)
3. **Trace all layers** — Data store → API/Service → Client — for any stored-data feature. (§1–2)
4. **Commit atomically** across layers/specs. (§4)
5. **Check PR state before pushing** (`gh pr view <number> --json state`; if MERGED, branch
   fresh off `origin/main`). (§6, also enforced by the `.githooks/pre-push` hook.)
6. **After any git pull/reset**, re-read the instruction files that may have changed.
7. **When in doubt about permissions, ask** rather than assume.

## Data Flow Thinking

When adding or modifying a feature, trace the full path:

```
User action (UI) → API request → Server logic → Data write
Data read → API response → UI render
```

Every link in this chain must be specified.

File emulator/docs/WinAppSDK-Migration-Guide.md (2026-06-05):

# WinAppSDK Migration Guide: Lessons Learned

## Overview

This document captures hard-won knowledge from migrating a C++/WinRT WinUI 3 desktop application from Windows App SDK 1.3 to 1.6. It focuses on false assumptions, non-obvious requirements, and solutions that would have saved significant debugging time if known upfront.

The guidance here is generally applicable to any C++/WinRT WinUI 3 packaged desktop app using NuGet-based SDK integration.

---

## Part 1: Migration Pitfalls and Solutions

### 1. WebView2 Is No Longer Bundled in the SDK Package

**False assumption:** All WinRT types referenced by WinUI 3 controls are included in the WindowsAppSDK NuGet package, just as they were in 1.3.

**Reality:** Starting with WinAppSDK 1.6, `Microsoft.Web.WebView2.Core` types are in a separate NuGet package (`Microsoft.Web.WebView2`). The SDK's WinUI headers (`Microsoft.UI.Xaml.Controls.h`) include `winrt/Microsoft.Web.WebView2.Core.h`, which means CppWinRT must be able to resolve these types even if your app does not directly use WebView2.

**Symptom:** CppWinRT fails during projection generation with errors about unresolved `Microsoft.Web.WebView2.Core.CoreWebView2` types.

**Solution:** Install the `Microsoft.Web.WebView2` NuGet package and ensure its winmd is available to CppWinRT. The winmd lives at `packages\Microsoft.Web.WebView2.{version}\lib\Microsoft.Web.WebView2.Core.winmd`.

---

### 2. CppWinRT Version Mismatch Between NuGet and Windows SDK

**False assumption:** The CppWinRT tool version in the NuGet package and the `winrt/base.h` shipped with the Windows SDK are compatible.

**Reality:** The Windows SDK ships its own `cppwinrt\winrt\base.h` (e.g., version 2.0.250303.5 in SDK 10.0.26100.0), while the `Microsoft.Windows.CppWinRT` NuGet package may ship an older tool (e.g., 2.0.230524.4). Generated projection headers embed a version check via `#pragma detect_mismatch` and `static_assert`. If you include the SDK's cppwinrt path in your include directories, the newer `base.h` conflicts with headers generated by the older tool.

**Symptom:** `static assertion failed: 'Mismatched C++/WinRT headers'` during C++ compilation.

**Solutions (pick one):**
- **Upgrade the CppWinRT NuGet** to match the SDK version (e.g., 2.0.250303.5+).
- **Do not add the SDK's cppwinrt path** to `AdditionalIncludeDirectories`. Instead, ensure the CppWinRT NuGet tool generates its own `base.h` into the Generated Files directory. This happens automatically when CppWinRT processes platform inputs (winmds passed via `-in`).
- **Make WebView2 a platform input, not just a reference.** If WebView2 is passed as `-ref` only, CppWinRT may not generate `base.h` itself. Adding it via `CppWinRTPlatformWinMDReferences` (which feeds into `-in`) forces CppWinRT to generate a complete projection including `base.h`.

**Key insight:** The `-in` flag tells CppWinRT to generate projection headers for those winmds, including `base.h`. The `-ref` flag only makes types available for resolution without generating headers. The distinction matters for triggering `base.h` generation.

---

### 3. WebView2 Targets Import

**False assumption:** Installing the WebView2 NuGet and referencing its winmd is sufficient.

**Reality:** The WebView2 NuGet package includes a targets file (`build\native\Microsoft.Web.WebView2.targets`) that handles generating C++/WinRT projection headers via its own `wv2winrt` tool. If you do not import this targets file, the WebView2 headers may not be generated.

**Solution:** Import the WebView2 targets in your vcxproj:
```xml
<Import Project="..\packages\Microsoft.Web.WebView2.{version}\build\native\Microsoft.Web.WebView2.targets"
        Condition="Exists('...\Microsoft.Web.WebView2.targets')" />
```

---

### 4. MSIX Package Manifest: EntryPoint Must Be "Windows.FullTrustApplication"

**False assumption:** The `EntryPoint` attribute in the manifest's `<Application>` element should be the executable name (e.g., `MyApp.exe`).

**Reality:** For WinUI 3 **desktop** (Win32) packaged apps, `EntryPoint` must be `Windows.FullTrustApplication`. Setting it to the exe name causes Windows to treat the app as a UWP CoreApplication, which initializes the wrong threading model (ASTA vs. STA).

**Symptom:** `0x8001010E` (RPC_E_WRONG_THREAD) thrown from `twinapi.appcore.dll` inside `Application::Start`. The error originates in `CoreApplicationFactory` -- a UWP code path that should never execute for desktop apps.

**Solution:**
```xml
<Application Id="App"
  Executable="MyApp.exe"
  EntryPoint="Windows.FullTrustApplication">
```

---

### 5. MSIX Package Must Declare Framework Dependencies

**False assumption:** Installing the Windows App Runtime framework package on the system is sufficient; the app will find it automatically.

**Reality:** The MSIX manifest must explicitly declare `<PackageDependency>` elements for the WinAppSDK framework and VCLibs. Without these, the framework packages are not in the app's package graph and WinRT activation fails.

**Symptom:** `0x80040154` (REGDB_E_CLASSNOTREG) -- the class `Microsoft.UI.Xaml.Application` cannot be created because the framework DLLs are not loaded.

**Solution:**
```xml
<Dependencies>
  <TargetDeviceFamily Name="Windows.Desktop" MinVersion="10.0.17763.0" MaxVersionTested="10.0.26100.0" />
  <PackageDependency Name="Microsoft.WindowsAppRuntime.1.6"
    MinVersion="6000.519.329.0"
    Publisher="CN=Microsoft Corporation, O=Microsoft Corporation, L=Redmond, S=Washington, C=US" />
  <PackageDependency Name="Microsoft.VCLibs.140.00.UWPDesktop"
    MinVersion="14.0.33728.0"
    Publisher="CN=Microsoft Corporation, O=Microsoft Corporation, L=Redmond, S=Washington, C=US" />
</Dependencies>
```

---

### 6. MSIX Package Must Specify ProcessorArchitecture

**False assumption:** Omitting `ProcessorArchitecture` from the `<Identity>` element defaults to the correct architecture.

**Reality:** Omitting it produces a "neutral" package that cannot resolve architecture-specific framework dependencies (the WinAppSDK framework is x64/arm64-specific).

**Symptom:** Same as above (0x80040154) -- framework packages are not resolved because a neutral package cannot depend on architecture-specific frameworks.

**Solution:**
```xml
<Identity Name="..." Publisher="..." Version="..." ProcessorArchitecture="x64" />
```

---

### 7. MSIX Package Needs resources.pri and Compiled XAML (XBF)

**False assumption:** A bare exe with the AppxManifest is enough for a packaged WinUI 3 app to launch.

**Reality:** WinUI 3 requires:
- **Compiled XAML files (.xbf)** -- the binary representation of your XAML pages, generated by the XAML compiler during build.
- **resources.pri** -- a Package Resource Index file that maps resource names (including XAML files) to their physical locations in the package.

Without these, the XAML framework cannot find or load your UI definitions.

**Solution:** Include all `.xbf` files from the build output in the package (maintaining relative paths, e.g., `Themes\Generic.xbf`). Generate `resources.pri` using `makepri.exe`:
```
makepri.exe createconfig /cf priconfig.xml /dq "en-US" /o
makepri.exe new /pr <layout_dir> /cf priconfig.xml /of resources.pri /o
```

---

### 8. The "x-generate" Resource Language Placeholder

**False assumption:** The manifest from the project template is deployment-ready.

**Reality:** Visual Studio project templates use `<Resource Language="x-generate"/>` as a placeholder that the build system replaces with actual languages. If you package manually without the build system, this placeholder remains and causes deployment failure.

**Symptom:** `0x80070057` -- "the specified resource language 'x-generate' is not a valid language."

**Solution:** Replace with an actual BCP-47 language tag:
```xml
<Resource Language="en-us"/>
```

---

### 9. Package Install Location Is Read-Only

**False assumption:** Files in the MSIX package can be opened for read-write access at runtime.

**Reality:** The package install directory (`C:\Program Files\WindowsApps\...`) is read-only for the app. Any file that needs to be modified at runtime (save files, mutable configuration, disk images) must be copied to a writable location first.

**Symptom:** `CreateFile` with `GENERIC_WRITE` fails with access denied. Memory-mapped files with `PAGE_READWRITE` fail silently (handles remain `INVALID_HANDLE_VALUE`).

**Solution:** On first launch, copy mutable files from the package to the app's local data folder:
```cpp
auto localFolder = winrt::Windows::Storage::ApplicationData::Current().LocalFolder().Path();
// Copy from package install location to localFolder, then open from there
```

---

### 10. InProcessServer Class Registrations

**False assumption:** A packaged WinUI 3 desktop app does not need activatable class registrations in its manifest because it uses C++ direct instantiation.

**Reality:** While the main `winrt::make<App>()` call uses C++ factories directly, the XAML framework may internally attempt WinRT activation for your app's types (e.g., for XAML type info providers, custom controls). Adding `<InProcessServer>` registrations ensures all activation paths work.

**Solution:**
```xml
<Extensions>
  <Extension Category="windows.activatableClass.inProcessServer">
    <InProcessServer>
      <Path>MyApp.exe</Path>
      <ActivatableClass ActivatableClassId="MyApp.App" ThreadingModel="both" />
      <ActivatableClass ActivatableClassId="MyApp.MainWindow" ThreadingModel="both" />
      <ActivatableClass ActivatableClassId="MyApp.XamlMetaDataProvider" ThreadingModel="both" />
    </InProcessServer>
  </Extension>
</Extensions>
```

---

## Part 2: Recommended Improvements

The following are improvements to the Windows App SDK, MSIX packaging system, and Windows platform that would have significantly reduced the friction encountered during this migration.

### Windows App SDK

1. **Version coupling should be documented prominently.** The relationship between CppWinRT NuGet version, Windows SDK cppwinrt version, and generated header compatibility is not documented anywhere obvious. A compatibility matrix or build-time warning would prevent hours of debugging static assertion failures.

2. **WebView2 dependency should be automatic.** When a project takes a dependency on WinAppSDK 1.6+, the build system should automatically bring in the WebView2 NuGet (or at minimum, produce a clear error explaining the missing dependency). Having the SDK's own headers fail to compile because of a missing transitive dependency is a poor developer experience.

3. **CppWinRT `-in` vs `-ref` semantics need documentation.** The distinction between these flags and their effect on `base.h` generation is critical but poorly documented. Most developers encounter it only through cryptic compilation failures.

4. **The CppWinRT NuGet should match the SDK by default.** When the Windows SDK is updated, the CppWinRT NuGet package version referenced by project templates should be updated to match. Alternatively, the version mismatch check should produce a clear diagnostic message pointing to the solution.

### MSIX Packaging

5. **`makeappx.exe` should validate manifest semantics.** Currently, `makeappx.exe` happily creates packages with invalid resource languages (`x-generate`), missing framework dependencies, and incorrect entry points. A validation pass with actionable error messages would catch these before deployment.

6. **Provide a "package from build output" tool.** The gap between "I have a built exe" and "I have a deployable MSIX" requires deep knowledge of manifest authoring, PRI generation, XBF placement, and framework dependency declarations. A single tool that takes a build output directory and produces a valid MSIX (inferring dependencies from the binary's imports) would be transformative.

7. **Error messages during deployment should be actionable.** Errors like `0x80040154` during app launch give no indication that the cause is a missing `<PackageDependency>` in the manifest. The deployment system knows which class failed to activate -- it should suggest checking framework dependencies.

8. **The relationship between EntryPoint values and app models should be documented at the error site.** Getting `RPC_E_WRONG_THREAD` because `EntryPoint` was set to the exe name instead of `Windows.FullTrustApplication` is nearly impossible to diagnose without deep platform knowledge. The error should say: "Desktop app detected using CoreApplication activation path. Did you mean EntryPoint='Windows.FullTrustApplication'?"

### Windows Platform

9. **Package install location write-access policy should produce clear diagnostics.** When `CreateFile` fails in a package directory, the error is a generic access-denied. A platform diagnostic (Event Log entry, or debugger output message) explaining "Write denied: package install directory is read-only; use ApplicationData.LocalFolder for mutable files" would save significant debugging time.

10. **Framework package resolution failures need better diagnostics.** When a framework dependency cannot be resolved (wrong architecture, version mismatch, etc.), the system should log exactly which dependency failed and why, rather than producing a generic class-not-registered error at activation time.

---

## Summary Checklist for WinAppSDK 1.3 to 1.6 Migration

- [ ] Install `Microsoft.Web.WebView2` NuGet package (no longer bundled)
- [ ] Ensure CppWinRT NuGet version matches your Windows SDK's cppwinrt version, OR avoid adding the SDK cppwinrt path to includes
- [ ] Import WebView2 native targets in your vcxproj
- [ ] Update `packages.config` with new package versions
- [ ] Update all WinAppSDK winmd reference paths (version number in path changes)
- [ ] Verify MSIX manifest has `EntryPoint="Windows.FullTrustApplication"`
- [ ] Verify MSIX manifest has `ProcessorArchitecture` set in `<Identity>`
- [ ] Verify MSIX manifest has `<PackageDependency>` for WindowsAppRuntime and VCLibs
- [ ] Replace `<Resource Language="x-generate"/>` with actual language
- [ ] Include `.xbf` files and `resources.pri` in the package
- [ ] Move any writable data files to `ApplicationData.LocalFolder` at runtime
- [ ] Register app's activatable classes via `<InProcessServer>` in manifest extensions

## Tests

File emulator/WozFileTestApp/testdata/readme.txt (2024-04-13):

WOZ TEST IMAGES
Compiled by John K. Morris
jmorris@evolutioninteractive.com
v1.4 June 16, 2021

//\\//\\//\\//\\//\\//\\//\\//\\//\\//\\//\\//\\//\\//\\//\\//\\//\\//\\//\\//\\

This is a set of disk images intended to assist Apple ][ emulator developers in testing their implementations of floppy drives and drive controller cards.

The WOZ Disk Image Reference can be found at:
https://applesaucefdc.com/woz/reference2/

All of the images here have been tested in multiple emulators and are all verified as good images. You can trust them. If they don't work for some reason, then it is something about your implementation.

This archive contains WOZ 1.0, 2.0, and 2.1 images. The WOZ 2.x is the current specification, but I am also providing WOZ 1.0 to allow you to include backward compatibility. The files in the WOZ 2.1 folder are primarily for testing flux images.

//\\//\\//\\//\\//\\//\\//\\//\\//\\//\\//\\//\\//\\//\\//\\//\\//\\//\\//\\//\\

WHERE TO BEGIN
--------------

The "DOS 3.3 System Master" is a good place to start. Nicely organized nibbles and not doing any kind of gymnastics to the floppy soft switches. "The Apple at Play" is also a good choice for this. If you are supporting booting 13-sector disks, you can also give "DOS 3.2 System Master" a try.

NEXT CHOICES
------------

After you have System Master disks booting, you can move on to some slightly more complex disk images that are copy protected. These are all just basic tests, and not doing anything too crazy. "Bouncing Kamungas", "Commando", "Planetfall", "Rescue Raiders", "Sammy Lightfoot" and "Stargate"

These titles are your reward for getting this far in your woz implementation. Have some fun with them!

CROSS TRACK SYNC
----------------

The "Cross-Track Syncronization" of the woz reference covered this protection method and discussed the proper way to implement it. If you did this correctly, the disks "Blazing Paddles" and "Take 1" should be working properly. They both do a crazy cross track check when they boot up. If you get to the main menu of these, then consider yourself a winner.

More good tests for this is "Hard Hat Mack" and "Marble Madness". These have an extra-wide track on it that is actually 2 tracks wide. Being able to start playing a game means that you passed the checks.

HALF TRACKS
-----------

In order to test that you are address half tracks correctly, use "The Bilestoad". The first third of the disk is on full tracks and the rest on half tracks. If you can start a game, you have passed the check.

EVEN MORE BIT FIDDLING
----------------------

We are now getting to a few titles that do a fair amount of trickery with the soft switches, "Dino Eggs", "Crisis Mountain" and "Miner 2049er II". If you can start the games, then you have passed the checks.

WHEN BITS AREN'T REALLY BITS
----------------------------

For testing the MC3470 generation of fake bits, you can turn to "The Print Shop Companion". If you have control at the main menu, then you are passing this test.

WHAT IS THE LIFESPAN OF THE DATA LATCH?
---------------------------------------

When a program reads data from the data latch, the implementation should not be clearing the latch. "First math Adventures - Understanding Word Problems" is a good test of this. If you can get to the title screen, then you are good to go.

READING OFFSET DATA STREAMS
---------------------------

Some programs will reset the data latch mid way through a nibble (via LDA $C08D,x). This will cause the incoming data stream to read offset from the normal nibble starts. These streams will usually incorporate timing bits between nibbles that will not become data bits instead. Some good test candidates for this are "Wings of Fury" and "Stickybear Town Builder". If you can get to the title screens, then you have passed.

OPTIMAL BIT TIMING OF WOZ 2.0
-----------------------------

The official "rule" of Apple II floppy encoding is that the timing between bits is 4 microseconds. So, since there was a rule, people needed to break that rule. They would slow down or speed up the drives before writing them just to mess with bit copiers that would write data back out at 4. A good example of this is "Border Zone". The WOZ 2.0 file has an Optimal Bit Timing of 3.5 microseconds. It has a very timing dependent disk reader that will tend to lose sync with the disk if the bits are coming in at 4 microseconds, this causes some horrible delays when playing the game. A good test is to boot up the first disk, after loading for a while, it will ask for the next disk. Start a stopwatch when you insert the disk and press return. It will then take you to a menu where you can select which scenario you want to play from a list of 3. Press "1" to pick the first one "Train". Then it will scroll through a bunch of text that you need to keep hitting return when you see the "MORE" label. Finally you will be presented with the command prompt ">", this is when you check your stopwatch. Using a 4 microsecond bit timing, this little test can run almost a minute and a half. If you use the 3.5 microsecond timing as indicated in the WOZ file, then the test tends to take around 17 seconds.

FLUX TRACKS OF WOZ 2.1
----------------------

The WOZ 2.1 specification introduced the FLUX chunk with the ability to have an even lower level of accuracy than bits (at the expense of size). There is a ProDOS image in there that has every other track in flux format (0, 2, 4, 6, etc). If you can successfully boot this disk, then you know that you handling of flux-based tracks is working.

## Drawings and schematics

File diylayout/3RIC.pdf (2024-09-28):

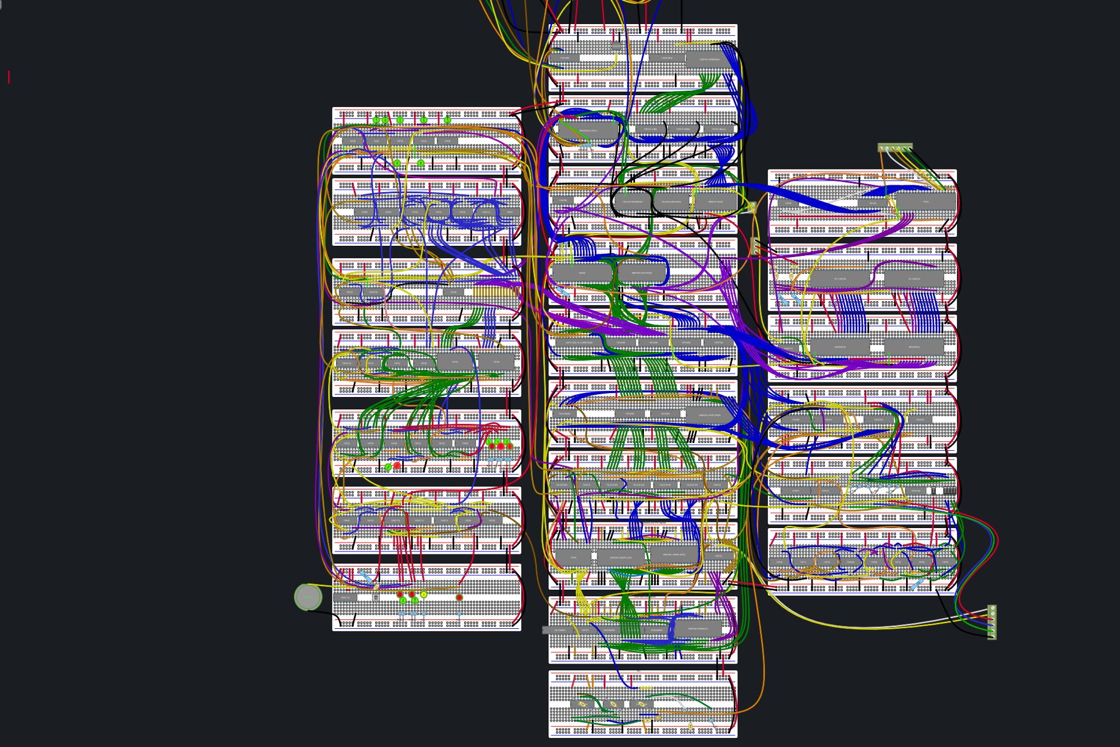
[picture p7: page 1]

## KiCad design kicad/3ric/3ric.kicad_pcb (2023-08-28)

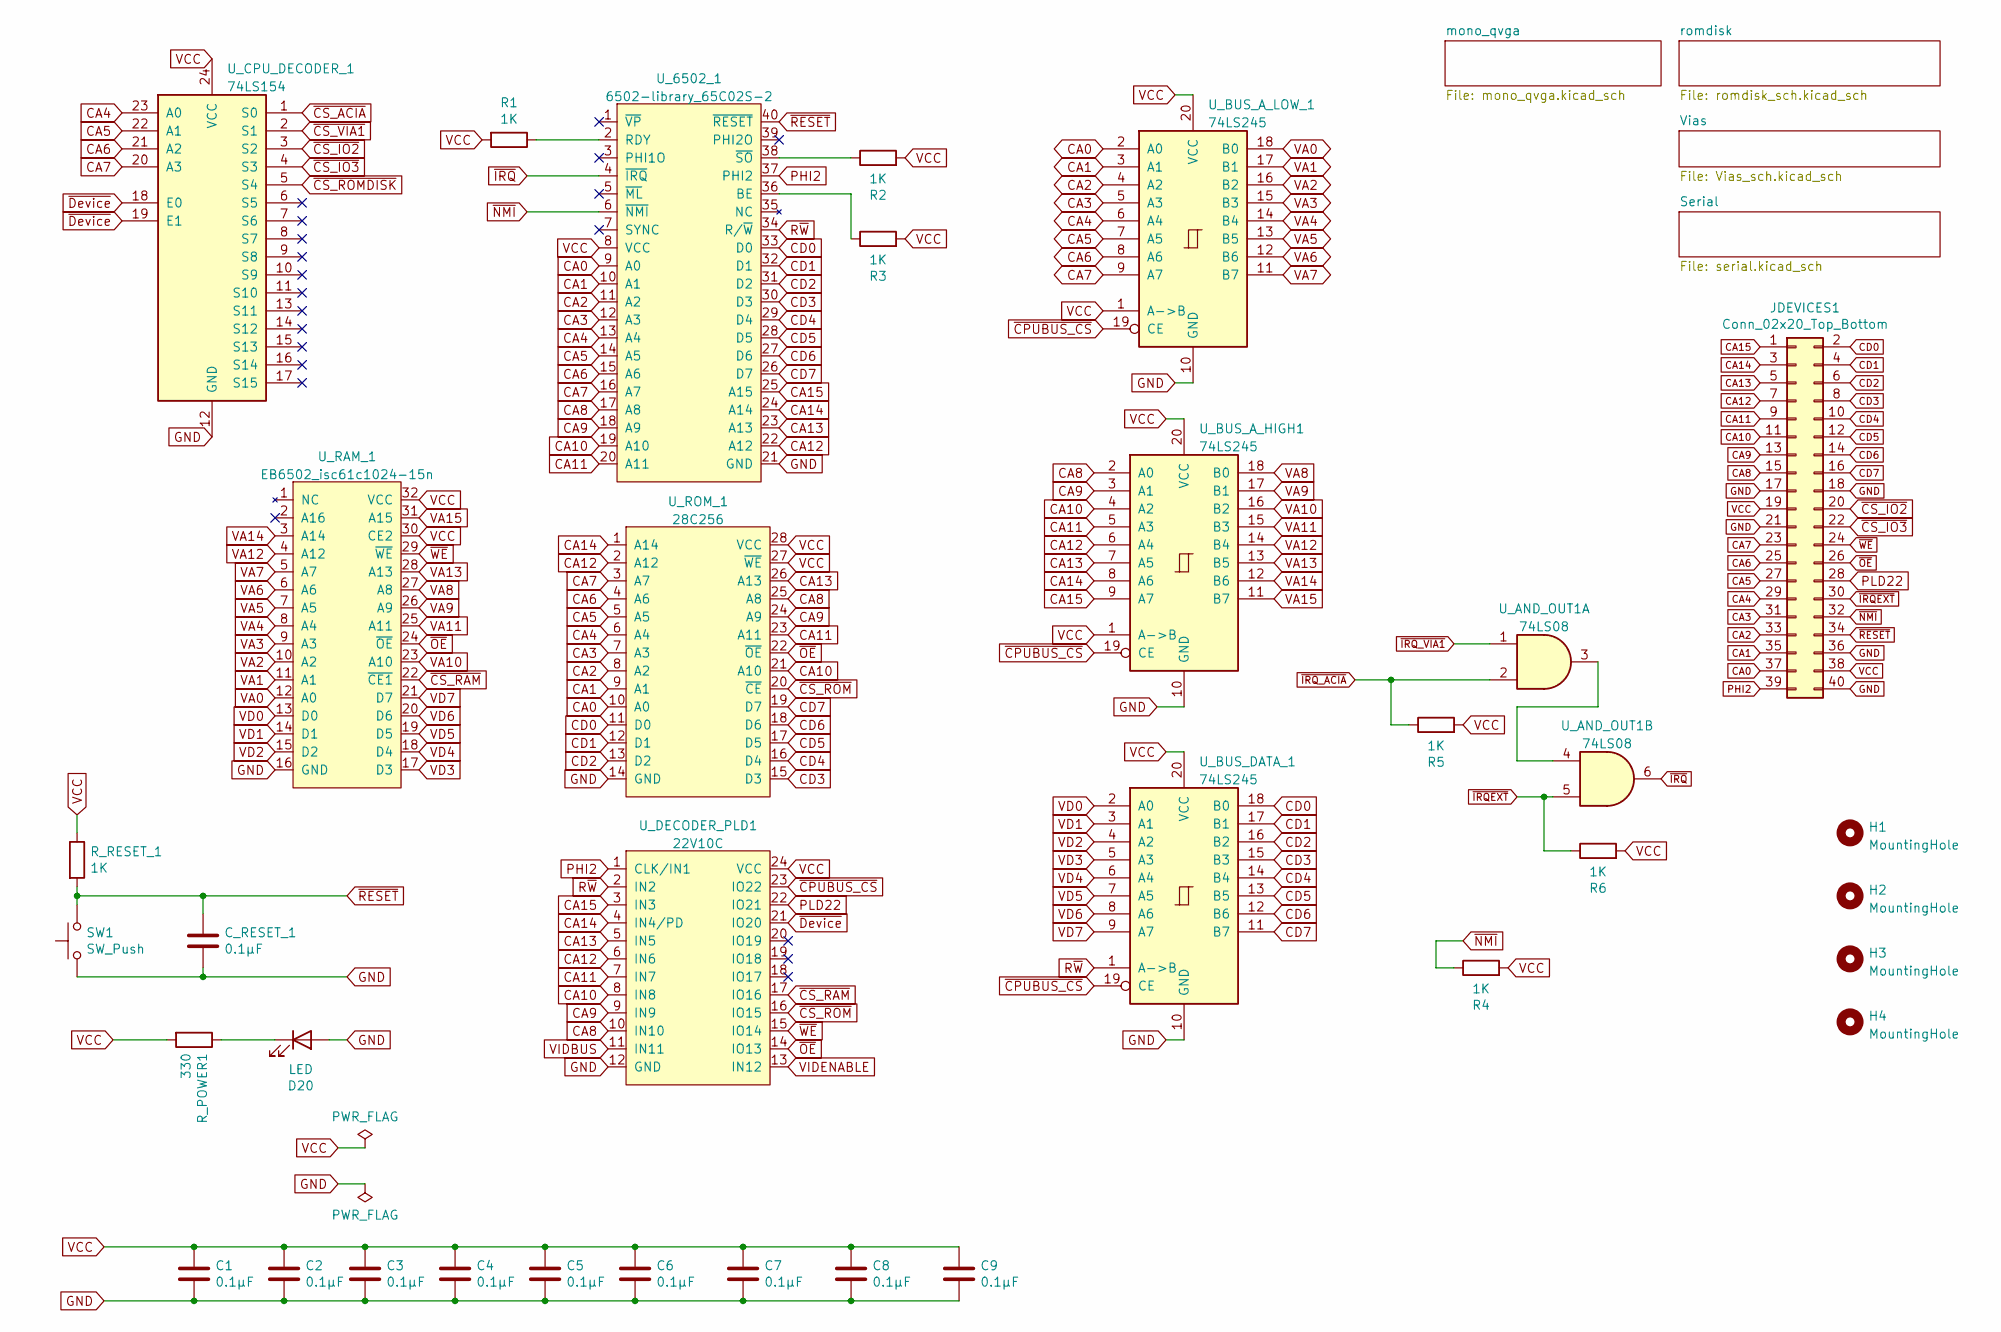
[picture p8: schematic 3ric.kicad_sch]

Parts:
C1, C2, C3, C4, C5, C6, C7, C8, C9: 0.1µF; C_Axial_L3.8mm_D2.6mm_P7.50mm_Horizontal
C_RESET_1: 0.1µF; C_Axial_L3.8mm_D2.6mm_P7.50mm_Horizontal
D20: LED; LED_D5.0mm
H1, H2, H3, H4: MountingHole; MountingHole_3.2mm_M3
JDEVICES1: Conn_02x20_Top_Bottom; IDC-Header_2x20_P2.54mm_Vertical
R1, R2, R3, R4, R5, R6: 1K; R_Axial_DIN0207_L6.3mm_D2.5mm_P7.62mm_Horizontal
R_POWER1: 330; R_Axial_DIN0207_L6.3mm_D2.5mm_P7.62mm_Horizontal
R_RESET_1: 1K; R_Axial_DIN0207_L6.3mm_D2.5mm_P7.62mm_Horizontal
SW1: SW_Push; SW_PUSH_6mm
U_6502_1: 6502-library_65C02S-2; DIP-40_W15.24mm_Socket
U_AND_OUT1: 74LS08; DIP-14_W7.62mm_Socket
U_BUS_A_HIGH1: 74LS245; DIP-20_W7.62mm_Socket
U_BUS_A_LOW_1: 74LS245; DIP-20_W7.62mm_Socket
U_BUS_DATA_1: 74LS245; DIP-20_W7.62mm_Socket
U_CPU_DECODER_1: 74LS154; DIP-24_W15.24mm_Socket
U_DECODER_PLD1: 22V10C; DIP-24_W7.62mm_Socket
U_RAM_1: EB6502_isc61c1024-15n; DIP-32_W7.62mm
U_ROM_1: 28C256; DIP-28_W15.24mm_Socket

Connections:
CA0: JDEVICES1.37, U_6502_1.9 (A0), U_BUS_A_LOW_1.2 (A0), U_ROM_1.10 (A0); also elsewhere on the board
CA1: JDEVICES1.35, U_6502_1.10 (A1), U_BUS_A_LOW_1.3 (A1), U_ROM_1.9 (A1); also elsewhere on the board
CA2: JDEVICES1.33, U_6502_1.11 (A2), U_BUS_A_LOW_1.4 (A2), U_ROM_1.8 (A2); also elsewhere on the board
CA3: JDEVICES1.31, U_6502_1.12 (A3), U_BUS_A_LOW_1.5 (A3), U_ROM_1.7 (A3); also elsewhere on the board
CA4: JDEVICES1.29, U_6502_1.13 (A4), U_BUS_A_LOW_1.6 (A4), U_CPU_DECODER_1.23 (A0), U_ROM_1.6 (A4)
CA5: JDEVICES1.27, U_6502_1.14 (A5), U_BUS_A_LOW_1.7 (A5), U_CPU_DECODER_1.22 (A1), U_ROM_1.5 (A5)
CA6: JDEVICES1.25, U_6502_1.15 (A6), U_BUS_A_LOW_1.8 (A6), U_CPU_DECODER_1.21 (A2), U_ROM_1.4 (A6)
CA7: JDEVICES1.23, U_6502_1.16 (A7), U_BUS_A_LOW_1.9 (A7), U_CPU_DECODER_1.20 (A3), U_ROM_1.3 (A7)
CA8: JDEVICES1.15, U_6502_1.17 (A8), U_BUS_A_HIGH1.2 (A0), U_DECODER_PLD1.10 (IN10), U_ROM_1.25 (A8)
CA9: JDEVICES1.13, U_6502_1.18 (A9), U_BUS_A_HIGH1.3 (A1), U_DECODER_PLD1.9 (IN9), U_ROM_1.24 (A9)
CA10: JDEVICES1.11, U_6502_1.19 (A10), U_BUS_A_HIGH1.4 (A2), U_DECODER_PLD1.8 (IN8), U_ROM_1.21 (A10)
CA11: JDEVICES1.9, U_6502_1.20 (A11), U_BUS_A_HIGH1.5 (A3), U_DECODER_PLD1.7 (IN7), U_ROM_1.23 (A11)
CA12: JDEVICES1.7, U_6502_1.22 (A12), U_BUS_A_HIGH1.6 (A4), U_DECODER_PLD1.6 (IN6), U_ROM_1.2 (A12)
CA13: JDEVICES1.5, U_6502_1.23 (A13), U_BUS_A_HIGH1.7 (A5), U_DECODER_PLD1.5 (IN5), U_ROM_1.26 (A13)
CA14: JDEVICES1.3, U_6502_1.24 (A14), U_BUS_A_HIGH1.8 (A6), U_DECODER_PLD1.4 (IN4/PD), U_ROM_1.1 (A14)
CA15: JDEVICES1.1, U_6502_1.25 (A15), U_BUS_A_HIGH1.9 (A7), U_DECODER_PLD1.3 (IN3)
CD0: JDEVICES1.2, U_6502_1.33 (D0), U_BUS_DATA_1.18 (B0), U_ROM_1.11 (D0); also elsewhere on the board
CD1: JDEVICES1.4, U_6502_1.32 (D1), U_BUS_DATA_1.17 (B1), U_ROM_1.12 (D1); also elsewhere on the board
CD2: JDEVICES1.6, U_6502_1.31 (D2), U_BUS_DATA_1.16 (B2), U_ROM_1.13 (D2); also elsewhere on the board
CD3: JDEVICES1.8, U_6502_1.30 (D3), U_BUS_DATA_1.15 (B3), U_ROM_1.15 (D3); also elsewhere on the board
CD4: JDEVICES1.10, U_6502_1.29 (D4), U_BUS_DATA_1.14 (B4), U_ROM_1.16 (D4); also elsewhere on the board
CD5: JDEVICES1.12, U_6502_1.28 (D5), U_BUS_DATA_1.13 (B5), U_ROM_1.17 (D5); also elsewhere on the board
CD6: JDEVICES1.14, U_6502_1.27 (D6), U_BUS_DATA_1.12 (B6), U_ROM_1.18 (D6); also elsewhere on the board
CD7: JDEVICES1.16, U_6502_1.26 (D7), U_BUS_DATA_1.11 (B7), U_ROM_1.19 (D7); also elsewhere on the board
GND: C1.2, C2.2, C3.2, C4.2, C5.2, C6.2, C7.2, C8.2, C9.2, C_RESET_1.2, D20.2 (A), JDEVICES1.17, JDEVICES1.18, JDEVICES1.21, JDEVICES1.36, JDEVICES1.40, SW1.1, U_6502_1.21 (GND), U_BUS_A_HIGH1.10 (GND), U_BUS_A_LOW_1.10 (GND), U_BUS_DATA_1.10 (GND), U_CPU_DECODER_1.12 (GND), U_DECODER_PLD1.12 (GND), U_RAM_1.16 (GND), U_ROM_1.14 (GND); also elsewhere on the board
unnamed: D20.1 (K), R_POWER1.1
unnamed: R1.1, U_6502_1.2 (RDY)
unnamed: R2.1, U_6502_1.38 (~SO)
unnamed: R3.1, U_6502_1.36 (BE)
unnamed: U_AND_OUT1.3, U_AND_OUT1.4
PLD22: JDEVICES1.28, U_DECODER_PLD1.22 (IO21)
R~W: U_6502_1.34 (R/~W), U_BUS_DATA_1.1 (A->B), U_DECODER_PLD1.2 (IN2); also elsewhere on the board
VA0: U_BUS_A_LOW_1.18 (B0), U_RAM_1.12 (A0); also elsewhere on the board
VA1: U_BUS_A_LOW_1.17 (B1), U_RAM_1.11 (A1); also elsewhere on the board
VA2: U_BUS_A_LOW_1.16 (B2), U_RAM_1.10 (A2); also elsewhere on the board
VA3: U_BUS_A_LOW_1.15 (B3), U_RAM_1.9 (A3); also elsewhere on the board
VA4: U_BUS_A_LOW_1.14 (B4), U_RAM_1.8 (A4); also elsewhere on the board
VA5: U_BUS_A_LOW_1.13 (B5), U_RAM_1.7 (A5); also elsewhere on the board
VA6: U_BUS_A_LOW_1.12 (B6), U_RAM_1.6 (A6); also elsewhere on the board
VA7: U_BUS_A_LOW_1.11 (B7), U_RAM_1.5 (A7); also elsewhere on the board
VA8: U_BUS_A_HIGH1.18 (B0), U_RAM_1.27 (A8); also elsewhere on the board
VA9: U_BUS_A_HIGH1.17 (B1), U_RAM_1.26 (A9); also elsewhere on the board
VA10: U_BUS_A_HIGH1.16 (B2), U_RAM_1.23 (A10); also elsewhere on the board
VA11: U_BUS_A_HIGH1.15 (B3), U_RAM_1.25 (A11); also elsewhere on the board
VA12: U_BUS_A_HIGH1.14 (B4), U_RAM_1.4 (A12); also elsewhere on the board
VA13: U_BUS_A_HIGH1.13 (B5), U_RAM_1.28 (A13); also elsewhere on the board
VA14: U_BUS_A_HIGH1.12 (B6), U_RAM_1.3 (A14); also elsewhere on the board
VA15: U_BUS_A_HIGH1.11 (B7), U_RAM_1.31 (A15); also elsewhere on the board
VCC: C1.1, C2.1, C3.1, C4.1, C5.1, C6.1, C7.1, C8.1, C9.1, JDEVICES1.19, JDEVICES1.38, R1.2, R2.2, R3.2, R4.2, R5.2, R6.2, R_POWER1.2, R_RESET_1.1, U_6502_1.8 (VCC), U_BUS_A_HIGH1.1 (A->B), U_BUS_A_HIGH1.20 (VCC), U_BUS_A_LOW_1.1 (A->B), U_BUS_A_LOW_1.20 (VCC), U_BUS_DATA_1.20 (VCC), U_CPU_DECODER_1.24 (VCC), U_DECODER_PLD1.24 (VCC), U_RAM_1.30 (CE2), U_RAM_1.32 (VCC), U_ROM_1.27 (~WE), U_ROM_1.28 (VCC); also elsewhere on the board
VD0: U_BUS_DATA_1.2 (A0), U_RAM_1.13 (D0); also elsewhere on the board
VD1: U_BUS_DATA_1.3 (A1), U_RAM_1.14 (D1); also elsewhere on the board
VD2: U_BUS_DATA_1.4 (A2), U_RAM_1.15 (D2); also elsewhere on the board
VD3: U_BUS_DATA_1.5 (A3), U_RAM_1.17 (D3); also elsewhere on the board
VD4: U_BUS_DATA_1.6 (A4), U_RAM_1.18 (D4); also elsewhere on the board
VD5: U_BUS_DATA_1.7 (A5), U_RAM_1.19 (D5); also elsewhere on the board
VD6: U_BUS_DATA_1.8 (A6), U_RAM_1.20 (D6); also elsewhere on the board
VD7: U_BUS_DATA_1.9 (A7), U_RAM_1.21 (D7); also elsewhere on the board
VIDBUS: U_DECODER_PLD1.11 (IN11); also elsewhere on the board
VIDENABLE: U_DECODER_PLD1.13 (IN12); also elsewhere on the board
~CPUBUS_CS: U_BUS_A_HIGH1.19 (CE), U_BUS_A_LOW_1.19 (CE), U_BUS_DATA_1.19 (CE), U_DECODER_PLD1.23 (IO22)
~CS_ACIA: U_CPU_DECODER_1.1 (S0); also elsewhere on the board
~CS_IO2: JDEVICES1.20, U_CPU_DECODER_1.3 (S2)
~CS_IO3: JDEVICES1.22, U_CPU_DECODER_1.4 (S3)
~CS_RAM: U_DECODER_PLD1.17 (IO16), U_RAM_1.22 (~CE1)
~CS_ROMDISK: U_CPU_DECODER_1.5 (S4); also elsewhere on the board
~CS_ROM: U_DECODER_PLD1.16 (IO15), U_ROM_1.20 (~CE)
~CS_VIA1: U_CPU_DECODER_1.2 (S1); also elsewhere on the board
~Device: U_CPU_DECODER_1.18 (E0), U_CPU_DECODER_1.19 (E1), U_DECODER_PLD1.21 (IO20)
~IRQEXT: JDEVICES1.30, R6.1, U_AND_OUT1.5
~IRQ_ACIA: R5.1, U_AND_OUT1.2; also elsewhere on the board
~IRQ_VIA1: U_AND_OUT1.1; also elsewhere on the board
~IRQ: U_6502_1.4 (~IRQ), U_AND_OUT1.6
~NMI: JDEVICES1.32, R4.1, U_6502_1.6 (~NMI)
~OE: JDEVICES1.26, U_DECODER_PLD1.14 (IO13), U_RAM_1.24 (~OE), U_ROM_1.22 (~OE)
~RESET: C_RESET_1.1, JDEVICES1.34, R_RESET_1.2, SW1.2, U_6502_1.40 (~RESET); also elsewhere on the board
~WE: JDEVICES1.24, U_DECODER_PLD1.15 (IO14), U_RAM_1.29 (~WE)

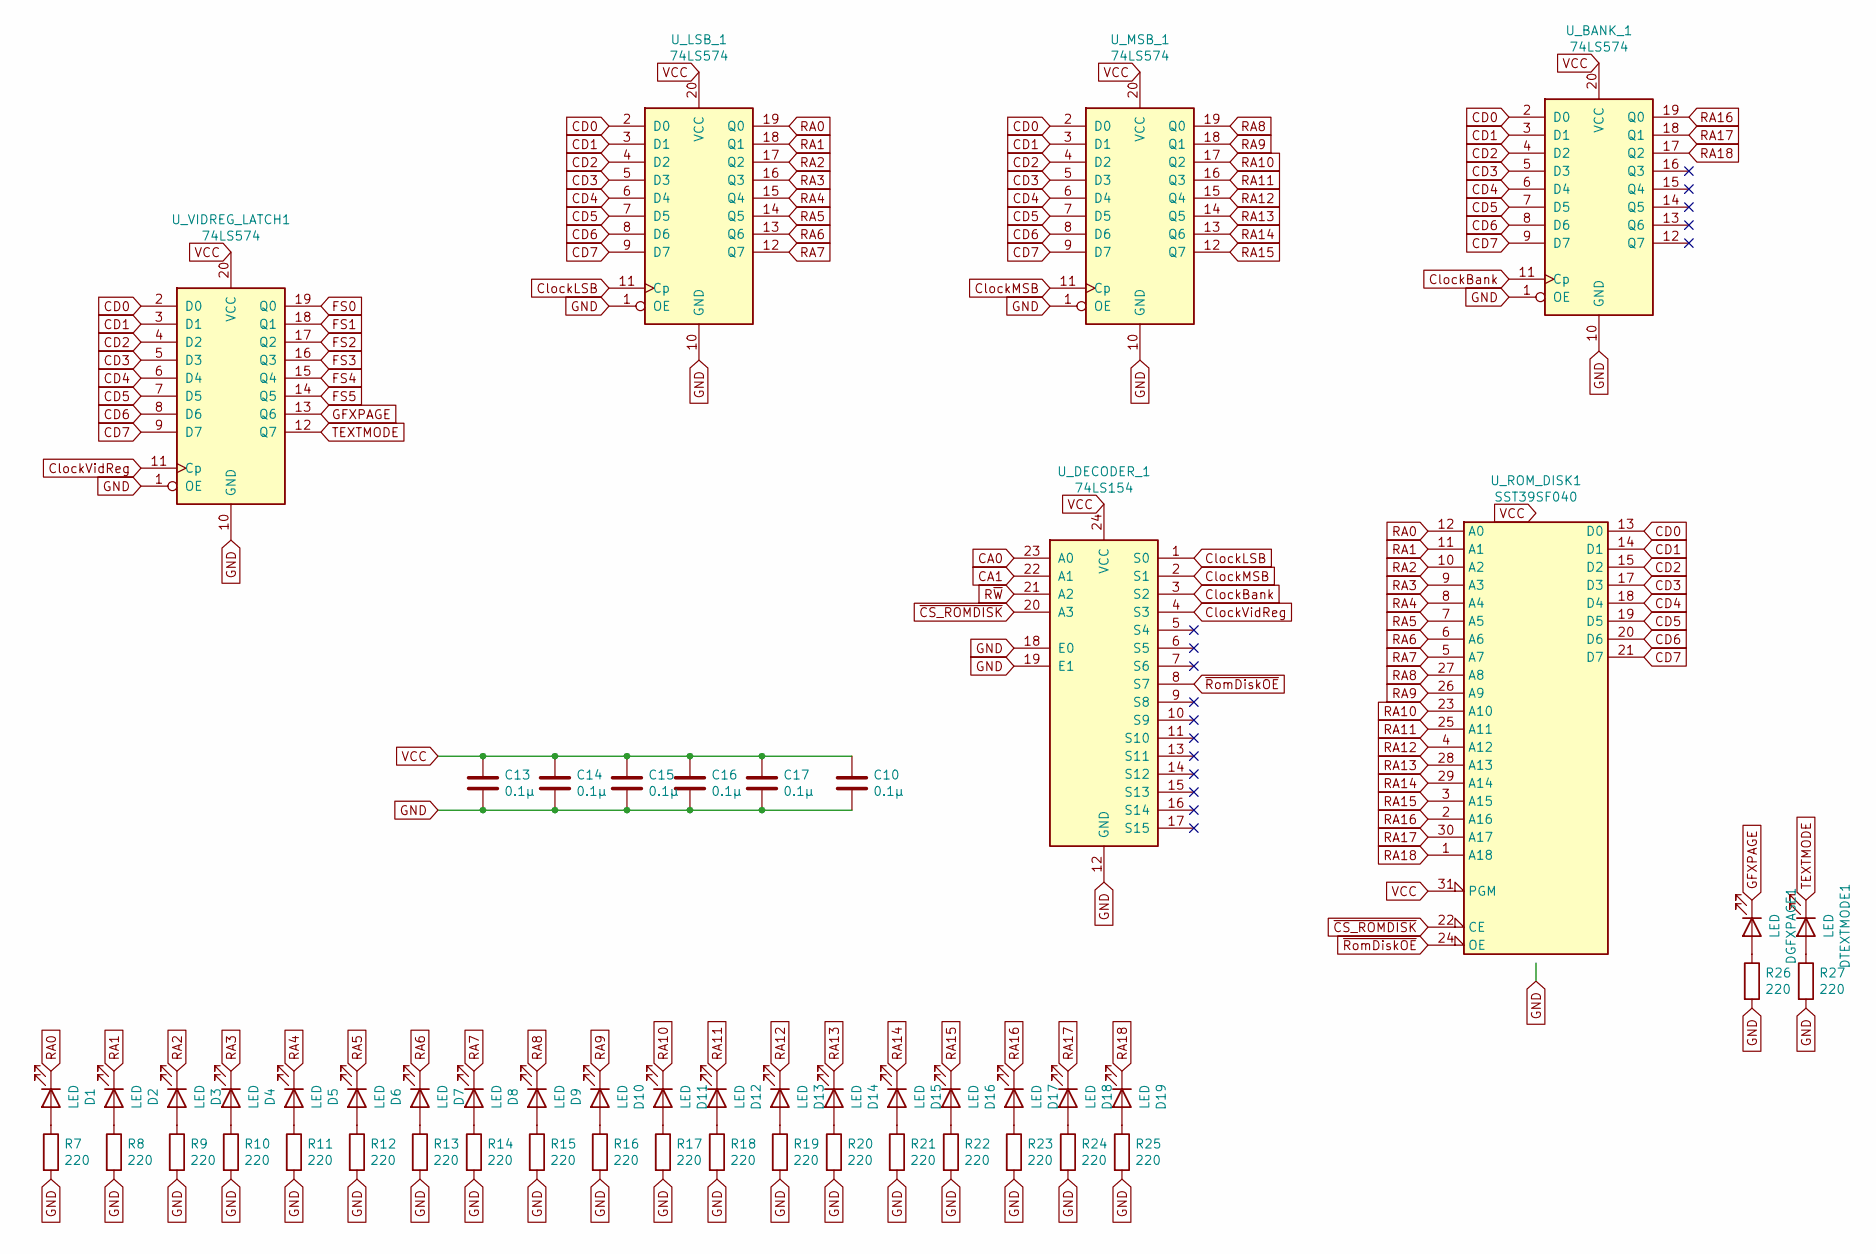
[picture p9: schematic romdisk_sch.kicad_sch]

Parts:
C10, C13, C14, C15, C16, C17: 0.1µ; C_Axial_L3.8mm_D2.6mm_P7.50mm_Horizontal
D1, D2, D3, D4, D5, D6, D7, D8, D9, D10, D11, D12, D13, D14, D15, D16, D17, D18, D19: LED; LED_D3.0mm
DGFXPAGE1: LED; LED_D3.0mm
DTEXTMODE1: LED; LED_D3.0mm
R7, R8, R9, R10, R11, R12, R13, R14, R15, R16, R17, R18, R19, R20, R21, R22, R23, R24, R25, R26, R27: 220; R_Axial_DIN0207_L6.3mm_D2.5mm_P7.62mm_Horizontal
U_BANK_1: 74LS574; DIP-20_W7.62mm_Socket
U_DECODER_1: 74LS154; DIP-24_W15.24mm_Socket
U_LSB_1: 74LS574; DIP-20_W7.62mm_Socket
U_MSB_1: 74LS574; DIP-20_W7.62mm_Socket
U_ROM_DISK1: SST39SF040; DIP-32_W15.24mm_Socket
U_VIDREG_LATCH1: 74LS574; DIP-20_W7.62mm_Socket

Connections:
CA0: U_DECODER_1.23 (A0); also elsewhere on the board
CA1: U_DECODER_1.22 (A1); also elsewhere on the board
CD0: U_BANK_1.2 (D0), U_LSB_1.2 (D0), U_MSB_1.2 (D0), U_ROM_DISK1.13 (D0), U_VIDREG_LATCH1.2 (D0); also elsewhere on the board
CD1: U_BANK_1.3 (D1), U_LSB_1.3 (D1), U_MSB_1.3 (D1), U_ROM_DISK1.14 (D1), U_VIDREG_LATCH1.3 (D1); also elsewhere on the board
CD2: U_BANK_1.4 (D2), U_LSB_1.4 (D2), U_MSB_1.4 (D2), U_ROM_DISK1.15 (D2), U_VIDREG_LATCH1.4 (D2); also elsewhere on the board
CD3: U_BANK_1.5 (D3), U_LSB_1.5 (D3), U_MSB_1.5 (D3), U_ROM_DISK1.17 (D3), U_VIDREG_LATCH1.5 (D3); also elsewhere on the board
CD4: U_BANK_1.6 (D4), U_LSB_1.6 (D4), U_MSB_1.6 (D4), U_ROM_DISK1.18 (D4), U_VIDREG_LATCH1.6 (D4); also elsewhere on the board
CD5: U_BANK_1.7 (D5), U_LSB_1.7 (D5), U_MSB_1.7 (D5), U_ROM_DISK1.19 (D5), U_VIDREG_LATCH1.7 (D5); also elsewhere on the board
CD6: U_BANK_1.8 (D6), U_LSB_1.8 (D6), U_MSB_1.8 (D6), U_ROM_DISK1.20 (D6), U_VIDREG_LATCH1.8 (D6); also elsewhere on the board
CD7: U_BANK_1.9 (D7), U_LSB_1.9 (D7), U_MSB_1.9 (D7), U_ROM_DISK1.21 (D7), U_VIDREG_LATCH1.9 (D7); also elsewhere on the board
ClockBank: U_BANK_1.11 (Cp), U_DECODER_1.3 (S2)
ClockLSB: U_DECODER_1.1 (S0), U_LSB_1.11 (Cp)
ClockMSB: U_DECODER_1.2 (S1), U_MSB_1.11 (Cp)
ClockVidReg: U_DECODER_1.4 (S3), U_VIDREG_LATCH1.11 (Cp)
FS0: U_VIDREG_LATCH1.19 (Q0); also elsewhere on the board
FS1: U_VIDREG_LATCH1.18 (Q1); also elsewhere on the board
FS2: U_VIDREG_LATCH1.17 (Q2); also elsewhere on the board
FS3: U_VIDREG_LATCH1.16 (Q3); also elsewhere on the board
FS4: U_VIDREG_LATCH1.15 (Q4); also elsewhere on the board
FS5: U_VIDREG_LATCH1.14 (Q5); also elsewhere on the board
GFXPAGE: DGFXPAGE1.1 (K), U_VIDREG_LATCH1.13 (Q6); also elsewhere on the board
GND: C10.2, C13.2, C14.2, C15.2, C16.2, C17.2, R7.2, R8.2, R9.2, R10.2, R11.2, R12.2, R13.2, R14.2, R15.2, R16.2, R17.2, R18.2, R19.2, R20.2, R21.2, R22.2, R23.2, R24.2, R25.2, R26.2, R27.2, U_BANK_1.1 (OE), U_BANK_1.10 (GND), U_DECODER_1.12 (GND), U_DECODER_1.18 (E0), U_DECODER_1.19 (E1), U_LSB_1.1 (OE), U_LSB_1.10 (GND), U_MSB_1.1 (OE), U_MSB_1.10 (GND), U_ROM_DISK1.16 (GND), U_VIDREG_LATCH1.1 (OE), U_VIDREG_LATCH1.10 (GND); also elsewhere on the board
unnamed: D1.2 (A), R7.1
unnamed: D2.2 (A), R8.1
unnamed: D3.2 (A), R9.1
unnamed: D4.2 (A), R10.1
unnamed: D5.2 (A), R11.1
unnamed: D6.2 (A), R12.1
unnamed: D7.2 (A), R13.1
unnamed: D8.2 (A), R14.1
unnamed: D9.2 (A), R15.1
unnamed: D10.2 (A), R16.1
unnamed: D11.2 (A), R17.1
unnamed: D12.2 (A), R18.1
unnamed: D13.2 (A), R19.1
unnamed: D14.2 (A), R20.1
unnamed: D15.2 (A), R21.1
unnamed: D16.2 (A), R22.1
unnamed: D17.2 (A), R23.1
unnamed: D18.2 (A), R24.1
unnamed: D19.2 (A), R25.1
unnamed: DGFXPAGE1.2 (A), R26.1
unnamed: DTEXTMODE1.2 (A), R27.1
RA0: D1.1 (K), U_LSB_1.19 (Q0), U_ROM_DISK1.12 (A0)
RA1: D2.1 (K), U_LSB_1.18 (Q1), U_ROM_DISK1.11 (A1)
RA2: D3.1 (K), U_LSB_1.17 (Q2), U_ROM_DISK1.10 (A2)
RA3: D4.1 (K), U_LSB_1.16 (Q3), U_ROM_DISK1.9 (A3)
RA4: D5.1 (K), U_LSB_1.15 (Q4), U_ROM_DISK1.8 (A4)
RA5: D6.1 (K), U_LSB_1.14 (Q5), U_ROM_DISK1.7 (A5)
RA6: D7.1 (K), U_LSB_1.13 (Q6), U_ROM_DISK1.6 (A6)
RA7: D8.1 (K), U_LSB_1.12 (Q7), U_ROM_DISK1.5 (A7)
RA8: D9.1 (K), U_MSB_1.19 (Q0), U_ROM_DISK1.27 (A8)
RA9: D10.1 (K), U_MSB_1.18 (Q1), U_ROM_DISK1.26 (A9)
RA10: D11.1 (K), U_MSB_1.17 (Q2), U_ROM_DISK1.23 (A10)
RA11: D12.1 (K), U_MSB_1.16 (Q3), U_ROM_DISK1.25 (A11)
RA12: D13.1 (K), U_MSB_1.15 (Q4), U_ROM_DISK1.4 (A12)
RA13: D14.1 (K), U_MSB_1.14 (Q5), U_ROM_DISK1.28 (A13)
RA14: D15.1 (K), U_MSB_1.13 (Q6), U_ROM_DISK1.29 (A14)
RA15: D16.1 (K), U_MSB_1.12 (Q7), U_ROM_DISK1.3 (A15)
RA16: D17.1 (K), U_BANK_1.19 (Q0), U_ROM_DISK1.2 (A16)
RA17: D18.1 (K), U_BANK_1.18 (Q1), U_ROM_DISK1.30 (A17)
RA18: D19.1 (K), U_BANK_1.17 (Q2), U_ROM_DISK1.1 (A18)
R~W: U_DECODER_1.21 (A2); also elsewhere on the board
TEXTMODE: DTEXTMODE1.1 (K), U_VIDREG_LATCH1.12 (Q7); also elsewhere on the board
VCC: C10.1, C13.1, C14.1, C15.1, C16.1, C17.1, U_BANK_1.20 (VCC), U_DECODER_1.24 (VCC), U_LSB_1.20 (VCC), U_MSB_1.20 (VCC), U_ROM_DISK1.31 (PGM), U_ROM_DISK1.32 (VCC), U_VIDREG_LATCH1.20 (VCC); also elsewhere on the board
~CS_ROMDISK: U_DECODER_1.20 (A3), U_ROM_DISK1.22 (CE); also elsewhere on the board
~RomDiskOE: U_DECODER_1.8 (S7), U_ROM_DISK1.24 (OE)

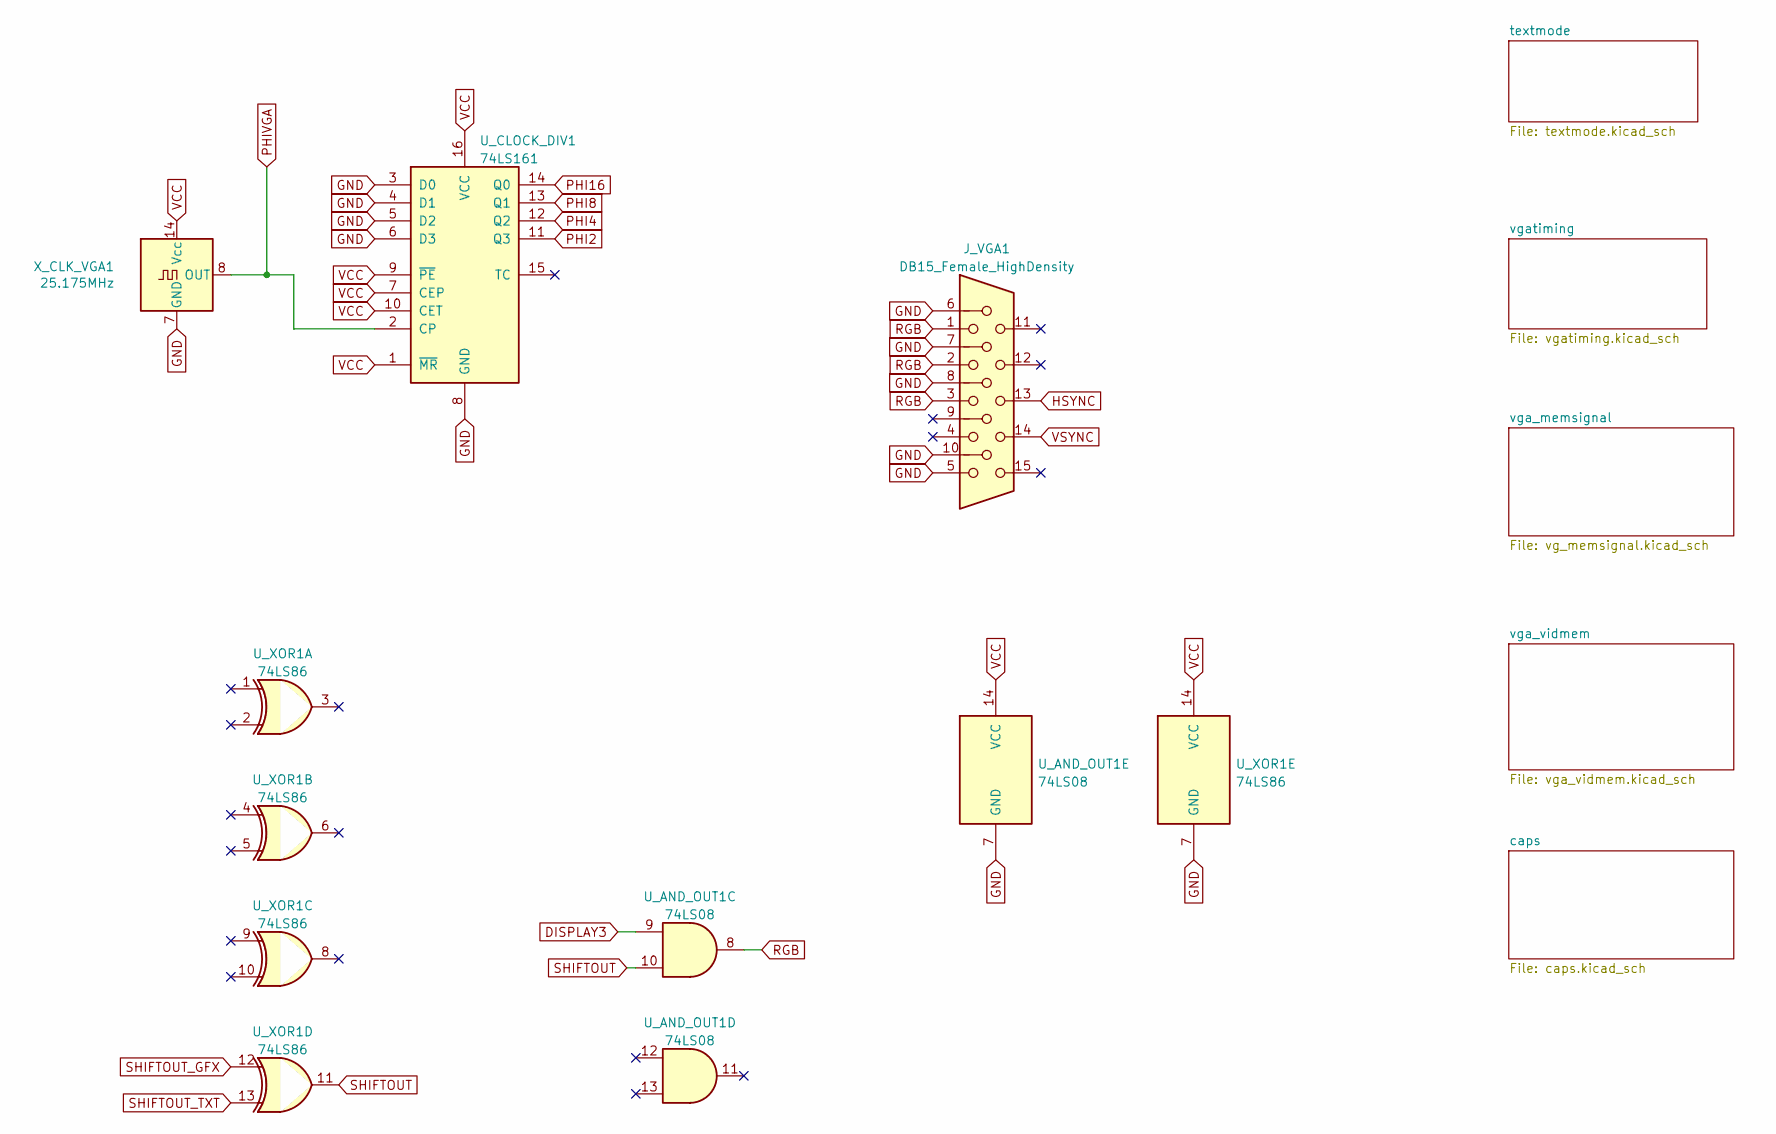
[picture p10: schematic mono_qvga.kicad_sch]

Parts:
J_VGA1: DB15_Female_HighDensity; DSUB-15-HD_Female_Horizontal_P2.29x1.98mm_EdgePinOffset8.35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
U_AND_OUT1: 74LS08; DIP-14_W7.62mm_Socket
U_CLOCK_DIV1: 74LS161; DIP-16_W7.62mm_Socket
U_XOR1: 74LS86; DIP-14_W7.62mm_Socket
X_CLK_VGA1: 25.175MHz; Oscillator_DIP-14

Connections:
DISPLAY3: U_AND_OUT1.9; also elsewhere on the board
GND: J_VGA1.5, J_VGA1.6, J_VGA1.7, J_VGA1.8, J_VGA1.10, U_AND_OUT1.7 (GND), U_CLOCK_DIV1.3 (D0), U_CLOCK_DIV1.4 (D1), U_CLOCK_DIV1.5 (D2), U_CLOCK_DIV1.6 (D3), U_CLOCK_DIV1.8 (GND), U_XOR1.7 (GND), X_CLK_VGA1.7 (GND); also elsewhere on the board
HSYNC: J_VGA1.13; also elsewhere on the board
PHI8: U_CLOCK_DIV1.13 (Q1); also elsewhere on the board
PHI16: U_CLOCK_DIV1.14 (Q0); also elsewhere on the board
PHIVGA: U_CLOCK_DIV1.2 (CP), X_CLK_VGA1.8 (OUT)
RGB: J_VGA1.1, J_VGA1.2, J_VGA1.3, U_AND_OUT1.8
SHIFTOUT: U_AND_OUT1.10, U_XOR1.11
SHIFTOUT_GFX: U_XOR1.12; also elsewhere on the board
SHIFTOUT_TXT: U_XOR1.13; also elsewhere on the board
VCC: U_AND_OUT1.14 (VCC), U_CLOCK_DIV1.1 (~MR), U_CLOCK_DIV1.7 (CEP), U_CLOCK_DIV1.9 (~PE), U_CLOCK_DIV1.10 (CET), U_CLOCK_DIV1.16 (VCC), U_XOR1.14 (VCC), X_CLK_VGA1.14 (Vcc); also elsewhere on the board
VSYNC: J_VGA1.14; also elsewhere on the board

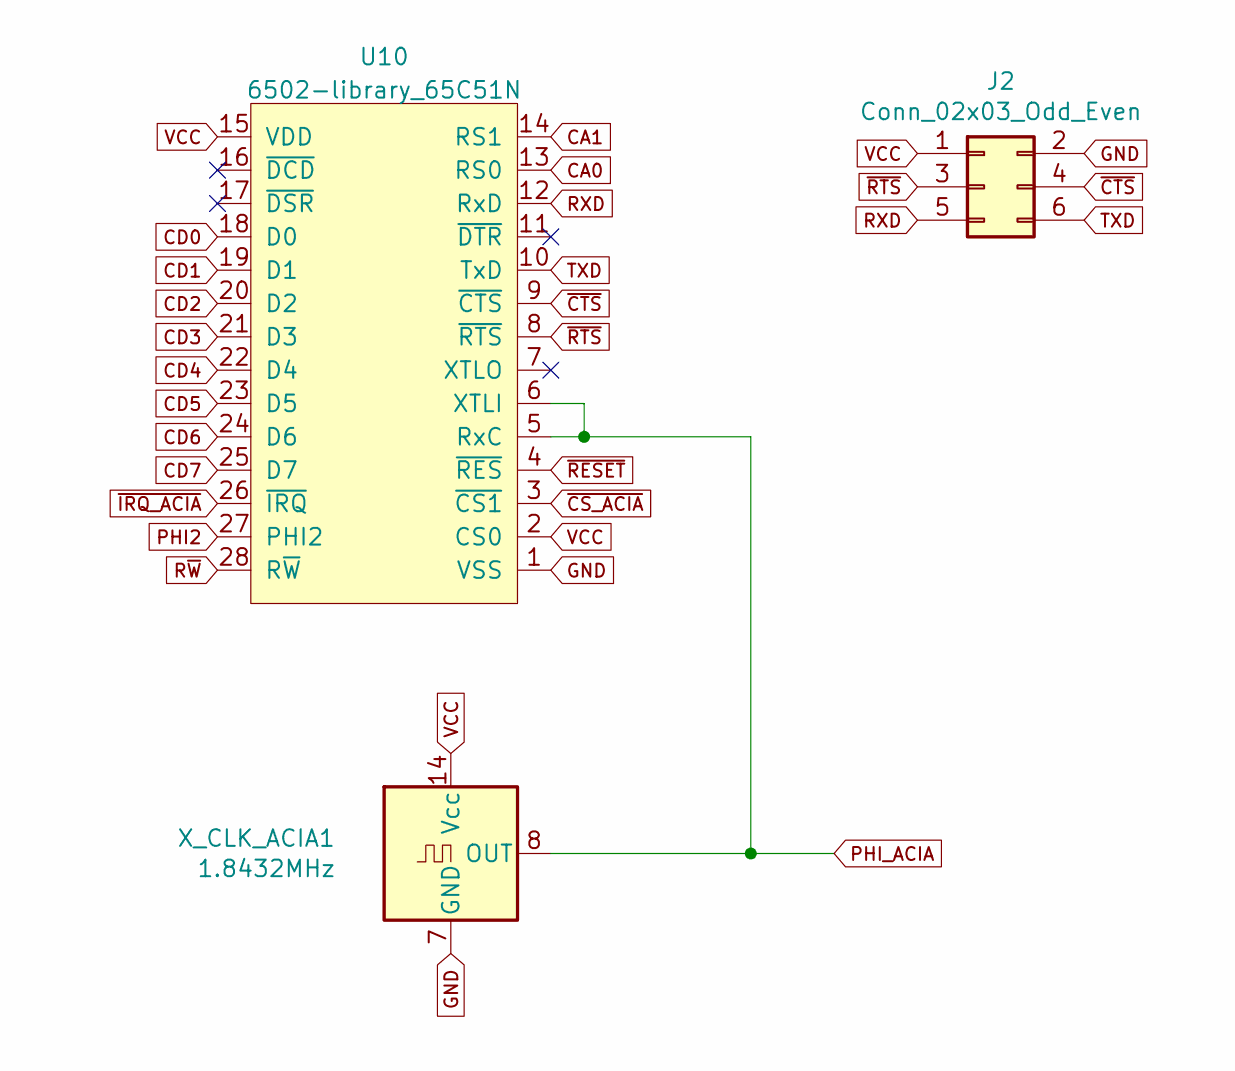
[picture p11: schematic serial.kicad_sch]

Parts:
J2: Conn_02x03_Odd_Even; PinHeader_2x03_P2.54mm_Vertical
U10: 6502-library_65C51N; DIP-28_W15.24mm_Socket
X_CLK_ACIA1: 1.8432MHz; Oscillator_DIP-14

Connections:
CA0: U10.13 (RS0); also elsewhere on the board
CA1: U10.14 (RS1); also elsewhere on the board
CD0: U10.18 (D0); also elsewhere on the board
CD1: U10.19 (D1); also elsewhere on the board
CD2: U10.20 (D2); also elsewhere on the board
CD3: U10.21 (D3); also elsewhere on the board
CD4: U10.22 (D4); also elsewhere on the board
CD5: U10.23 (D5); also elsewhere on the board
CD6: U10.24 (D6); also elsewhere on the board
CD7: U10.25 (D7); also elsewhere on the board
GND: J2.2, U10.1 (VSS), X_CLK_ACIA1.7 (GND); also elsewhere on the board
PHI_ACIA: U10.5 (RxC), U10.6 (XTLI), X_CLK_ACIA1.8 (OUT)
RXD: J2.5, U10.12 (RxD)
R~W: U10.28 (R~W); also elsewhere on the board
TXD: J2.6, U10.10 (TxD)
VCC: J2.1, U10.2 (CS0), U10.15 (VDD), X_CLK_ACIA1.14 (Vcc); also elsewhere on the board
~CS_ACIA: U10.3 (~CS1); also elsewhere on the board
~CTS: J2.4, U10.9 (~CTS)
~IRQ_ACIA: U10.26 (~IRQ); also elsewhere on the board
~RESET: U10.4 (~RES); also elsewhere on the board
~RTS: J2.3, U10.8 (~RTS)

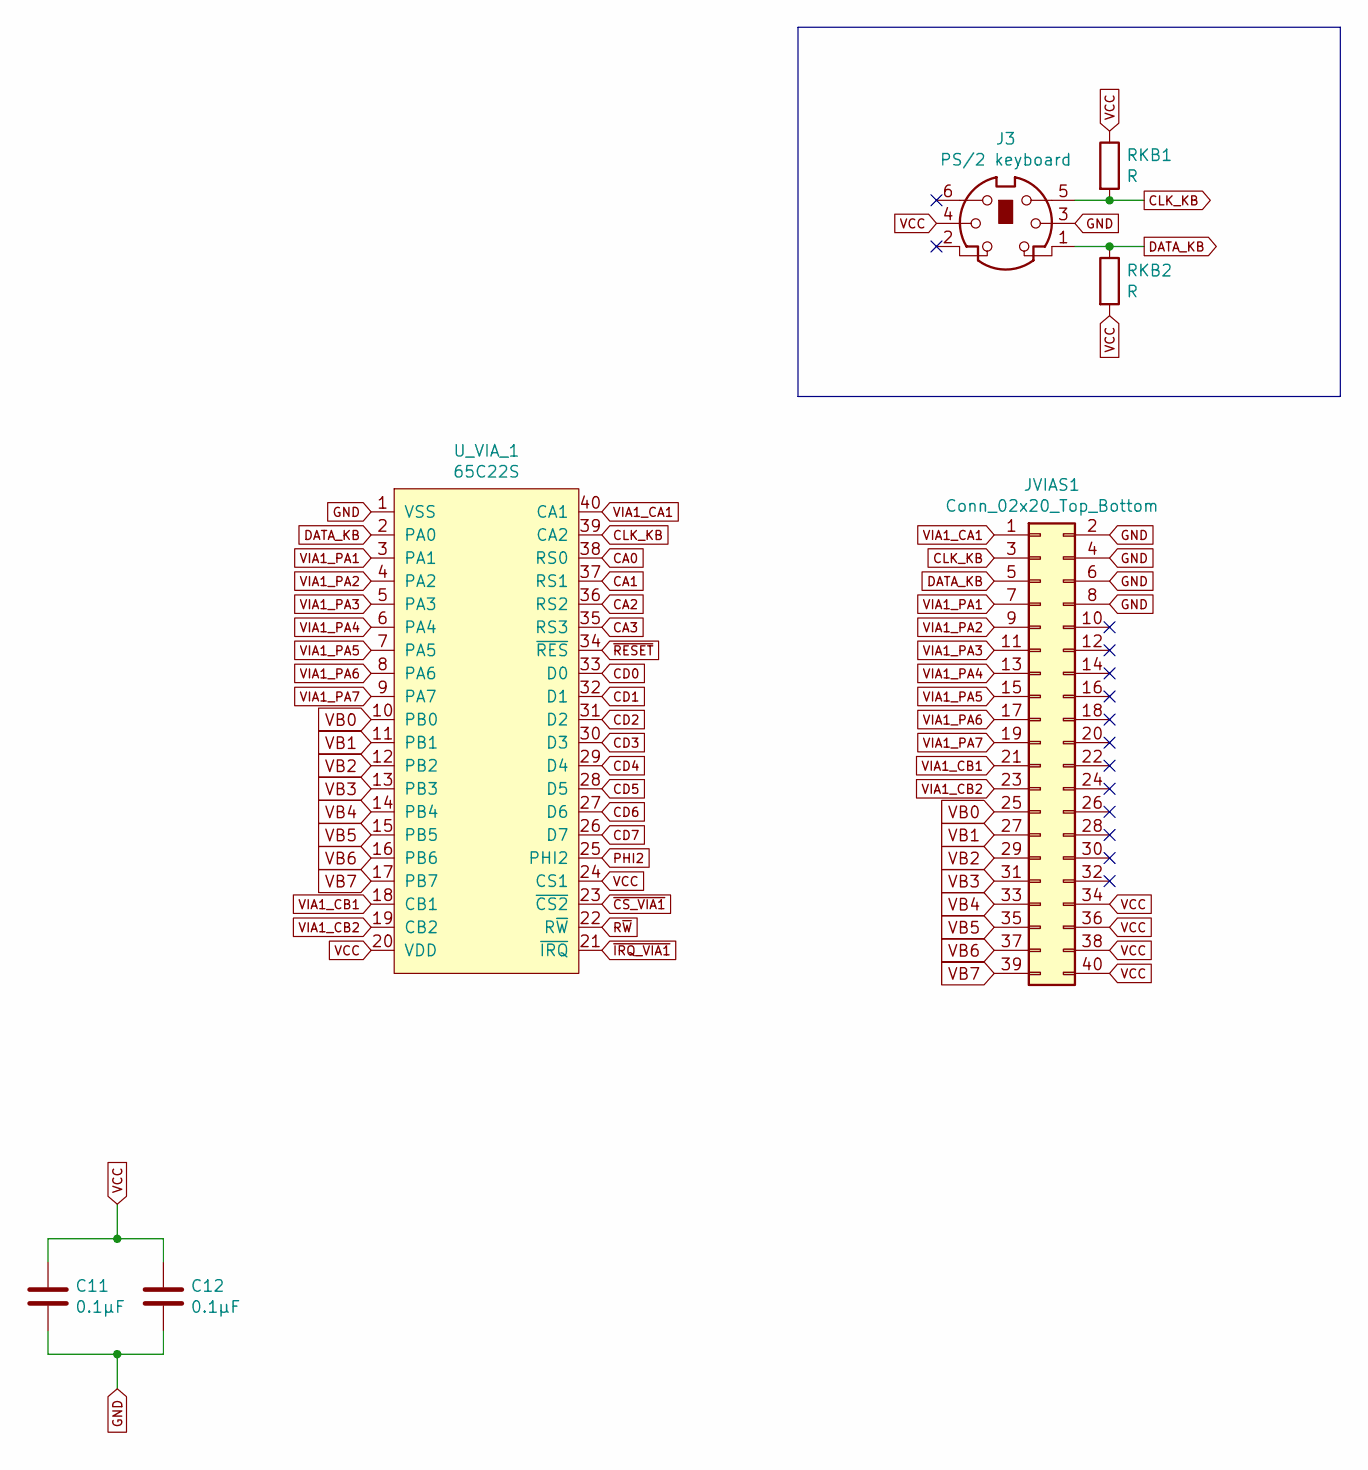
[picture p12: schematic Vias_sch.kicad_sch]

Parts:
C11, C12: 0.1µF; C_Axial_L3.8mm_D2.6mm_P7.50mm_Horizontal
J3: PS/2 keyboard; MINI-DIN-6-FULL-SHIELD
JVIAS1: Conn_02x20_Top_Bottom; IDC-Header_2x20_P2.54mm_Vertical
RKB1, RKB2: R; R_Axial_DIN0207_L6.3mm_D2.5mm_P7.62mm_Horizontal
U_VIA_1: 65C22S; DIP-40_W15.24mm_Socket

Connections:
CA0: U_VIA_1.38 (RS0); also elsewhere on the board
CA1: U_VIA_1.37 (RS1); also elsewhere on the board
CA2: U_VIA_1.36 (RS2); also elsewhere on the board
CA3: U_VIA_1.35 (RS3); also elsewhere on the board
CD0: U_VIA_1.33 (D0); also elsewhere on the board
CD1: U_VIA_1.32 (D1); also elsewhere on the board
CD2: U_VIA_1.31 (D2); also elsewhere on the board
CD3: U_VIA_1.30 (D3); also elsewhere on the board
CD4: U_VIA_1.29 (D4); also elsewhere on the board
CD5: U_VIA_1.28 (D5); also elsewhere on the board
CD6: U_VIA_1.27 (D6); also elsewhere on the board
CD7: U_VIA_1.26 (D7); also elsewhere on the board
CLK_KB: J3.5, JVIAS1.3, RKB1.2, U_VIA_1.39 (CA2)
DATA_KB: J3.1, JVIAS1.5, RKB2.1, U_VIA_1.2 (PA0)
GND: C11.2, C12.2, J3.3, JVIAS1.2, JVIAS1.4, JVIAS1.6, JVIAS1.8, U_VIA_1.1 (VSS); also elsewhere on the board
R~W: U_VIA_1.22 (R~W); also elsewhere on the board
VB0: JVIAS1.25, U_VIA_1.10 (PB0)
VB1: JVIAS1.27, U_VIA_1.11 (PB1)
VB2: JVIAS1.29, U_VIA_1.12 (PB2)
VB3: JVIAS1.31, U_VIA_1.13 (PB3)
VB4: JVIAS1.33, U_VIA_1.14 (PB4)
VB5: JVIAS1.35, U_VIA_1.15 (PB5)
VB6: JVIAS1.37, U_VIA_1.16 (PB6)
VB7: JVIAS1.39, U_VIA_1.17 (PB7)
VCC: C11.1, C12.1, J3.4, JVIAS1.34, JVIAS1.36, JVIAS1.38, JVIAS1.40, RKB1.1, RKB2.2, U_VIA_1.20 (VDD), U_VIA_1.24 (CS1); also elsewhere on the board
VIA1_CA1: JVIAS1.1, U_VIA_1.40 (CA1)
VIA1_CB1: JVIAS1.21, U_VIA_1.18 (CB1)
VIA1_CB2: JVIAS1.23, U_VIA_1.19 (CB2)
VIA1_PA1: JVIAS1.7, U_VIA_1.3 (PA1)
VIA1_PA2: JVIAS1.9, U_VIA_1.4 (PA2)
VIA1_PA3: JVIAS1.11, U_VIA_1.5 (PA3)
VIA1_PA4: JVIAS1.13, U_VIA_1.6 (PA4)
VIA1_PA5: JVIAS1.15, U_VIA_1.7 (PA5)
VIA1_PA6: JVIAS1.17, U_VIA_1.8 (PA6)
VIA1_PA7: JVIAS1.19, U_VIA_1.9 (PA7)
~CS_VIA1: U_VIA_1.23 (~CS2); also elsewhere on the board
~IRQ_VIA1: U_VIA_1.21 (~IRQ); also elsewhere on the board
~RESET: U_VIA_1.34 (~RES); also elsewhere on the board

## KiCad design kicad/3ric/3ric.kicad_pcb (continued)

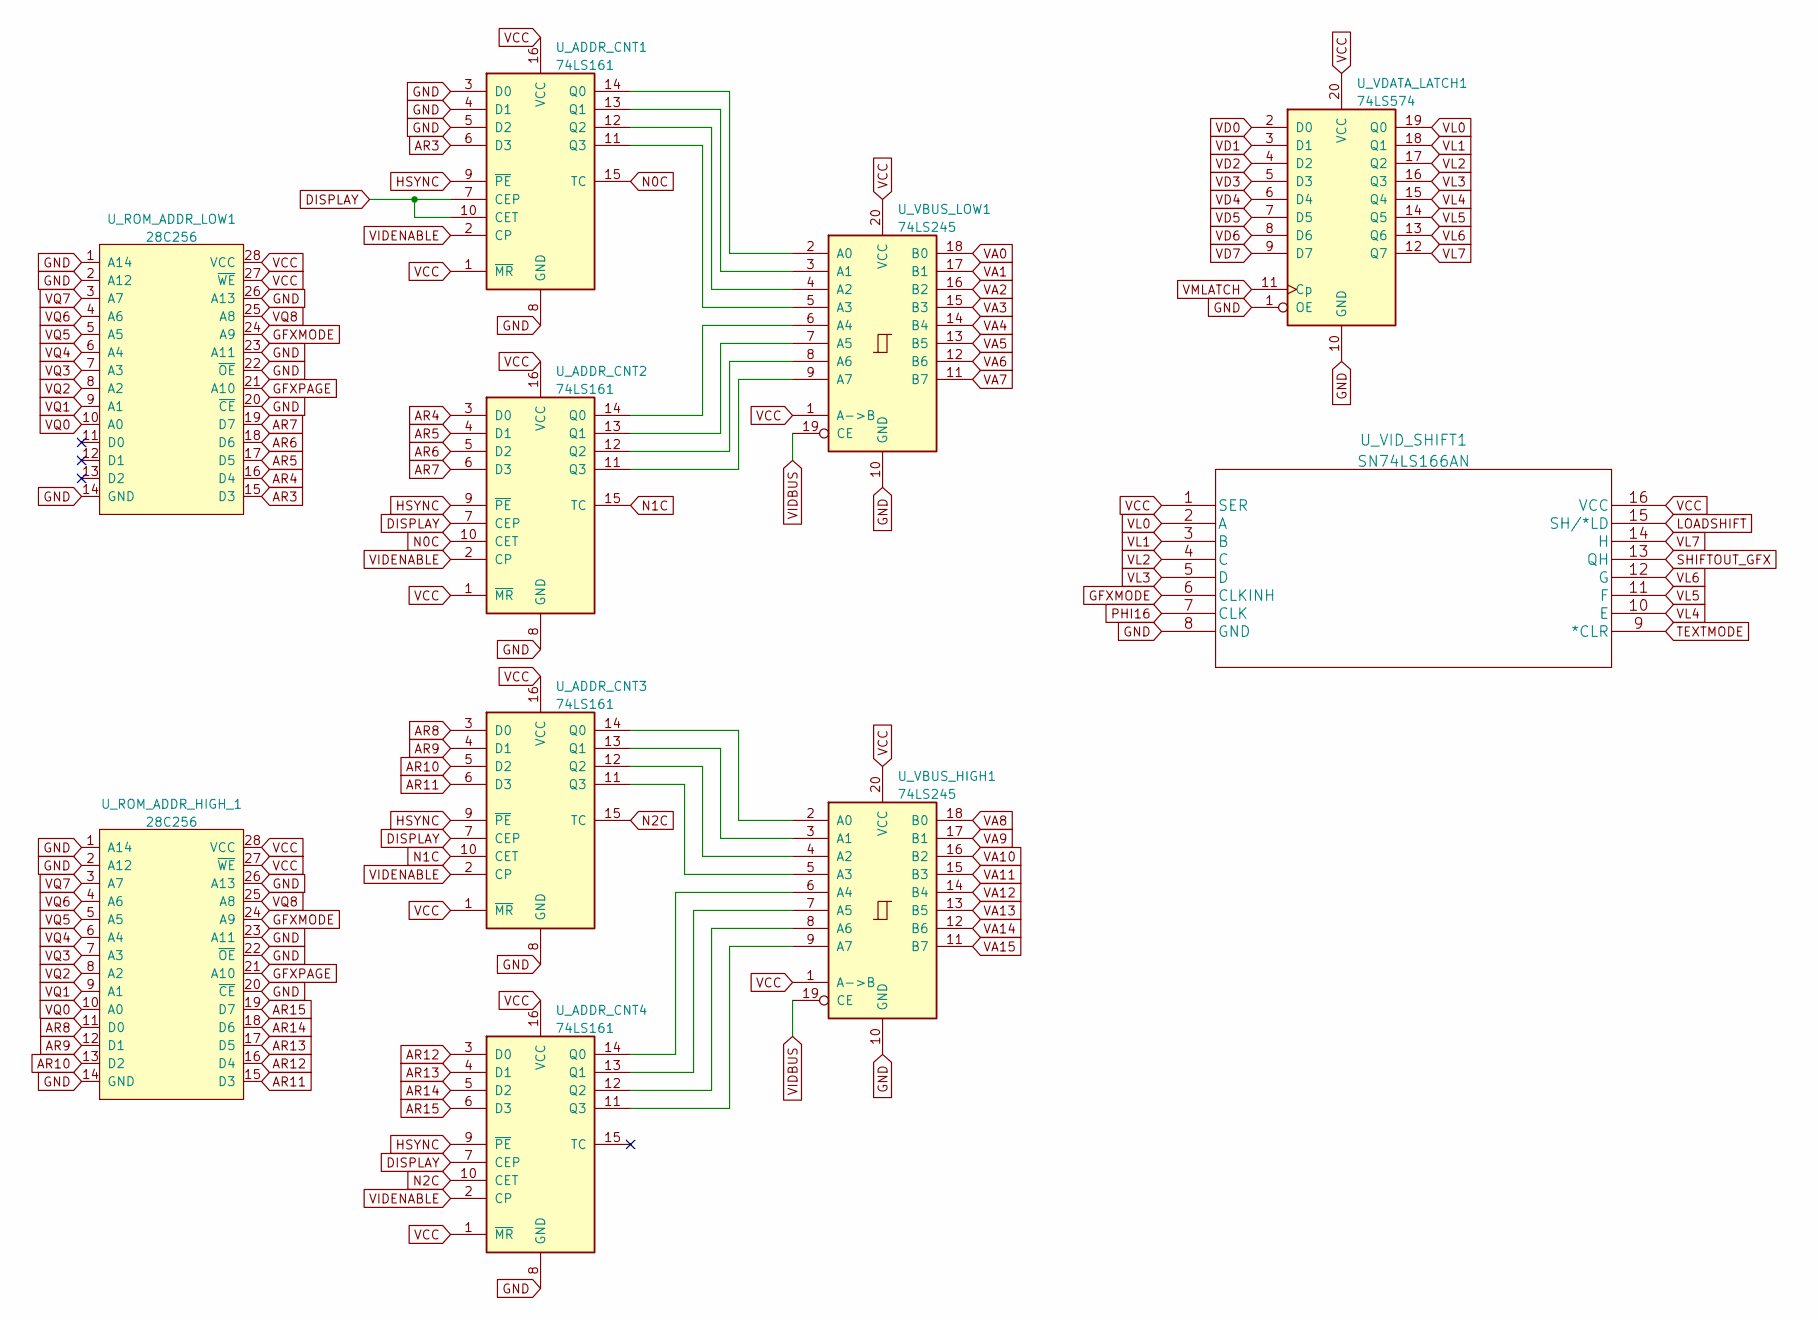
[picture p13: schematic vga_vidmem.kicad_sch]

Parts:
U_ADDR_CNT1, U_ADDR_CNT2, U_ADDR_CNT3, U_ADDR_CNT4: 74LS161; DIP-16_W7.62mm_Socket
U_ROM_ADDR_HIGH_1: 28C256; DIP-28_W15.24mm_Socket
U_ROM_ADDR_LOW1: 28C256; DIP-28_W15.24mm_Socket
U_VBUS_HIGH1: 74LS245; DIP-20_W7.62mm_Socket
U_VBUS_LOW1: 74LS245; DIP-20_W7.62mm_Socket
U_VDATA_LATCH1: 74LS574; DIP-20_W7.62mm_Socket
U_VID_SHIFT1: SN74LS166AN; DIP-16_W7.62mm_Socket

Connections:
AR3: U_ADDR_CNT1.6 (D3), U_ROM_ADDR_LOW1.15 (D3)
AR4: U_ADDR_CNT2.3 (D0), U_ROM_ADDR_LOW1.16 (D4)
AR5: U_ADDR_CNT2.4 (D1), U_ROM_ADDR_LOW1.17 (D5)
AR6: U_ADDR_CNT2.5 (D2), U_ROM_ADDR_LOW1.18 (D6)
AR7: U_ADDR_CNT2.6 (D3), U_ROM_ADDR_LOW1.19 (D7)
AR8: U_ADDR_CNT3.3 (D0), U_ROM_ADDR_HIGH_1.11 (D0)
AR9: U_ADDR_CNT3.4 (D1), U_ROM_ADDR_HIGH_1.12 (D1)
AR10: U_ADDR_CNT3.5 (D2), U_ROM_ADDR_HIGH_1.13 (D2)
AR11: U_ADDR_CNT3.6 (D3), U_ROM_ADDR_HIGH_1.15 (D3)
AR12: U_ADDR_CNT4.3 (D0), U_ROM_ADDR_HIGH_1.16 (D4)
AR13: U_ADDR_CNT4.4 (D1), U_ROM_ADDR_HIGH_1.17 (D5)
AR14: U_ADDR_CNT4.5 (D2), U_ROM_ADDR_HIGH_1.18 (D6)
AR15: U_ADDR_CNT4.6 (D3), U_ROM_ADDR_HIGH_1.19 (D7)
DISPLAY: U_ADDR_CNT1.7 (CEP), U_ADDR_CNT1.10 (CET), U_ADDR_CNT2.7 (CEP), U_ADDR_CNT3.7 (CEP), U_ADDR_CNT4.7 (CEP); also elsewhere on the board
GFXMODE: U_ROM_ADDR_HIGH_1.24 (A9), U_ROM_ADDR_LOW1.24 (A9), U_VID_SHIFT1.6 (CLKINH); also elsewhere on the board
GFXPAGE: U_ROM_ADDR_HIGH_1.21 (A10), U_ROM_ADDR_LOW1.21 (A10); also elsewhere on the board
GND: U_ADDR_CNT1.3 (D0), U_ADDR_CNT1.4 (D1), U_ADDR_CNT1.5 (D2), U_ADDR_CNT1.8 (GND), U_ADDR_CNT2.8 (GND), U_ADDR_CNT3.8 (GND), U_ADDR_CNT4.8 (GND), U_ROM_ADDR_HIGH_1.1 (A14), U_ROM_ADDR_HIGH_1.2 (A12), U_ROM_ADDR_HIGH_1.14 (GND), U_ROM_ADDR_HIGH_1.20 (~CE), U_ROM_ADDR_HIGH_1.22 (~OE), U_ROM_ADDR_HIGH_1.23 (A11), U_ROM_ADDR_HIGH_1.26 (A13), U_ROM_ADDR_LOW1.1 (A14), U_ROM_ADDR_LOW1.2 (A12), U_ROM_ADDR_LOW1.14 (GND), U_ROM_ADDR_LOW1.20 (~CE), U_ROM_ADDR_LOW1.22 (~OE), U_ROM_ADDR_LOW1.23 (A11), U_ROM_ADDR_LOW1.26 (A13), U_VBUS_HIGH1.10 (GND), U_VBUS_LOW1.10 (GND), U_VDATA_LATCH1.1 (OE), U_VDATA_LATCH1.10 (GND), U_VID_SHIFT1.8 (GND); also elsewhere on the board
HSYNC: U_ADDR_CNT1.9 (~PE), U_ADDR_CNT2.9 (~PE), U_ADDR_CNT3.9 (~PE), U_ADDR_CNT4.9 (~PE); also elsewhere on the board
LOADSHIFT: U_VID_SHIFT1.15 (SH/*LD); also elsewhere on the board
N0C: U_ADDR_CNT1.15 (TC), U_ADDR_CNT2.10 (CET)
N1C: U_ADDR_CNT2.15 (TC), U_ADDR_CNT3.10 (CET)
N2C: U_ADDR_CNT3.15 (TC), U_ADDR_CNT4.10 (CET)
unnamed: U_ADDR_CNT1.11 (Q3), U_VBUS_LOW1.5 (A3)
unnamed: U_ADDR_CNT1.12 (Q2), U_VBUS_LOW1.4 (A2)
unnamed: U_ADDR_CNT1.13 (Q1), U_VBUS_LOW1.3 (A1)
unnamed: U_ADDR_CNT1.14 (Q0), U_VBUS_LOW1.2 (A0)
unnamed: U_ADDR_CNT2.11 (Q3), U_VBUS_LOW1.9 (A7)
unnamed: U_ADDR_CNT2.12 (Q2), U_VBUS_LOW1.8 (A6)
unnamed: U_ADDR_CNT2.13 (Q1), U_VBUS_LOW1.7 (A5)
unnamed: U_ADDR_CNT2.14 (Q0), U_VBUS_LOW1.6 (A4)
unnamed: U_ADDR_CNT3.11 (Q3), U_VBUS_HIGH1.5 (A3)
unnamed: U_ADDR_CNT3.12 (Q2), U_VBUS_HIGH1.4 (A2)
unnamed: U_ADDR_CNT3.13 (Q1), U_VBUS_HIGH1.3 (A1)
unnamed: U_ADDR_CNT3.14 (Q0), U_VBUS_HIGH1.2 (A0)
unnamed: U_ADDR_CNT4.11 (Q3), U_VBUS_HIGH1.9 (A7)
unnamed: U_ADDR_CNT4.12 (Q2), U_VBUS_HIGH1.8 (A6)
unnamed: U_ADDR_CNT4.13 (Q1), U_VBUS_HIGH1.7 (A5)
unnamed: U_ADDR_CNT4.14 (Q0), U_VBUS_HIGH1.6 (A4)
PHI16: U_VID_SHIFT1.7 (CLK); also elsewhere on the board
SHIFTOUT_GFX: U_VID_SHIFT1.13 (QH); also elsewhere on the board
TEXTMODE: U_VID_SHIFT1.9 (*CLR); also elsewhere on the board
VA0: U_VBUS_LOW1.18 (B0); also elsewhere on the board
VA1: U_VBUS_LOW1.17 (B1); also elsewhere on the board
VA2: U_VBUS_LOW1.16 (B2); also elsewhere on the board
VA3: U_VBUS_LOW1.15 (B3); also elsewhere on the board
VA4: U_VBUS_LOW1.14 (B4); also elsewhere on the board
VA5: U_VBUS_LOW1.13 (B5); also elsewhere on the board
VA6: U_VBUS_LOW1.12 (B6); also elsewhere on the board
VA7: U_VBUS_LOW1.11 (B7); also elsewhere on the board
VA8: U_VBUS_HIGH1.18 (B0); also elsewhere on the board
VA9: U_VBUS_HIGH1.17 (B1); also elsewhere on the board
VA10: U_VBUS_HIGH1.16 (B2); also elsewhere on the board
VA11: U_VBUS_HIGH1.15 (B3); also elsewhere on the board
VA12: U_VBUS_HIGH1.14 (B4); also elsewhere on the board
VA13: U_VBUS_HIGH1.13 (B5); also elsewhere on the board
VA14: U_VBUS_HIGH1.12 (B6); also elsewhere on the board
VA15: U_VBUS_HIGH1.11 (B7); also elsewhere on the board
VCC: U_ADDR_CNT1.1 (~MR), U_ADDR_CNT1.16 (VCC), U_ADDR_CNT2.1 (~MR), U_ADDR_CNT2.16 (VCC), U_ADDR_CNT3.1 (~MR), U_ADDR_CNT3.16 (VCC), U_ADDR_CNT4.1 (~MR), U_ADDR_CNT4.16 (VCC), U_ROM_ADDR_HIGH_1.27 (~WE), U_ROM_ADDR_HIGH_1.28 (VCC), U_ROM_ADDR_LOW1.27 (~WE), U_ROM_ADDR_LOW1.28 (VCC), U_VBUS_HIGH1.1 (A->B), U_VBUS_HIGH1.20 (VCC), U_VBUS_LOW1.1 (A->B), U_VBUS_LOW1.20 (VCC), U_VDATA_LATCH1.20 (VCC), U_VID_SHIFT1.1 (SER), U_VID_SHIFT1.16 (VCC); also elsewhere on the board
VD0: U_VDATA_LATCH1.2 (D0); also elsewhere on the board
VD1: U_VDATA_LATCH1.3 (D1); also elsewhere on the board
VD2: U_VDATA_LATCH1.4 (D2); also elsewhere on the board
VD3: U_VDATA_LATCH1.5 (D3); also elsewhere on the board
VD4: U_VDATA_LATCH1.6 (D4); also elsewhere on the board
VD5: U_VDATA_LATCH1.7 (D5); also elsewhere on the board
VD6: U_VDATA_LATCH1.8 (D6); also elsewhere on the board
VD7: U_VDATA_LATCH1.9 (D7); also elsewhere on the board
VIDBUS: U_VBUS_HIGH1.19 (CE), U_VBUS_LOW1.19 (CE); also elsewhere on the board
VIDENABLE: U_ADDR_CNT1.2 (CP), U_ADDR_CNT2.2 (CP), U_ADDR_CNT3.2 (CP), U_ADDR_CNT4.2 (CP); also elsewhere on the board
VL0: U_VDATA_LATCH1.19 (Q0), U_VID_SHIFT1.2 (A); also elsewhere on the board
VL1: U_VDATA_LATCH1.18 (Q1), U_VID_SHIFT1.3 (B); also elsewhere on the board
VL2: U_VDATA_LATCH1.17 (Q2), U_VID_SHIFT1.4 (C); also elsewhere on the board
VL3: U_VDATA_LATCH1.16 (Q3), U_VID_SHIFT1.5 (D); also elsewhere on the board
VL4: U_VDATA_LATCH1.15 (Q4), U_VID_SHIFT1.10 (E); also elsewhere on the board
VL5: U_VDATA_LATCH1.14 (Q5), U_VID_SHIFT1.11 (F); also elsewhere on the board
VL6: U_VDATA_LATCH1.13 (Q6), U_VID_SHIFT1.12 (G); also elsewhere on the board
VL7: U_VDATA_LATCH1.12 (Q7), U_VID_SHIFT1.14 (H); also elsewhere on the board
VMLATCH: U_VDATA_LATCH1.11 (Cp); also elsewhere on the board
VQ0: U_ROM_ADDR_HIGH_1.10 (A0), U_ROM_ADDR_LOW1.10 (A0); also elsewhere on the board
VQ1: U_ROM_ADDR_HIGH_1.9 (A1), U_ROM_ADDR_LOW1.9 (A1); also elsewhere on the board
VQ2: U_ROM_ADDR_HIGH_1.8 (A2), U_ROM_ADDR_LOW1.8 (A2); also elsewhere on the board
VQ3: U_ROM_ADDR_HIGH_1.7 (A3), U_ROM_ADDR_LOW1.7 (A3); also elsewhere on the board
VQ4: U_ROM_ADDR_HIGH_1.6 (A4), U_ROM_ADDR_LOW1.6 (A4); also elsewhere on the board
VQ5: U_ROM_ADDR_HIGH_1.5 (A5), U_ROM_ADDR_LOW1.5 (A5); also elsewhere on the board
VQ6: U_ROM_ADDR_HIGH_1.4 (A6), U_ROM_ADDR_LOW1.4 (A6); also elsewhere on the board
VQ7: U_ROM_ADDR_HIGH_1.3 (A7), U_ROM_ADDR_LOW1.3 (A7); also elsewhere on the board
VQ8: U_ROM_ADDR_HIGH_1.25 (A8), U_ROM_ADDR_LOW1.25 (A8); also elsewhere on the board

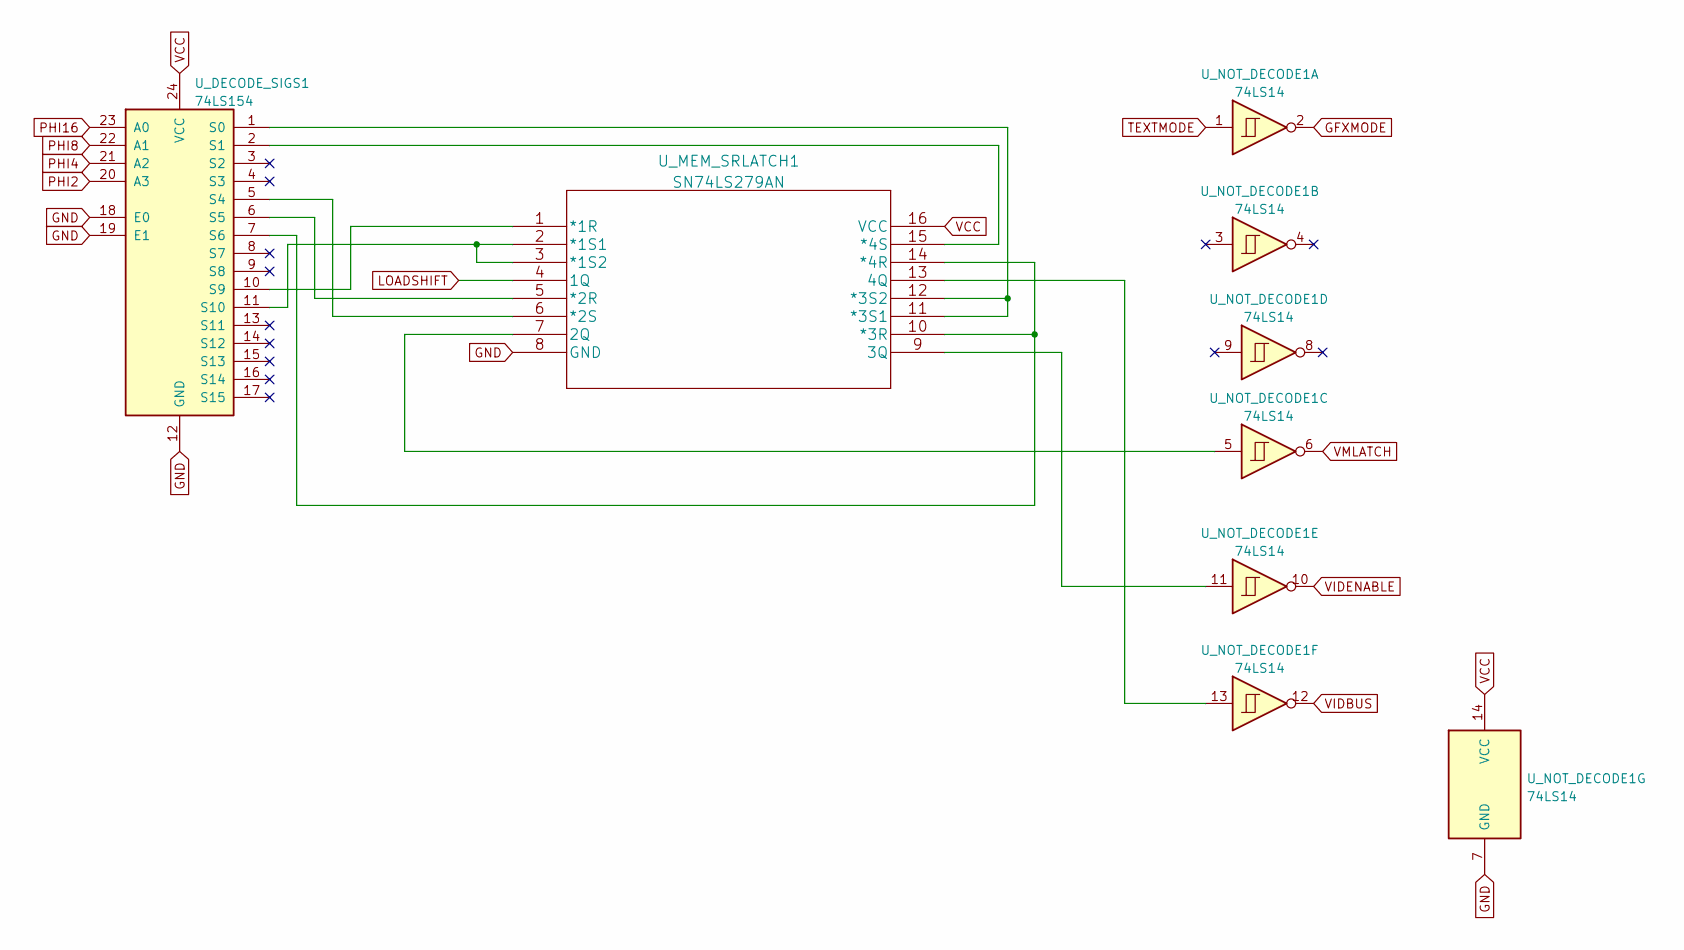
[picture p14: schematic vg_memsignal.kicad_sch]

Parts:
U_DECODE_SIGS1: 74LS154; DIP-24_W15.24mm_Socket
U_MEM_SRLATCH1: SN74LS279AN; DIP-16_W7.62mm_Socket
U_NOT_DECODE1: 74LS14; DIP-14_W7.62mm_Socket

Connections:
GFXMODE: U_NOT_DECODE1.2; also elsewhere on the board
GND: U_DECODE_SIGS1.12 (GND), U_DECODE_SIGS1.18 (E0), U_DECODE_SIGS1.19 (E1), U_MEM_SRLATCH1.8 (GND), U_NOT_DECODE1.7 (GND); also elsewhere on the board
LOADSHIFT: U_MEM_SRLATCH1.4 (1Q); also elsewhere on the board
unnamed: U_DECODE_SIGS1.1 (S0), U_MEM_SRLATCH1.11 (*3S1), U_MEM_SRLATCH1.12 (*3S2)
unnamed: U_DECODE_SIGS1.2 (S1), U_MEM_SRLATCH1.15 (*4S)
unnamed: U_DECODE_SIGS1.5 (S4), U_MEM_SRLATCH1.6 (*2S)
unnamed: U_DECODE_SIGS1.6 (S5), U_MEM_SRLATCH1.5 (*2R)
unnamed: U_DECODE_SIGS1.7 (S6), U_MEM_SRLATCH1.10 (*3R), U_MEM_SRLATCH1.14 (*4R)
unnamed: U_DECODE_SIGS1.10 (S9), U_MEM_SRLATCH1.1 (*1R)
unnamed: U_DECODE_SIGS1.11 (S10), U_MEM_SRLATCH1.2 (*1S1), U_MEM_SRLATCH1.3 (*1S2)
unnamed: U_MEM_SRLATCH1.7 (2Q), U_NOT_DECODE1.5
unnamed: U_MEM_SRLATCH1.9 (3Q), U_NOT_DECODE1.11
unnamed: U_MEM_SRLATCH1.13 (4Q), U_NOT_DECODE1.13
PHI8: U_DECODE_SIGS1.22 (A1); also elsewhere on the board
PHI16: U_DECODE_SIGS1.23 (A0); also elsewhere on the board
TEXTMODE: U_NOT_DECODE1.1; also elsewhere on the board
VCC: U_DECODE_SIGS1.24 (VCC), U_MEM_SRLATCH1.16 (VCC), U_NOT_DECODE1.14 (VCC); also elsewhere on the board
VIDBUS: U_NOT_DECODE1.12; also elsewhere on the board
VIDENABLE: U_NOT_DECODE1.10; also elsewhere on the board
VMLATCH: U_NOT_DECODE1.6; also elsewhere on the board

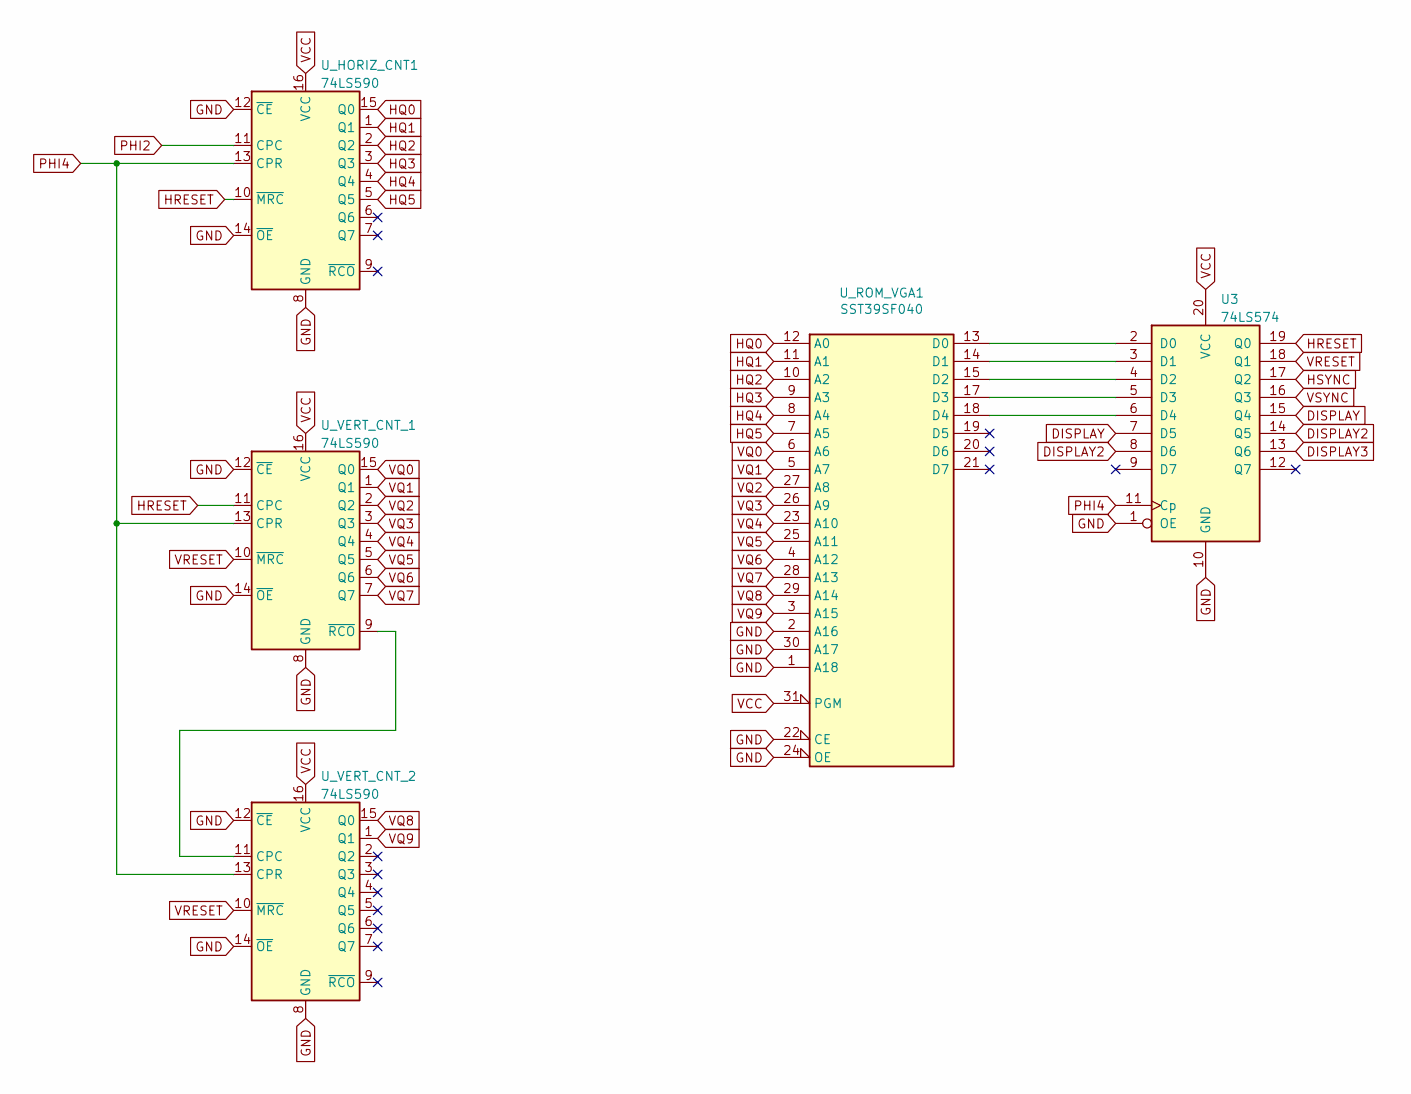
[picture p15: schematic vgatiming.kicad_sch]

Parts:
U3: 74LS574; DIP-20_W7.62mm_Socket
U_HORIZ_CNT1: 74LS590; DIP-16_W7.62mm_Socket
U_ROM_VGA1: SST39SF040; DIP-32_W15.24mm_Socket
U_VERT_CNT_1, U_VERT_CNT_2: 74LS590; DIP-16_W7.62mm_Socket

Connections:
DISPLAY: U3.7 (D5), U3.15 (Q4); also elsewhere on the board
DISPLAY2: U3.8 (D6), U3.14 (Q5)
DISPLAY3: U3.13 (Q6); also elsewhere on the board
GND: U3.1 (OE), U3.10 (GND), U_HORIZ_CNT1.8 (GND), U_HORIZ_CNT1.12 (~CE), U_HORIZ_CNT1.14 (~OE), U_ROM_VGA1.1 (A18), U_ROM_VGA1.2 (A16), U_ROM_VGA1.16 (GND), U_ROM_VGA1.22 (CE), U_ROM_VGA1.24 (OE), U_ROM_VGA1.30 (A17), U_VERT_CNT_1.8 (GND), U_VERT_CNT_1.12 (~CE), U_VERT_CNT_1.14 (~OE), U_VERT_CNT_2.8 (GND), U_VERT_CNT_2.12 (~CE), U_VERT_CNT_2.14 (~OE); also elsewhere on the board
HQ0: U_HORIZ_CNT1.15 (Q0), U_ROM_VGA1.12 (A0)
HQ1: U_HORIZ_CNT1.1 (Q1), U_ROM_VGA1.11 (A1)
HQ2: U_HORIZ_CNT1.2 (Q2), U_ROM_VGA1.10 (A2)
HQ3: U_HORIZ_CNT1.3 (Q3), U_ROM_VGA1.9 (A3)
HQ4: U_HORIZ_CNT1.4 (Q4), U_ROM_VGA1.8 (A4)
HQ5: U_HORIZ_CNT1.5 (Q5), U_ROM_VGA1.7 (A5)
HSYNC: U3.17 (Q2); also elsewhere on the board
unnamed: U3.2 (D0), U_ROM_VGA1.13 (D0)
unnamed: U3.3 (D1), U_ROM_VGA1.14 (D1)
unnamed: U3.4 (D2), U_ROM_VGA1.15 (D2)
unnamed: U3.5 (D3), U_ROM_VGA1.17 (D3)
unnamed: U3.6 (D4), U_ROM_VGA1.18 (D4)
VCC: U3.20 (VCC), U_HORIZ_CNT1.16 (VCC), U_ROM_VGA1.31 (PGM), U_ROM_VGA1.32 (VCC), U_VERT_CNT_1.16 (VCC), U_VERT_CNT_2.16 (VCC); also elsewhere on the board
VQ0: U_ROM_VGA1.6 (A6), U_VERT_CNT_1.15 (Q0); also elsewhere on the board
VQ1: U_ROM_VGA1.5 (A7), U_VERT_CNT_1.1 (Q1); also elsewhere on the board
VQ2: U_ROM_VGA1.27 (A8), U_VERT_CNT_1.2 (Q2); also elsewhere on the board
VQ3: U_ROM_VGA1.26 (A9), U_VERT_CNT_1.3 (Q3); also elsewhere on the board
VQ4: U_ROM_VGA1.23 (A10), U_VERT_CNT_1.4 (Q4); also elsewhere on the board
VQ5: U_ROM_VGA1.25 (A11), U_VERT_CNT_1.5 (Q5); also elsewhere on the board
VQ6: U_ROM_VGA1.4 (A12), U_VERT_CNT_1.6 (Q6); also elsewhere on the board
VQ7: U_ROM_VGA1.28 (A13), U_VERT_CNT_1.7 (Q7); also elsewhere on the board
VQ8: U_ROM_VGA1.29 (A14), U_VERT_CNT_2.15 (Q0); also elsewhere on the board
VQ9: U_ROM_VGA1.3 (A15), U_VERT_CNT_2.1 (Q1)
VRESET: U3.18 (Q1), U_VERT_CNT_1.10 (~MRC), U_VERT_CNT_2.10 (~MRC)
VSYNC: U3.16 (Q3); also elsewhere on the board

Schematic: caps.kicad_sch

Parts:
C18, C19, C20, C21, C22, C23, C24, C25, C26, C27, C28, C30, C31, C32, C33, C34, C35, C36, C37, C38, C39, C40, C41, C42, C43: 0.1µF; C_Axial_L3.8mm_D2.6mm_P7.50mm_Horizontal

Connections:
GND: C18.2, C19.2, C20.2, C21.2, C22.2, C23.2, C24.2, C25.2, C26.2, C27.2, C28.2, C30.2, C31.2, C32.2, C33.2, C34.2, C35.2, C36.2, C37.2, C38.2, C39.2, C40.2, C41.2, C42.2, C43.2; also elsewhere on the board
VCC: C18.1, C19.1, C20.1, C21.1, C22.1, C23.1, C24.1, C25.1, C26.1, C27.1, C28.1, C30.1, C31.1, C32.1, C33.1, C34.1, C35.1, C36.1, C37.1, C38.1, C39.1, C40.1, C41.1, C42.1, C43.1; also elsewhere on the board

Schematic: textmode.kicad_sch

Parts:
U_ROM_FONTS1: SST39SF040; DIP-32_W15.24mm_Socket
U_VID_TXTSHIFT1: SN74LS166AN; DIP-16_W7.62mm_Socket

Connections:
FS0: U_ROM_FONTS1.4 (A12); also elsewhere on the board
FS1: U_ROM_FONTS1.28 (A13); also elsewhere on the board
FS2: U_ROM_FONTS1.29 (A14); also elsewhere on the board
FS3: U_ROM_FONTS1.3 (A15); also elsewhere on the board
FS4: U_ROM_FONTS1.2 (A16); also elsewhere on the board
FS5: U_ROM_FONTS1.30 (A17); also elsewhere on the board
GFXMODE: U_VID_TXTSHIFT1.9 (*CLR); also elsewhere on the board
GND: U_ROM_FONTS1.1 (A18), U_ROM_FONTS1.16 (GND), U_VID_TXTSHIFT1.8 (GND); also elsewhere on the board
LOADSHIFT: U_VID_TXTSHIFT1.15 (SH/*LD); also elsewhere on the board
PHI16: U_VID_TXTSHIFT1.7 (CLK); also elsewhere on the board
SHIFTOUT_TXT: U_VID_TXTSHIFT1.13 (QH); also elsewhere on the board
TD0: U_ROM_FONTS1.13 (D0), U_VID_TXTSHIFT1.2 (A)
TD1: U_ROM_FONTS1.14 (D1), U_VID_TXTSHIFT1.3 (B)
TD2: U_ROM_FONTS1.15 (D2), U_VID_TXTSHIFT1.4 (C)
TD3: U_ROM_FONTS1.17 (D3), U_VID_TXTSHIFT1.5 (D)
TD4: U_ROM_FONTS1.18 (D4), U_VID_TXTSHIFT1.10 (E)
TD5: U_ROM_FONTS1.19 (D5), U_VID_TXTSHIFT1.11 (F)
TD6: U_ROM_FONTS1.20 (D6), U_VID_TXTSHIFT1.12 (G)
TD7: U_ROM_FONTS1.21 (D7), U_VID_TXTSHIFT1.14 (H)
TEXTMODE: U_ROM_FONTS1.22 (CE), U_ROM_FONTS1.24 (OE), U_VID_TXTSHIFT1.6 (CLKINH); also elsewhere on the board
VCC: U_ROM_FONTS1.31 (PGM), U_ROM_FONTS1.32 (VCC), U_VID_TXTSHIFT1.1 (SER), U_VID_TXTSHIFT1.16 (VCC); also elsewhere on the board
VL0: U_ROM_FONTS1.12 (A0); also elsewhere on the board
VL1: U_ROM_FONTS1.11 (A1); also elsewhere on the board
VL2: U_ROM_FONTS1.10 (A2); also elsewhere on the board
VL3: U_ROM_FONTS1.9 (A3); also elsewhere on the board
VL4: U_ROM_FONTS1.8 (A4); also elsewhere on the board
VL5: U_ROM_FONTS1.7 (A5); also elsewhere on the board
VL6: U_ROM_FONTS1.6 (A6); also elsewhere on the board
VL7: U_ROM_FONTS1.5 (A7); also elsewhere on the board
VQ0: U_ROM_FONTS1.27 (A8); also elsewhere on the board
VQ1: U_ROM_FONTS1.26 (A9); also elsewhere on the board
VQ2: U_ROM_FONTS1.23 (A10); also elsewhere on the board
VQ3: U_ROM_FONTS1.25 (A11); also elsewhere on the board

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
Board: 4 copper layers, 147 parts (74 on the bottom side), 253 nets, no tracks yet.

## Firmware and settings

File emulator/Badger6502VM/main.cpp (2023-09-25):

#include <iostream> 
#include <windows.h> 
#include <MddBootstrap.h>

int main(int, char**)
{
	// Take a dependency on Windows App SDK Stable.
	const UINT32 majorMinorVersion{ 0x00010000 };
	PCWSTR versionTag{ L"" };
	const PACKAGE_VERSION minVersion{};

	const HRESULT hr{ MddBootstrapInitialize(majorMinorVersion, versionTag, minVersion) };

	// Check the return code. If there is a failure, display the result.
	if (FAILED(hr))
	{
		wprintf(L"Error 0x%X in MddBootstrapInitialize(0x%08X, %s, %hu.%hu.%hu.%hu)\n",
			hr, majorMinorVersion, versionTag, minVersion.Major, minVersion.Minor, minVersion.Build, minVersion.Revision);
		return hr;
	}

	std::cout << "Hello World!\n";

	// Release the DDLM and clean up.
	MddBootstrapShutdown();
	return 0;
}

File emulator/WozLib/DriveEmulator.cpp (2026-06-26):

#include "DriveEmulator.h"
#if defined(__EMSCRIPTEN__)
#include "web_compat.h"
#else
#include <Windows.h>
#include <debugapi.h>
#endif
/*
* https://stackoverflow.com/questions/69369122/apple-iie-6502-assembly-accessing-disk
*
To turn on the drive, access $C0E9. To turn it off, access $C0E8.
The effect of turning off the drive will be delayed by about a second.

To switch to drive 2, access $C0EB. To switch to drive 1, access $C0EA.

To move the head, think of it as being attached to a wheel which is
attached to a hand on a clock face. The hand will point at 12:00 when
the head is at any even numbered, track, and at 6:00 when it is on any
odd numbered track. Reading $C0E1, $C0E3, $C0E5, or $C0E7 will turn on a coil
that pulls the hand toward 12:00, 3:00, 6:00, or 9:00. Accessing the
next lower address will turn off the coil.
Move the head by turning on a coil 90 degrees from the wheel's current position,
waiting awhile, turning that coil off and turning on the next one, etc.

To see if a drive is attached, read $C0EC a few times and see if the value changes.
If not, no drive is attached. If a drive is known to exist, use a two-instruction loop
to read $C0EC until the high bit becomes set. If one a four-cycle instruction
was used for the read, and a two-cycle branch-not-taken once high bit became set
(e.g. wait293: LDX $C0EC / BPL wait293). To ensure that one reads every byte,
ensure that the CPU executes at least 12 and at most 24 cycles before the next time
the sequence is executed. Taking less than 12 cycles may yield duplicate reads.
Taking more than 24 may cause bytes to be skipped.

To start writing data, write any value to $C0ED, then write the first byte
value to $C0EF and immediately read $C0EC (ignore the value written).
One must then execute exactly 24 cycles of other code,
a write of the next byte to $C0ED, an immediate read of $C0EC, etc.
When done, read $C0EE.
*/

DriveEmulator::DriveEmulator()
{
}

DriveEmulator::~DriveEmulator()
{

}

void
DriveEmulator::AddCycles(uint32_t cycles)
{
	char buf[255];

	_cycles += cycles;
	_D[0].AddCycles(cycles);
	_D[1].AddCycles(cycles);
	
	if (_motorStarting != 0)
	{
		if (_cycles - _motorStarting >= ONE_SECOND)
		{
			_motorStarting = 0;
			_motorRunning = true;
		}

		_activeDisk = _pendingActiveDisk;
	}
	else if (_motorStopping != 0)
	{
		if (_cycles - _motorStopping >= ONE_SECOND)
		{
			_motorStopping = 0;
			_motorRunning = false;
			GetActiveDisk()->SetSpinning(false);
		}
		_activeDisk = _pendingActiveDisk;
	}

	if (_motorRunning)
	{

		uint8_t bit = 0;
		while (GetActiveDisk()->GetNextBit(bit))
		{
			_shiftTemp = _shiftTemp << 1;
			_shiftTemp |= bit;

			if (_shiftTemp & 0x80)
			{
				_shiftRegister = _shiftTemp;
				_shiftTemp = 0;

				//sprintf_s(buf, _countof(buf), "copy: $%02x, %d\r\n", _shiftRegister, (uint32_t)_cycles - _lastCopy);
				//OutputDebugStringA(buf);
				_lastCopy = _cycles;
			}
		}

		if (_cycles - _lastCopy >= BIT_HOLD)
		{
			if (_shiftRegister != 0)
			{
				//OutputDebugStringA("Lost Byte\r\n");
			}
			_shiftRegister = 0;
		}


#if 0
		// in read mode and the motor is running, shift in bits
		uint8_t bitCount = 0;
		uint8_t bits = GetActiveDisk()->GetBits(bitCount);

		if ((_shiftRegister & 0x80) && bitCount > 0)
		{
			char buf[255];
			sprintf_s(buf, _countof(buf), "%02x ", _shiftRegister);
			_debugString.append(buf);
	
			if (_debugString.size() > 64)
			{
				_debugString.append("\r\n");
				OutputDebugStringA(_debugString.c_str());
				_debugString.clear();
			}

			_shiftRegister = 0;
		}

		if (bitCount > 0)
		{
			_shiftTemp = _shiftTemp << bitCount;
			_shiftTemp |= bits;

			if (_shiftTemp & 0x80)
			{
				_shiftRegister = _shiftTemp;
				_shiftTemp = 0;
			}

			//_shiftRegister = _shiftRegister << bitCount;
			//_shiftRegister |= bits;
		}
#endif
	}
}

WozDisk *
DriveEmulator::GetActiveDisk()
{
	return &_D[_activeDisk];
}

WozDisk *
DriveEmulator::GetDisk(uint8_t index)
{
	return &_D[index % 2];
}

uint8_t DriveEmulator::Read(uint8_t address)
{
	char buf[255];

	switch (address & 0xF)
	{
	case 0x0:	// Phase 0 off
		GetActiveDisk()->PhaseOff(0);
		break;
	case 0x1:	// Phase 0 on  
		GetActiveDisk()->PhaseOn(0);
		break;
	case 0x2:	// Phase 1 off
		GetActiveDisk()->PhaseOff(1);
		break;
	case 0x3:	// Phase 1 on
		GetActiveDisk()->PhaseOn(1);
		break;
	case 0x4:	// Phase 2 off
		GetActiveDisk()->PhaseOff(2);
		break;
	case 0x5:	// Phase 2 on
		GetActiveDisk()->PhaseOn(2);
		break;
	case 0x6:	// Phase 3 off
		GetActiveDisk()->PhaseOff(3);
		break;
	case 0x7:	// Phase 3 on
		GetActiveDisk()->PhaseOn(3);
		break;
	case 0x8:	// Motor off
		_motorStarting = 0;
		_motorStopping = _cycles;
		break;
	case 0x9:	// Motor on
		_motorStopping = 0;
		_motorStarting = _cycles;
		GetActiveDisk()->SetSpinning(true);
		break;
	case 0xA:	// Select drive 1	
		_pendingActiveDisk = 0;
		if (_motorRunning && _activeDisk != _pendingActiveDisk)
		{
			_motorStopping = _cycles;
		}
		break;
	case 0xB:	// Select drive 2
		_pendingActiveDisk = 1;
		if (_motorRunning && _activeDisk != _pendingActiveDisk)
		{
			_motorStopping = _cycles;
		}
		break;
	case 0xC:	// Q6L - Reading this value will return drive bits on the current track
		UpdateQ(false, _Q7);


		if (false == _Q6 && false == _Q7)
		{

			//sprintf_s(buf, _countof(buf), "read: %d, %d, %d\r\n", (uint32_t)_cycles, (uint32_t)_cycles - _lastRead, (uint32_t)_cycles - _lastCopy);
			//OutputDebugStringA(buf);
			_lastRead = _cycles;

			uint8_t result = _shiftRegister;

			if (result & 0x80)
			{
				//sprintf_s(buf, _countof(buf), "$%02x, %d, %d\r\n", result, (uint32_t)_cycles - _lastByte, (uint32_t)_cycles - _lastCopy);
				//OutputDebugStringA(buf);
				_shiftRegister = 0;
				_lastByte = _cycles;
			}
			return result;
		}
		break;
	case 0xD:	// Q6H
		UpdateQ(true, _Q7);
		break;
	case 0xE:	// Q7L
		UpdateQ(_Q6, false);
		if (_Q6)
		{
			return _statusRegister;
		}
		break;
	case 0xF:	// Q7H
		UpdateQ(_Q6, true);
		break;
	}

	return 0;
}
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

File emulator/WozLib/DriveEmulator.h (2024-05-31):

#pragma once

#include "WozDisk.h"
#include <string>

class DriveEmulator
{
public:
	DriveEmulator();
	~DriveEmulator();

	uint8_t Read(uint8_t address);
	void Write(uint8_t address, uint8_t data);
	void AddCycles(uint32_t cycles);
	void StartMotor();
	void StopMotor();
	void UpdateQ(bool Q6, bool Q7);

	WozDisk* GetActiveDisk();
	WozDisk* GetDisk(uint8_t i);

private:
	bool		_Q6 = false;
	bool		_Q7 = false;

	uint8_t		_statusRegister = 0;
	uint8_t		_shiftRegister = 0;
	uint8_t     _shiftTemp = 0;


	WozDisk		_D[2];
	uint8_t		_pendingActiveDisk = 0;
	uint8_t		_activeDisk = 0;

	uint64_t	_cycles = 0;
	uint64_t    _lastCopy = 0;
	uint64_t    _lastRead = 0;
	uint64_t    _lastByte = 0;

	uint32_t	_cycleIncrease = 0;

	uint64_t    _motorStarting = 0;
	uint64_t    _motorStopping = 0;
	bool        _motorRunning = false;

	bool        _byteRead = false;

	//std::string _debugString;
};

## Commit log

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2023-09-16 remove ftdi references fix build errors
    [via.cpp]
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2023-10-10 move some of the logic to PLD, move device range from C1XX to CX00 update device labels to be more correct update PLD
    [3ric.kicad_sch, address_decoder.kicad_sch, banking.kicad_sch]
2023-12-19 significant emulator threading and perf fixes
    update fontgen tool to match apple II font
    [via.cpp]
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2024-03-30 upgraded to kicad 8, updates to schematic - added snes controllers, mouse port, many fixes
    [3ric.kicad_sch, Communication_sch.kicad_sch, LowRes.kicad_sch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]
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2024-05-28 not working, but stashing changes
    [DriveEmulator.cpp, DriveEmulator.h]
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2024-09-23 update schematic with corrections found via virutal wiring
    [banking.kicad_sch, softswitches.kicad_sch]
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2026-06-05 Use package-relative paths for data files and add migration guide
    - Replace hardcoded absolute paths with package-relative resolution using
    Windows::ApplicationModel::Package::Current().InstalledLocation()
    - Copy writable SD card image to LocalFolder on first launch (package
    install directory is read-only)
    - Add build targets to decompress sd.zip and copy data files to output
    - Add WinAppSDK 1.3-to-1.6 migration guide documenting pitfalls and solutions
2026-06-26 web: emulate the micro-SD card and fix the 4:3 display
    Wire the bit-banged SPI micro-SD card (MockMicroSD) into the WebAssembly build so the ROM's FAT32 DOS shell can mount and read the card, and correct the canvas aspect ratio to 4:3.
    SD card:
    - Add an Emscripten branch to MockMicroSD (pch.h, MappedFile, SDCard) backing the 2GB FAT32 image with a lazily-allocated sparse sector map; the Win32 mmap path is preserved under #else. All additive and guarded by __EMSCRIPTEN__.
    - make_sd_sparse.py streams emulator/Data/sd.zip into data/sd.sparse (~11.5MB SDSP container of the ~23k non-zero sectors); build.ps1 generates it on first build.
    - web_bridge pumps the SPI state machine on VIA1 port-A w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
2026-06-27 Fix case-sensitive includes that broke the Linux/WASM build
    On Linux (case-sensitive FS) the Emscripten build failed with
    "fatal error: 'timing.h' file not found": the headers on disk are
    Timing.h and WozFile.h, but the sources included them as "timing.h"
    and "wozfile.h". Windows (case-insensitive) only warned, so the local
    build passed while GitHub Actions failed. Match the include case to the
    real filenames; harmless on Windows, required on Linux.
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2026-07-09 Add Opus->3ric codegen toolchain and hosted .PRG loader
    Headless build/run/test pipeline that turns generated 65C02 source into a
    card-ready .PRG and validates it against the project's WASM emulator, plus a
    browser loader so the hosted emulator can run a raw .PRG like BRUN.
    codegen/tools:
    - asm6502.mjs: dependency-free two-pass 65C02/6502 assembler (+ tests)
    - harness.cjs: boots the WASM core, loads a program, runs it, captures
    serial/text-screen/registers, and detects halt (BRK->monitor, WAI, idle,
    timeout)
    - run6502.mjs: CLI that assembles/loads, runs, applies --expect-* checks,
    writes the .PRG, and emits a pass/fail verdict
    - gen_platform_ref.mjs: generates the platform reference f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
2026-07-09 JUNGLE QUEST: playable core (physics, log hazard, treasures, timer, HUD)
    Original hi-res jungle platformer for the 3ric. Run/jump with 8.8 fixed-point
    gravity, pit and ground-edge collision, a rolling-log hazard, three collectible
    gems (+2000 BCD each), a 60-second countdown, and win / game-over / time-up end
    screens that restart on SPACE. Headless tests cover the engine primitives,
    physics, hazard collision, treasure pickup/score, win, and timer.
    Original art, levels, name, and code; only genre mechanics are reused.
2026-07-10 JUNGLE QUEST: 4-screen world, vine swing, and title screen
    Extends the original jungle platformer beyond the single-screen core:
    - M6 flip-screens: a four-area world driven by per-screen level tables
    (pit width, rolling-log hazard, vine). Walk off either edge to cross to
    the neighbour; the HUD shows the current AREA. Six gems are now scattered
    across the world and tagged by screen.
    Fixes a symbol collision where the STATE field `screen` clashed with the
    `SCREEN` ($2000) constant under the assembler uppercasing (which made
    clear_screen wipe game state) -> renamed the field to `curscr`.
    - M7 vine-swing: jumping into the vine on the wide-pit screen latches on and
    swings the hero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
2026-07-10 ROCK STORM M1: XOR vector engine + rotated ship draw_poly (headless-tested)
    Original asteroids-genre vector shooter for 3ric. M1 delivers the rendering
    core: mixed hi-res mode, XOR Bresenham line with clipping, and draw_poly that
    XOR-renders rotated polygons from precomputed 32-angle ship tables. All headless
    tests pass; 8-ship rotation fan renders correctly.
    Fixed a zero-page collision with the Apple II monitor (engine scratch overlapped
    the COUT/RDKEY vectors at \-\); relocated all working scalars to an absolute
    VARS block at \, keeping only indirect pointers in zero page.
2026-07-10 ROCK STORM M2: ship physics — rotate/thrust/inertia/wrap (headless-tested)
    Adds the object struct at \ (16.8 fixed position, 8.8 velocity, heading,
    DRAWN flag) and the real game loop replacing the M1 fan. Ship rotates (A/D),
    thrusts along its heading with true inertia (no friction), integrates in 8.8
    fixed point, and centre-wraps on both axes. Erase-redraw with a per-object DRAWN
    flag leaves no trail. Keyboard uses hold-timers so single-key Apple II reads plus
    auto-repeat feel like simultaneous rotate/thrust/fire.
    Bumped thrust ACC 14->40 in rockgen for a responsive feel. All M1+M2 headless
    tests pass (init, first-frame draw, rotation, thrust+inertia, wrap, no-trail).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
2026-07-10 ROCK STORM M3: bullets (fire/travel/wrap/expire, auto-fire cadence)
    Add the bullet subsystem sharing the generic object struct: fire from the
    ship nose along the heading (baked muzzle velocity), integrate/wrap via the
    shared integrate_obj/wrap_obj, life countdown, XOR erase-redraw, and a
    fire-cooldown cadence capped at NBULLET simultaneous shots.
    Fix a symbol collision: the variable fire_cd uppercased to the same symbol
    as the FIRE_CD constant, so stores landed on zero page \ and the cooldown
    never worked; renamed the variable to firecd.
    All M1-M3 headless tests pass.
2026-07-10 ROCK STORM M6: game flow (waves, HUD, attract/game-over/restart)
    State machine (attract/play/over), escalating waves (4..8 rocks), text-page
    HUD (SCORE/SHIPS + title + GAME OVER). Because the harness BRK monitor dumps
    registers onto the text page, hud_snapshot copies the four HUD rows to safe
    RAM (\) before the brk so tests can read them. Fixed poll_space strobe
    clear to mirror read_input. All A-AE headless tests pass.
2026-07-10 ROCK STORM M7: thrust flame
    Draw a small XOR flame triangle out the ship's tail while the engine is
    firing, as its own erase-redraw object (fldrawn flag) so it can blink on
    and off without disturbing the ship. New FLAMEX/FLAMEY angle tables from
    rockgen.mjs and a set_flame_vp helper. Renamed the flame's local return
    label to avoid an uppercased-symbol clash with do_fire's df_ret. Added
    test AF (flame lights under thrust, clears with no trail). All A-AF pass.
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2026-07-10 STAR SWARM M5: bolt/alien collisions, rank scoring (BCD), alien bombs + cannon hits, lives (tests)
2026-07-10 STAR SWARM M7: attract/play/over flow, waves, respawn, HUD; fix const/var symbol collision
    Adds the game-flow state machine (title -> play -> game over), wave refills, cannon respawn on hit and game-over on last life or swarm landing, live bomb cadence, and a text HUD (score/lives/wave, title, game over, high score).
    Also fixes a latent assembler symbol collision: the constants BOMBCD/UFOCD uppercased to the same symbols as the bombcd/ufocd variables, so 'lda #BOMBCD' loaded the low byte of the variable address instead of the intended cadence. Renamed the constants to BOMBGAP/UFOGAP.
2026-07-10 codegen: document assembler case-insensitive symbol collision
    Symbols fold to uppercase, so a same-named constant and variable (e.g. BOMBCD/bombcd) merge into one symbol and the later definition silently wins, corrupting #CONSTANT immediates. Warn about it in the generator guide and at the symbol-definition site in the assembler.
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2026-07-11 Convert Life codegen program to full-screen lo-res colour graphics
    Life's world is a 40x48 cell grid, which is exactly a full-screen lo-res
    field (40 cols x 48 rows of blocks) -- so the old hi-res renderer gave zero
    resolution benefit while carrying build_lines, the CBASE_L/H address tables,
    LINEBUF, and a per-scanline quad-blit. Switch Life to full-screen lo-res:
    identical on-screen scale, far less code, and colour.
    - life.s: replace the hi-res render (build_lines / CBASE_L/H / LINEBUF /
    blit_line) with a compact lo-res renderer -- for each of the 24 text rows
    pack the two vertically-stacked cells into one byte (low nibble = upper/even
    row, high nibble = lower/odd row; green = alive)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
2026-07-11 Enlarge Minefield board from 12x12 to 16x16
    Minefield filled only the center of the 40x24 text screen. Grow it to a 16x16 field (256 cells, 40 mines -- the classic Minesweeper 'intermediate' board), the largest grid the single-byte cell index (ROWOFF[row]+col, max 255) can address without a wider-index rewrite.
    mines.s: W/H=16, CELLS=256, MINES_N=40, GRIDLEFT=12, 16-entry ROWOFF. The two all-cell scan loops (clear_arrays, check_win) now terminate on the inx wrap at 256 instead of 'cpx #CELLS' (256 doesn't fit a byte immediate). Also fix mine placement: the RNG drew both row and column from seedL's low nibble, whose short sub-cycle only reached 32 of 256 cells, so 40 mines could never be pla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
2026-07-11 Tighten Minefield tests to exact full-board assertions
    Address the GPT code-review panel finding that the >200/>240 thresholds
    could pass a partially-broken 16x16 board. Boot now asserts the grid region
    (rows 4-19, cols 12-27) is exactly 255 hidden dots + 1 cursor with no blanks;
    flood asserts exactly CELLS-1 (255) revealed. Drop the now-unused count/joined
    helpers.
2026-07-11 Add dual-license, NOTICE, FUNDING, and a real README
    Establish 3ric's licensing and community front door:
    - LICENSE: MIT for original software.
    - LICENSE-CC-BY-SA-4.0.txt: CC BY-SA 4.0 for original hardware designs and docs.
    - NOTICE: authoritative license map + third-party carve-outs (sdlib Apache-2.0, FatFs license, KiCad RP-Pico CC-BY-SA) and provenance disclosures (Microsoft BASIC in the ROM; Apple II disk/loderun images used as test fixtures).
    - .github/FUNDING.yml: GitHub Sponsors button (ebadger) + commented templates.
    - README.md: rebuilt as a real front door (live-demo CTA, features, browser quick-start, build-from-source, mermaid architecture, repo map, contributing, build ser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
2026-07-11 web: add Share/Remix deep links to the browser editor
    Add a Share button to the in-browser 65C02 assembler that copies a
    self-contained link to the current program: unmodified built-in samples
    link as the short ?src=programs/<name>.s, and edited or hand-written
    source is embedded inline as URL-safe base64 in ?code=. Both forms carry
    &org=<hex> when the source has no .org directive. Opening a ?src=/?code=
    link auto-runs the program and shows a "remixing a shared program"
    banner, turning every shared program into an editable starting point.
    Spec-first: documents the loop in specs/WEB-CLIENT.md and web/README.md.
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2026-07-12 Rock Storm: page-flip double buffering + faster vector renderer
    Eliminate the heavy flicker and roughly halve per-frame cost.
    Double buffering: draw the whole scene on the hidden hi-res page
    ($2000/$4000) and text-HUD page ($400/$800), then flip the display
    soft switch (LOWSCR/HISCR). The player never sees a half-drawn frame.
    A pgoff/txtoff offset steers clear_screen, plotcur, and the HUD writers
    at the hidden page; flip_show alternates it each frame from sg_loop.
    This replaces the old erase-by-redraw pass (four full XOR erase passes
    per frame, ~175k cyc) with a single clear.
    Performance:
    - 8x-unrolled clear_screen: 90,754 -> 62,017 cyc (-32%).
    - Inlined plotcur/stepx/stepy into the per-pi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
2026-07-12 Fix ROCK STORM page-2 self-corruption + startup flicker
    Relocate the program from $0800 to $0C00. The page-flip double buffer
    puts the 4-row HUD on text page 2 ($800-$BFF) whenever hi-res page 2 is
    displayed, which overlapped the program's own code at $0800 and
    corrupted it in the live loop. $0C00 sits just above text page 2, still
    below hi-res $2000 (130 bytes headroom).
    Also call flip_show once after enter_attract so the very first frame is
    drawn on the hidden page, removing a one-frame startup teardown on the
    visible page.
    Addresses the two-model review panel on PR #33 (GPT reviewer: BLOCK
    self-corruption; Gemini reviewer: MEDIUM startup flicker). Gemini's LOW
    (dead o_drawn) is overridd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
2026-07-12 Blank page-1 text HUD in video_init (clean first frame)
    The startup flip_show leaves hi-res page 1 displayed while the first
    frame draws on the hidden page 2. video_init cleared only the hi-res
    area ($2000-$3FFF), so the mixed-mode text HUD ($400-$7FF) briefly
    showed stale garbage for that first frame. Clear it in video_init
    (build_rows leaves txtoff=0, so hud_clear targets page 1).
    Addresses the Gemini reviewer's MEDIUM finding on PR #33.
    Verified: rocks.test.mjs ALL PASS; page-1 HUD blank after video_init;
    code image intact; both pages render; 4993 bytes @ $0C00 (127 B headroom).
2026-07-12 bricks: give the ball horizontal momentum and a playable pace
    The BRICK BUSTER ball only ever moved vertically (served straight up, and the paddle bounce forced ballDC=0), and it ran ~190 steps/sec at the native 1x clock - unplayably fast.
    - serve_ball now serves on a random left/right diagonal so play always carries horizontal momentum.
    - sb_paddle imparts english: striking the paddle's left half sends the ball left, the right half sends it right (ballDC = -1/+1), instead of zeroing it.
    - PACE/DLY retuned (140/120) to ~15 ball steps/sec at 1x; the paddle still advances one cell per step, matching the ball's horizontal drift so it can always track it.
    Both bricks.prg images reassembled;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
2026-07-12 bricks: reflect off the struck brick face (fix sideways tunnelling)
    The second-model review panel (Gemini) flagged that with the ball now moving
    diagonally, hit_brick only ever flipped the vertical velocity. A ball striking a
    brick's side face kept its horizontal direction and bored sideways through the
    brick mass. hb_bounce now probes the two orthogonal neighbours the ball squeezes
    past and reflects off the face actually struck: vertical neighbour solid -> flip
    DR (top/bottom), horizontal neighbour solid -> flip DC (side), both/neither ->
    corner (flip both). Adds bricks.test.mjs Section E covering the serve angle,
    paddle english, side-wall bounce, and brick side/bottom reflections, and
    docu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
2026-07-12 Rock Storm: 8-bit Bresenham error math (5.0 fps, pixel-identical)
    The per-pixel line-drawing inner loop kept its Bresenham error terms
    (lerr/e2/s1/s2) as 16-bit signed. Every drawn edge is a draw_poly polygon
    edge, and the only polygon sources are ROCKX/ROCKY (r<=18), SHPX/SHPY
    (r<=7) and FLAMEX/FLAMEY (r<=9), so |dx|,|dy| <= 36 for every line drawn.
    An exhaustive simulation over (dx,dy) in [0,40]^2 -- the error recurrence
    is a pure function of dx,dy, independent of screen position -- bounds every
    term at <=117 < 127, so the whole error term provably fits in a signed byte.
    Drop all high-byte ops (lerrh/e2h/s1h/s2h + their adc/sbc/rol) and the
    s1/s2 stores; branch directly on the N/Z flags o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
2026-07-13 Add 8-lesson 65C02 game dev tutorial series + live-site entry points
    An outline-first, browser-first tutorial series that teaches 65C02 game programming on the 3ric. Each lesson pairs a markdown page with a small, fully-commented .s program that auto-stages to the live site and is one-click runnable via ?src=programs/<name>.s. All eight programs are verified headlessly on the cycle-honest emulator.
    Lessons: 1 hello/loop/print (text), 2 text-screen drawing, 3 input+game loop, 4 lo-res color + PLOT, 5 motion/collision (bouncing ball), 6 LFSR randomness + scoring (catch-the-food), 7 capstone Space Invaders (lo-res, state machine + fleet-as-data), 8 hi-res starfield + where-to-go-next reading l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
2026-07-13 Address code-review panel findings on tutorial series
    Fixes from the mandatory two-model review of PR #36:
    - tut7_invaders: fix bullet tunneling. hitcheck now matches an alien on the
    bullet's row OR the row just below (ay==by || ay==by+1), so aliens on odd Y
    rows are no longer skipped by the 2px/frame bullet (Gemini BLOCK).
    - tut6_catch: cap score at 99 so the two-digit HUD never renders ":0" (GPT).
    - Ship verify_run.cjs / verify_keys.cjs into codegen/tools/ and fix the
    Verify-command paths in lessons 5-7, which referenced scripts that were not
    in the repo (GPT).
    Verified: assembler unit tests, web boot smoke, and all four locked verify
    checks pass; added empirical proof that an od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
2026-07-13 Validate entry address; document .woz export in status
    - wozgen.mjs: reject a non-integer or out-of-range entry address in
    buildBootableWoz before masking it (GPT code-review panel nit) so a bad
    caller fails loudly instead of building a disk that boots to a truncated
    address. UI callers pass the assembled .org, so behaviour is unchanged.
    - status/SYSTEM-STATUS.md: list web/test_woz_download.cjs in the verification
    commands and note the .PRG/.woz export on the in-browser assembler.
2026-07-13 web: add story.html landing page telling the 3ric build story
    New web/story.html: an engaging, first-person narrative of 3ric and the wider
    hardware-hacking journey - the Ben-Eater-breadboard origin, the Ultima IV quest,
    the 'am I building an Apple II?' twist (VGA artifact color, PLL timing, Apple II
    language-card banking), breadboard -> PCB, the Badger6502 Pico kit/emulator,
    ESP32/Atari-2600 experiments and the cross-platform Lode Runner saga, then the
    payoff and a CTA into the live browser emulator. Each chapter links its YouTube
    episode via a lite-embed facade (static thumbnail -> youtube-nocookie iframe on
    click, so no third-party player loads until the visitor opts in).
    - Wire a 'Story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
2026-07-13 Correct Apple II framing to 'compatible, original design'; add .woz dev-kit angle
    Per author feedback: 3RIC is an original design (the schematic is not an Apple
    II), close enough in behavior to run much Apple II software but not all -- its
    modern I/O (PS/2 keyboard/mouse, SNES controllers, SD card) means a significantly
    different ROM and no Applesoft BASIC, so some games don't run. Reword the hero,
    title/OG meta, and Chapter 3 accordingly (it 'speaks Apple II' rather than 'is'
    one). Also surface a real web-client feature: build/assemble in the browser and
    Download .woz to get a bootable disk image that boots on a real Apple II, making
    3RIC an Apple II dev kit. Update specs/WEB-CLIENT.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
2026-07-13 Add curated real-time Reddit timeline to story page Community section
    Replaces the deferred Reddit stub with a 16-post r/beneater/maker-community timeline (2020-2025), each linking to its permalink: day-one breadboard, the stated Lode Runner goal, first run, Tom's Hardware writeup, ESP32/XAC accessibility, Zork-on-Pico, Ultima IV finished, and 'the conclusion.' Sourced from u/ebadger1973's post history via the pullpush.io archive (Reddit hard-blocks direct automated access). Swaps the stub card for a 'u/ebadger1973' profile card and updates specs/WEB-CLIENT.md to match.
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2026-07-13 Address review-panel findings on BLOCK DROP gamepad
    Follow-up to the SNES gamepad support, resolving findings from the
    two-model review panel (GPT gpt-5.5 + Gemini gemini-3.1-pro-preview):
    - go_wait: throttle the PTRIG strobe with gpPoll so the game-over wait
    loop no longer fires the NMI pad scan on every spin (it was pinning the
    CPU and hammering the controller latch); the keyboard is still polled
    every spin.
    - read_key/rk_kbd: guard with gover so a pad soft-drop that tops the well
    out does not then act on the keyboard on a dead board.
    - read_pad: give the D-pad Left/Right auto-shift (DAS) -- a tap moves one
    cell, a hold repeats after an initial delay -- instead of repeating at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
2026-07-13 Revalidate in-browser editor sample-source fetches so deploys aren't masked by browser cache
    The Assemble & Run editor loads sample sources from static programs/<name>.s
    files served by GitHub Pages with Cache-Control: max-age=600. A repeat visitor
    whose browser cached a source before a deploy kept seeing the stale version in
    the sample dropdown (and via ?src= share links) for up to 10 minutes, with no
    hard refresh. Fetch these sources with { cache: 'no-cache' } so the browser
    issues a conditional request and picks up freshly deployed sources immediately
    (there is no service worker; GitHub Pages purges its CDN on deploy, so the
    revalidation returns the new source). Binary .prg/wasm/data load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
2026-07-13 Speed up Rock Storm rendering
    Replace the repeated divide-by-seven loop and indirect page clear with bounded arithmetic and page-aware absolute stores. Remove the redundant frame delay, regenerate both PRGs, and enforce the cycle budget and page-clear behavior in the game suite.
2026-07-14 Rebuild Jungle Quest as Sunstone Run
    Replace the flat four-screen prototype with a six-screen action platformer, responsive traversal, authored hazards, glyph progression, checkpoints, and a temple finale. Add full-route gameplay coverage and byte-lock both shipped PRGs to source.
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2026-07-17 Fix debugger wake and ROM mapping
    Honor breakpoints when a masked IRQ releases WAI, and restrict ca65 source correlation to addresses backed by read-only ROM segments.
    [vm.h]
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2026-09-16 Further optimize live ball rasterization without changing its pixels
    Keep line coordinates in registers, batch polygon segment checks, tighten span and visibility operations, and unroll bounded background restoration. Preserve the full live mesh and add independent full-raster and boundary coverage.
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2026-09-22 Retune SUNSLING pacing for the current ROM scan
    Account for the updated ROM's controller-scan overhead without relaxing the 200-cycle frame tolerance. Cover idle, one-pad, two-pad and released inputs alongside the existing full-load combat stress suite. Keep VM, ROM, and challenge baseline unchanged.
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2026-09-23 Add Gemini 3.8 Flash 2-formant speech synthesizer for 3RIC Talks v1
    Implements an original 65C02 rule-based text-to-speech engine targeting
    slot-4 dual AY-3-8910 Mockingboard on 3RIC. Implements standard TTS_INIT,
    TTS_SPEAK, and TTS_INPUT ABI with 42 phonemes across voiced formant,
    unvoiced noise, and voiced fricative/plosive models.
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2026-10-01 Fix VIA timer counting after reset
    Retain timer counters and latches across reset, and arm timeout events independently from counter clocks. Cover cold 6502 probes, warm resets, one-shot/free-run behavior, and PB6 clocks in native and WASM regressions.
    [via.cpp]
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

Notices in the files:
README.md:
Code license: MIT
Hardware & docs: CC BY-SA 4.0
